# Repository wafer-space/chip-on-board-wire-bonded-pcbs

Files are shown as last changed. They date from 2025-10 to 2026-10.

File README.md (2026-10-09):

# Chip-on-Board Wire-Bonded PCBs

> **Status:** Work in Progress

This repository serves as the primary workspace and documentation hub for [**wafer.space**](https://wafer.space).

Our current padframe and wirebonding layouts follow the [**Tiny Tapeout**](https://tinytapeout.com/) convention of 74 pads.
All ground (GND) connections are tied together in the **Default Breakout COB package**.



---

## First Run

[**wafer.space**](https://wafer.space) completed its **successful first run**, delivering working chip-on-board (COB) packages to customers. The boards below are the actual COB parts that were wire-bonded and shipped as part of Run 1 — real silicon, packaged and ready to drop into a breakout motherboard.

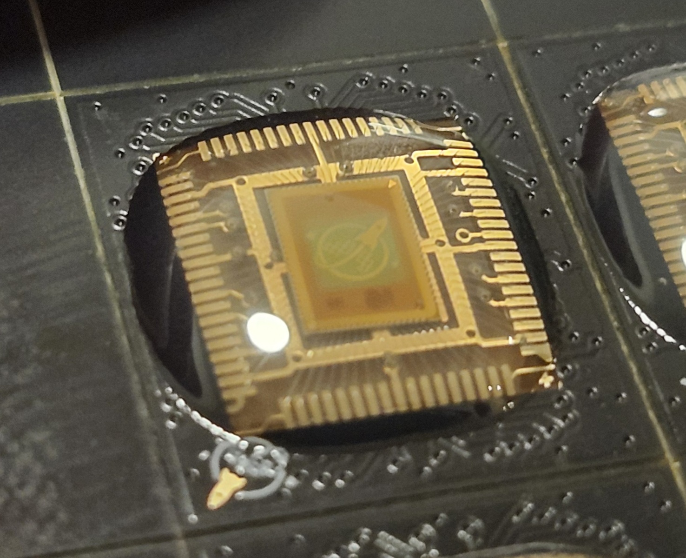
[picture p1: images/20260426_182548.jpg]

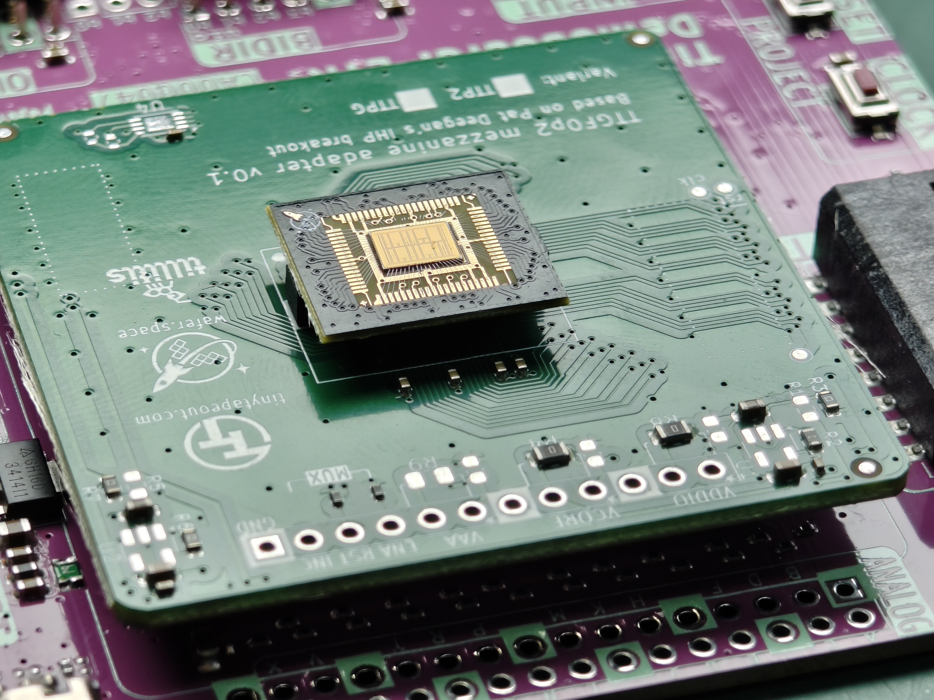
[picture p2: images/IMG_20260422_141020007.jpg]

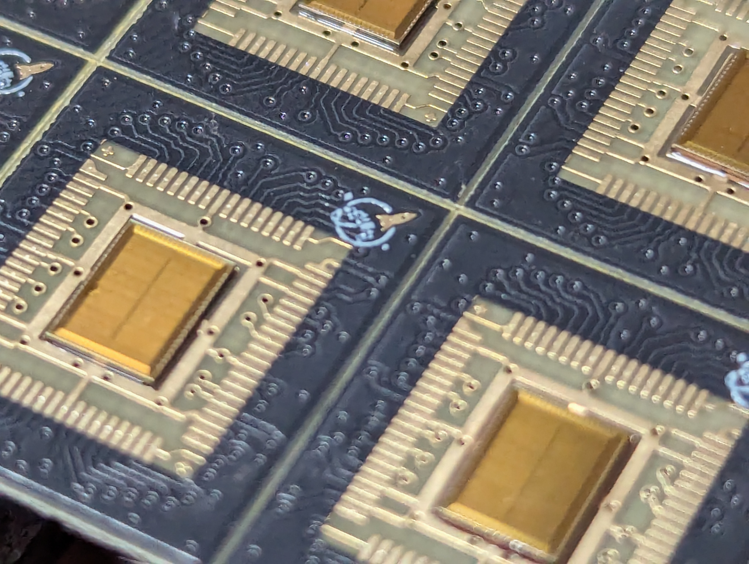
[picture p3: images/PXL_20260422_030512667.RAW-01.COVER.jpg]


See [**Run 1**](./run-1/README.md) for the full padframe reference, pinouts, and design requirements behind these parts.

---

## Run Documentation

Pinouts, connector choices, and footprint dimensions are **run-specific** and documented per run.

* [**Run 1**](./run-1/README.md) — padframe reference / pinouts, example COB layout, mezzanine connectors, and design requirements
  * [Wirebonding detail and design rules](./run-1/wirebonding/README.md)
  * [Example motherboards](./run-1/motherboards/README.md)

---

## Boards

<!-- AUTO-GEN:START -->
<!-- Generated by .github/scripts/gen_docs.py on release. Edits between the AUTO-GEN markers will be overwritten. -->

*Generated for release **unreleased** on 2026-10-09.*

| Run | Board | Preview |
| --- | --- | :---: |
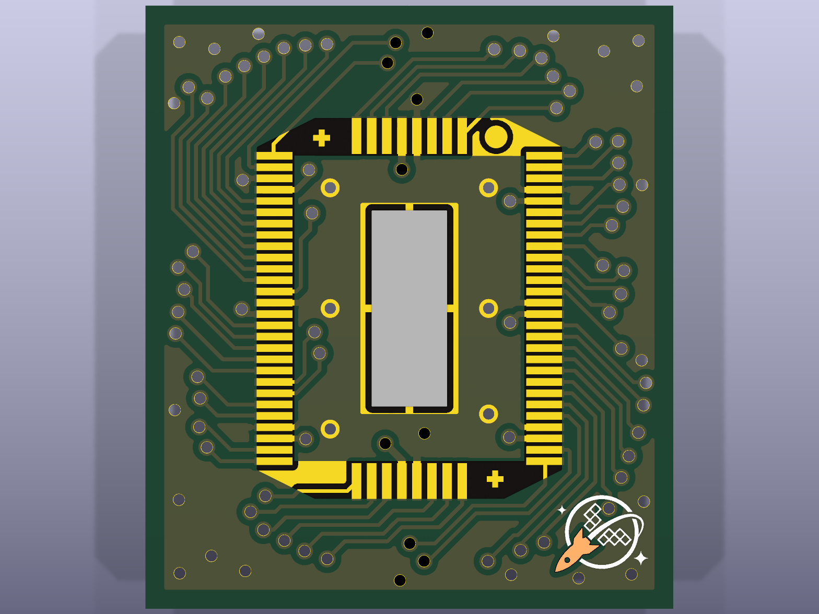
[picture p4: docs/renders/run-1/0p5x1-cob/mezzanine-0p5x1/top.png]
0p5x1-cob / mezzanine-0p5x1
| [Run 1](run-1/README.md) | [0p5x1-cob / mezzanine-0p5x1](run-1/README.md#0p5x1-cob--mezzanine-0p5x1) |  |
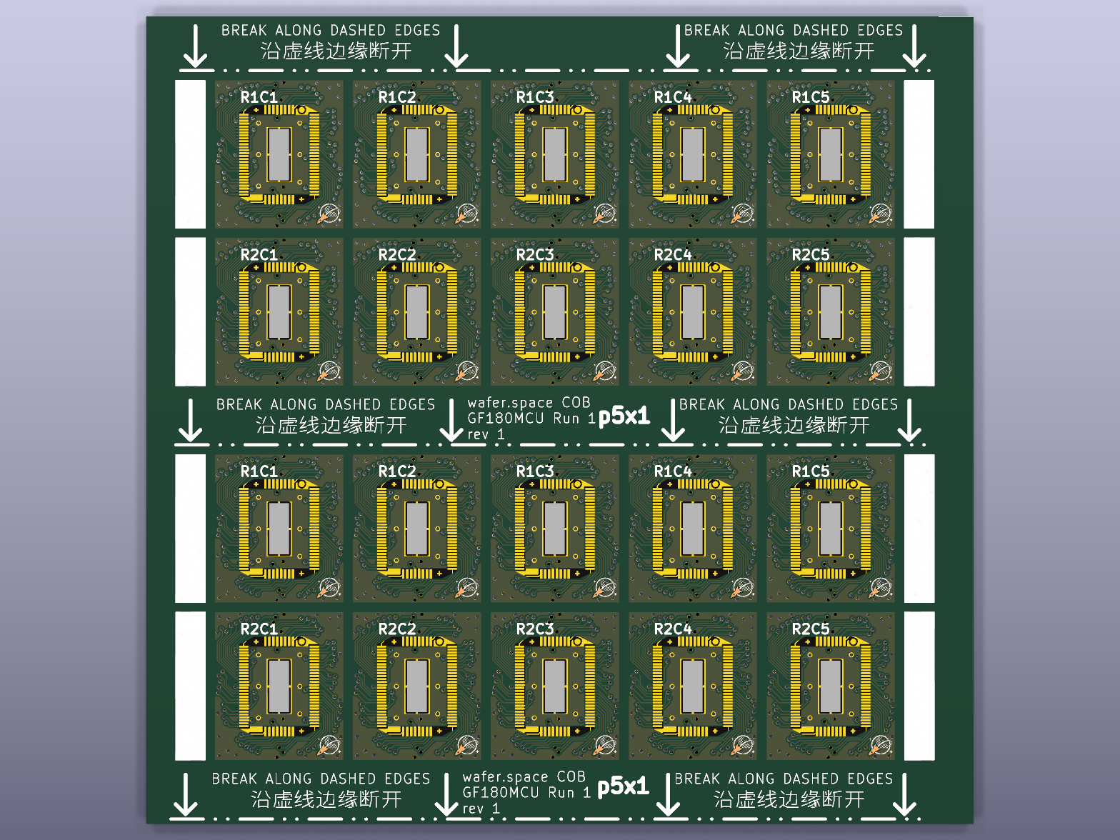
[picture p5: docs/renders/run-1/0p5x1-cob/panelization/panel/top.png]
0p5x1-cob / panelization / panel
| [Run 1](run-1/README.md) | [0p5x1-cob / panelization / panel](run-1/README.md#0p5x1-cob--panelization--panel) |  |
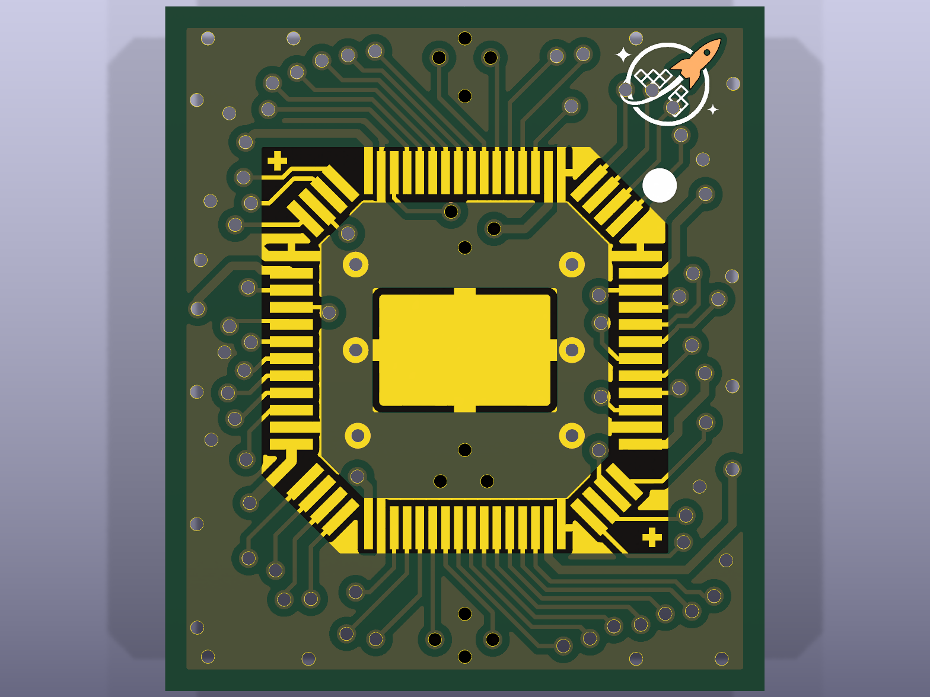
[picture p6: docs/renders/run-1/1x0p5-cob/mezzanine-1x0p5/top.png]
1x0p5-cob / mezzanine-1x0p5
| [Run 1](run-1/README.md) | [1x0p5-cob / mezzanine-1x0p5](run-1/README.md#1x0p5-cob--mezzanine-1x0p5) |  |
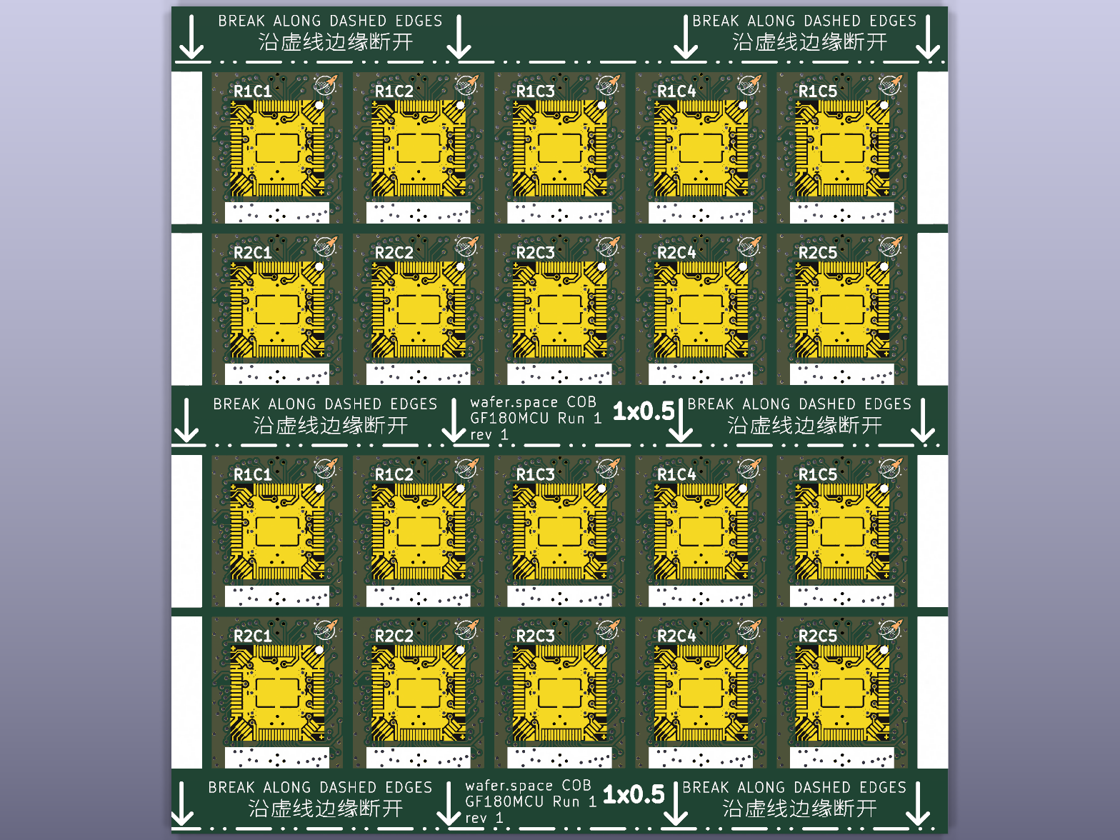
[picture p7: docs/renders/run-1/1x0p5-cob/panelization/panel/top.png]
1x0p5-cob / panelization / panel
| [Run 1](run-1/README.md) | [1x0p5-cob / panelization / panel](run-1/README.md#1x0p5-cob--panelization--panel) |  |
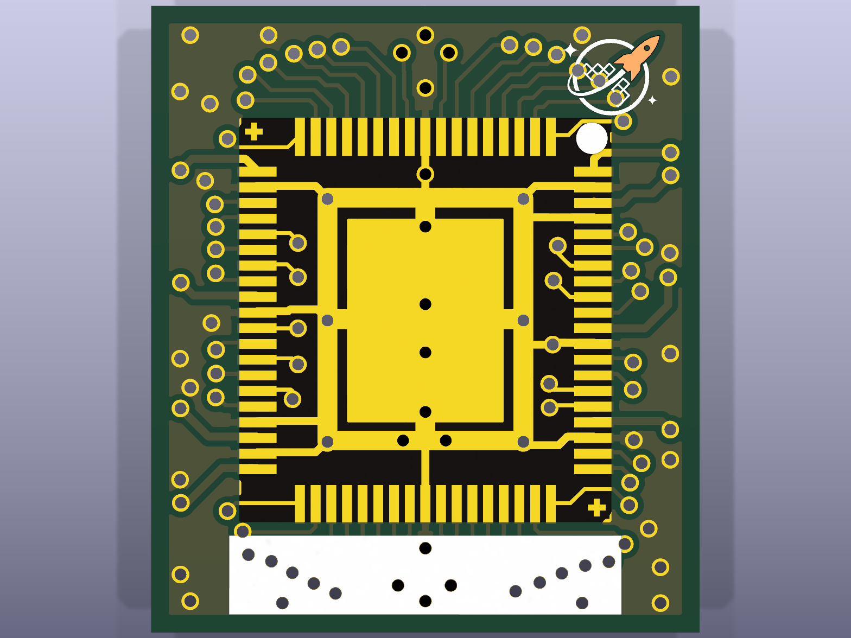
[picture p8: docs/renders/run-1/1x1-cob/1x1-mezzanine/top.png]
1x1-cob / 1x1-mezzanine
| [Run 1](run-1/README.md) | [1x1-cob / 1x1-mezzanine](run-1/README.md#1x1-cob--1x1-mezzanine) |  |
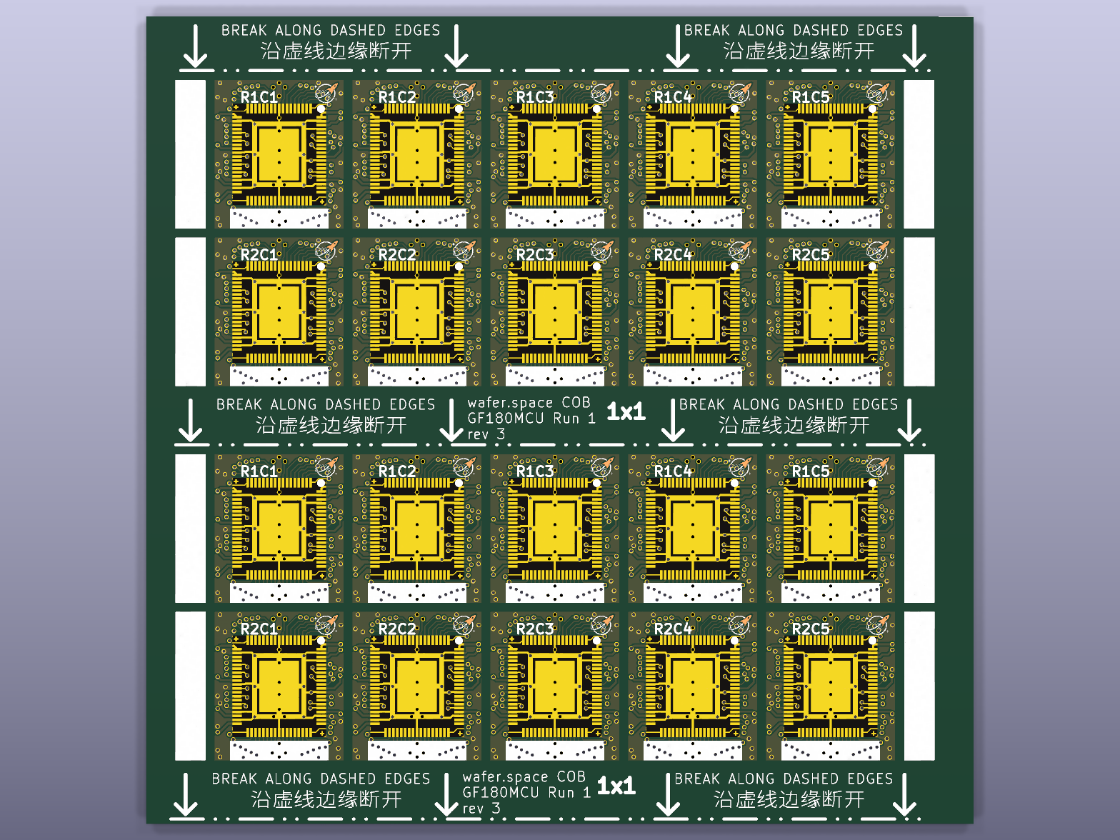
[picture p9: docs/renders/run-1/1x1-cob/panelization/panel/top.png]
1x1-cob / panelization / panel
| [Run 1](run-1/README.md) | [1x1-cob / panelization / panel](run-1/README.md#1x1-cob--panelization--panel) |  |
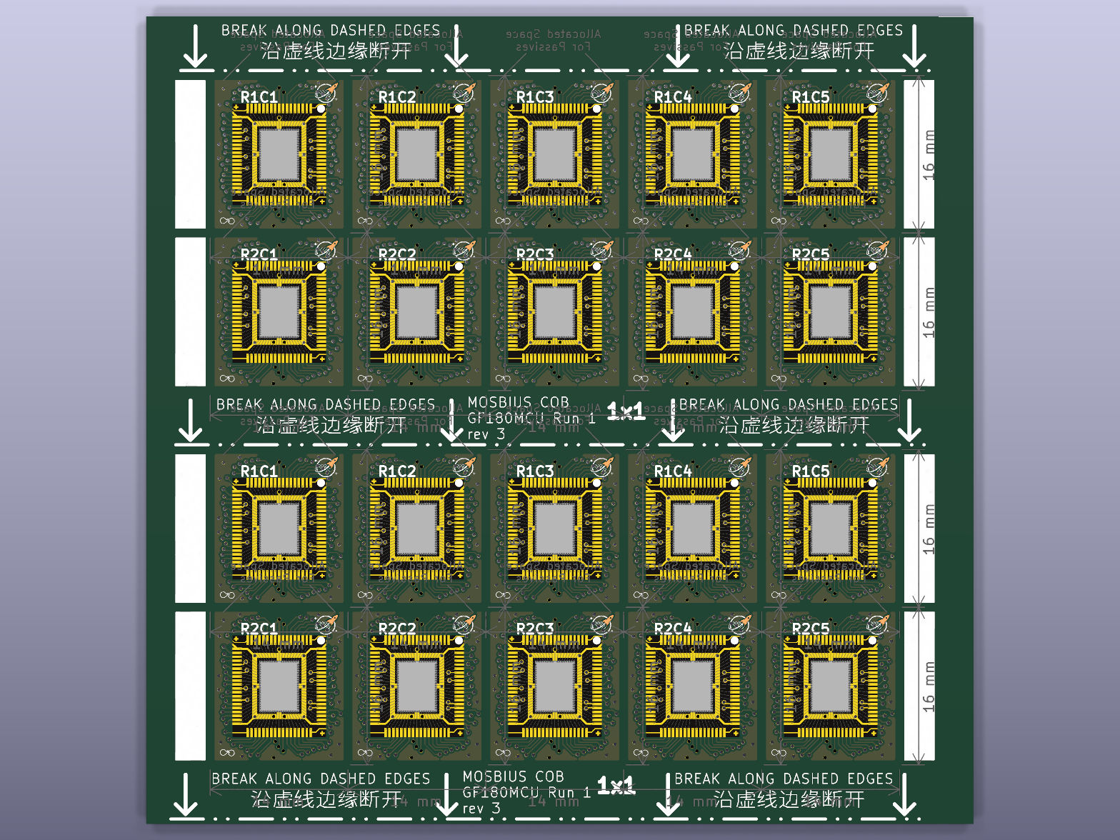
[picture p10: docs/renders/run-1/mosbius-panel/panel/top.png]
mosbius-panel / panel
| [Run 1](run-1/README.md) | [mosbius-panel / panel](run-1/README.md#mosbius-panel--panel) |  |
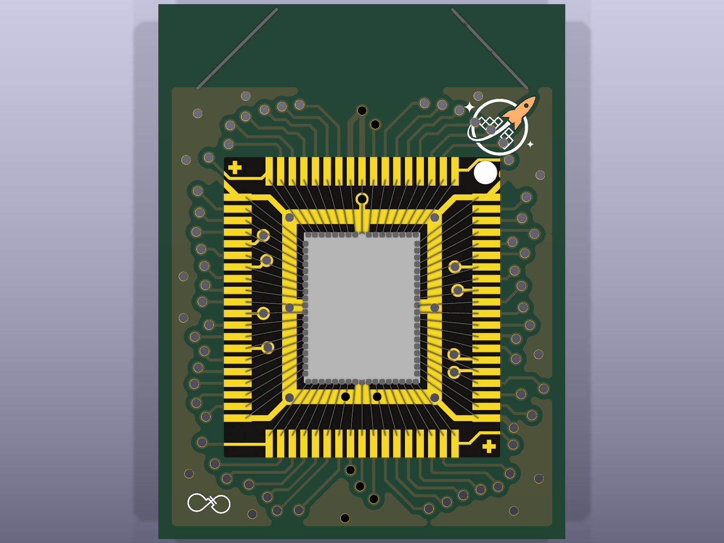
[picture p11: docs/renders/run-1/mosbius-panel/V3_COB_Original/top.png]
mosbius-panel / V3_COB_Original
| [Run 1](run-1/README.md) | [mosbius-panel / V3_COB_Original](run-1/README.md#mosbius-panel--v3_cob_original) |  |
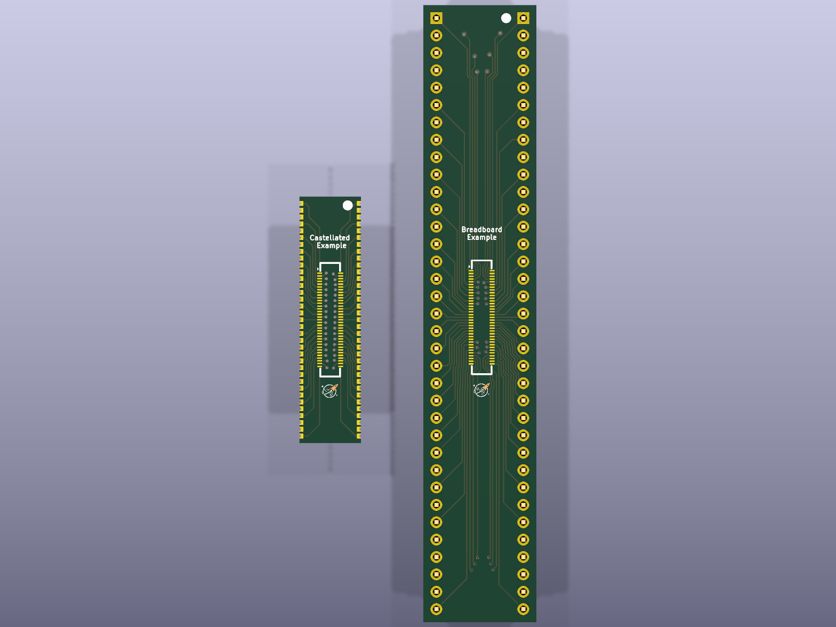
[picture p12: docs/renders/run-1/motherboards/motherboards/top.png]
motherboards / motherboards
| [Run 1](run-1/README.md) | [motherboards / motherboards](run-1/README.md#motherboards--motherboards) |  |
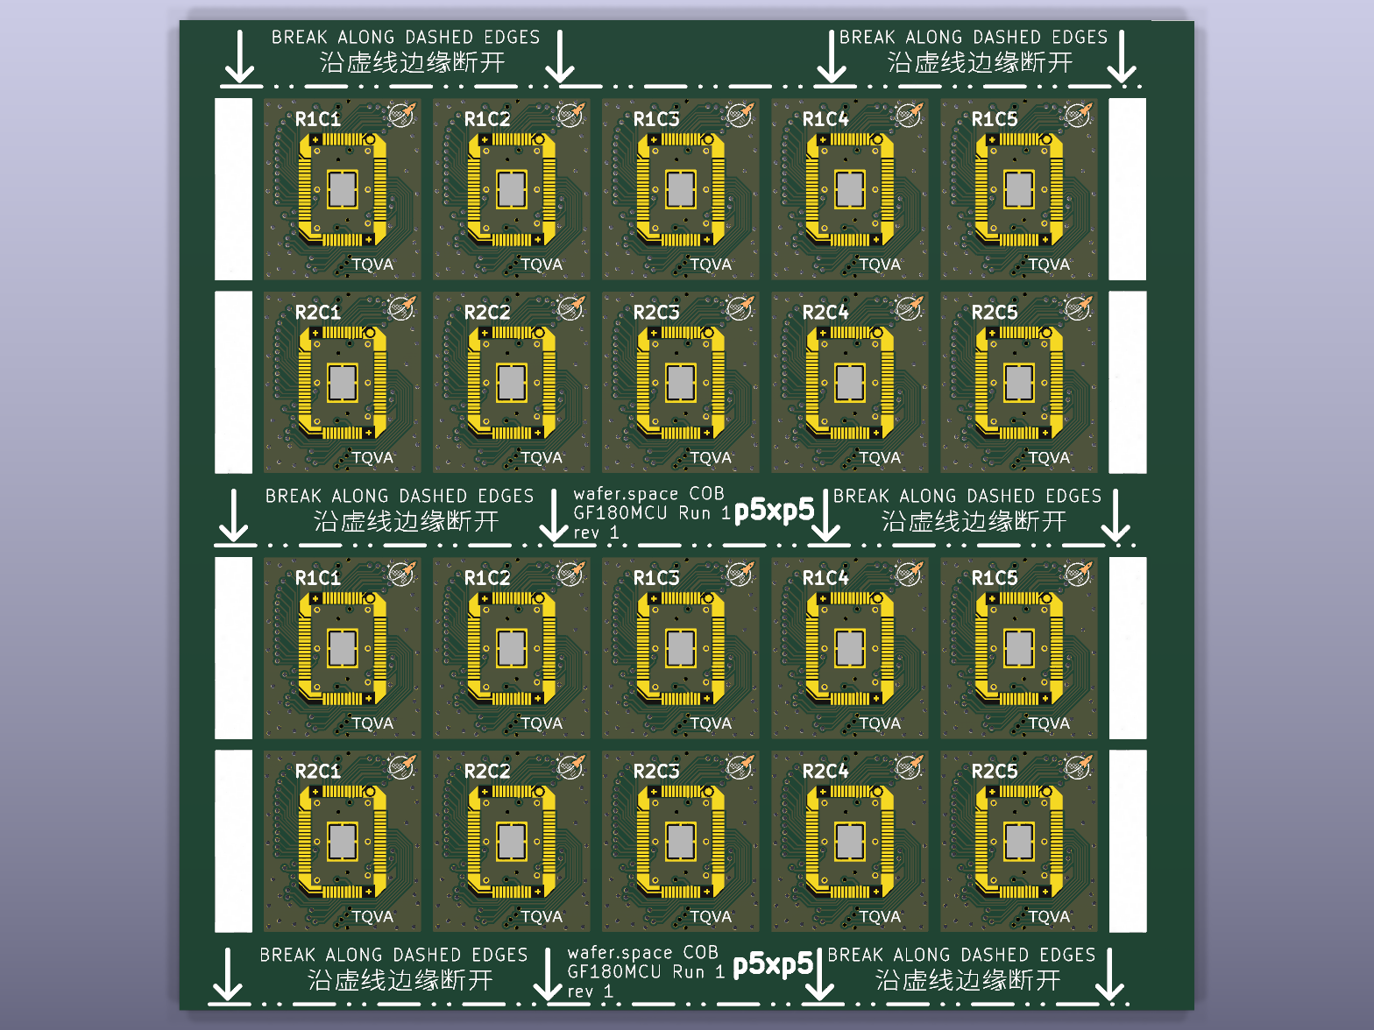
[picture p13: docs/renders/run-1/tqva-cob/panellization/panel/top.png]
tqva-cob / panellization / panel
| [Run 1](run-1/README.md) | [tqva-cob / panellization / panel](run-1/README.md#tqva-cob--panellization--panel) |  |
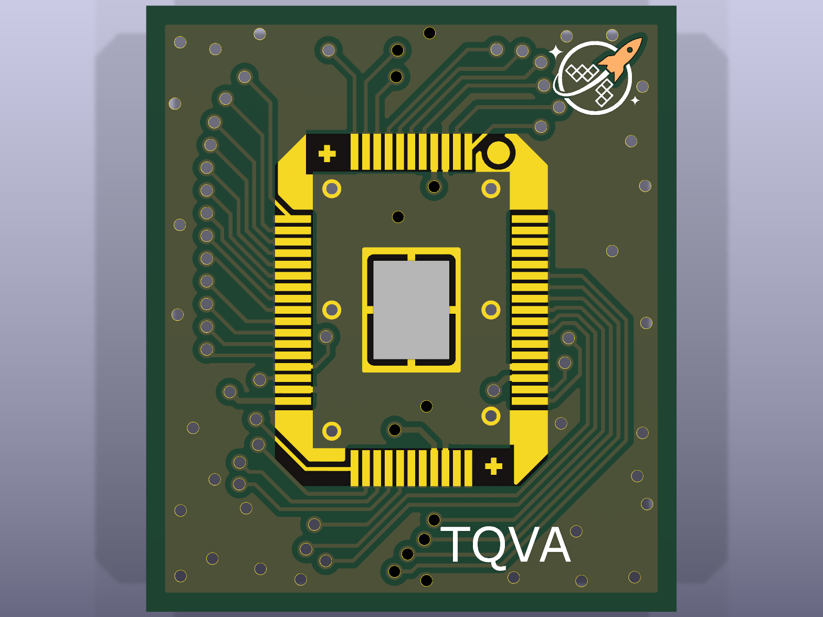
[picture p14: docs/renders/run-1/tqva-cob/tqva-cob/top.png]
tqva-cob / tqva-cob
| [Run 1](run-1/README.md) | [tqva-cob / tqva-cob](run-1/README.md#tqva-cob--tqva-cob) |  |
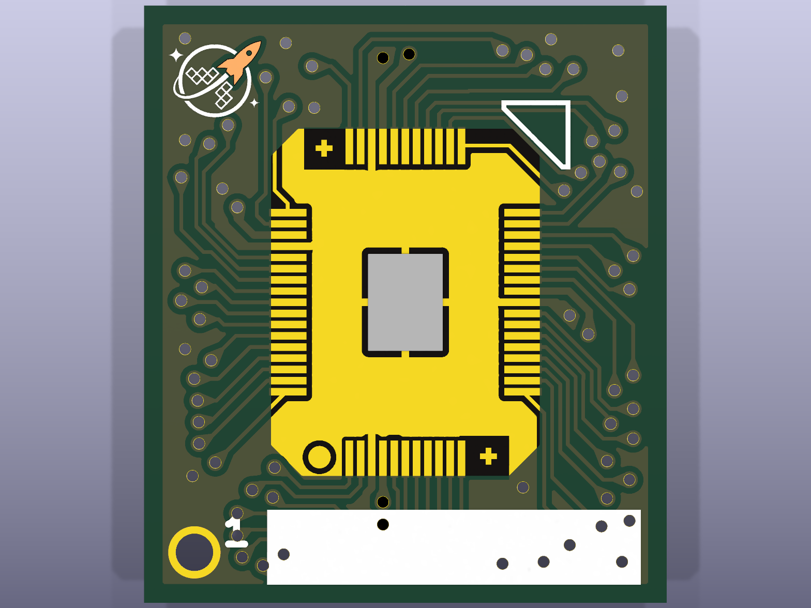
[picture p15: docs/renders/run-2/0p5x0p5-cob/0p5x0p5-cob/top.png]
0p5x0p5-cob / 0p5x0p5-cob
| [Run 2](run-2/README.md) | [0p5x0p5-cob / 0p5x0p5-cob](run-2/README.md#0p5x0p5-cob--0p5x0p5-cob) |  |
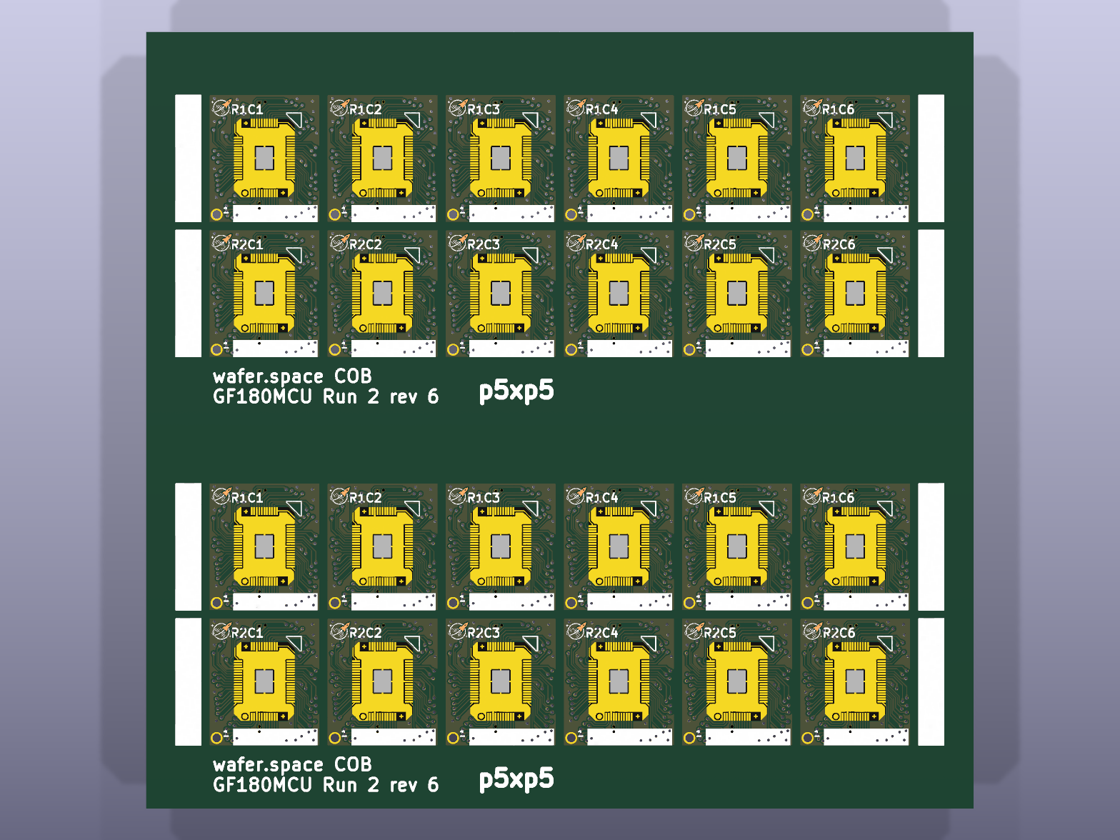
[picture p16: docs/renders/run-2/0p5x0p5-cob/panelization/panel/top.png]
0p5x0p5-cob / panelization / panel
| [Run 2](run-2/README.md) | [0p5x0p5-cob / panelization / panel](run-2/README.md#0p5x0p5-cob--panelization--panel) |  |
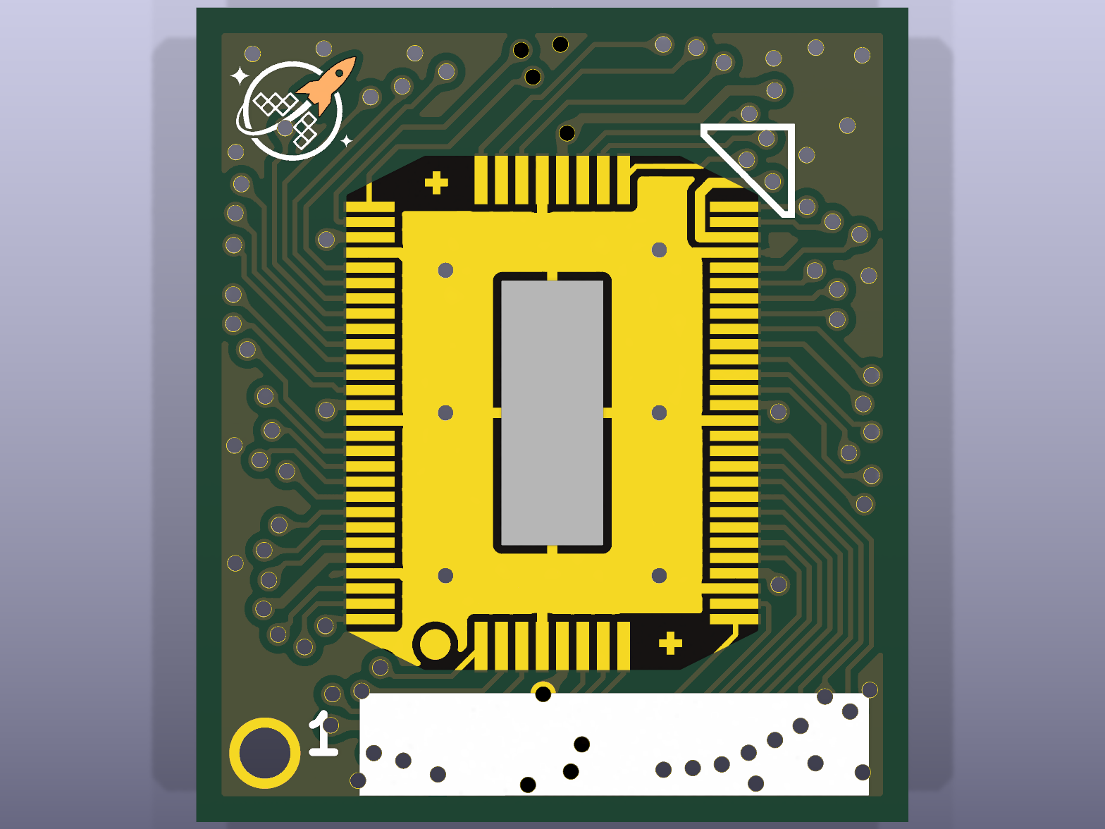
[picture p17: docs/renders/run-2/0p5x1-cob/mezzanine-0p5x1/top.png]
0p5x1-cob / mezzanine-0p5x1
| [Run 2](run-2/README.md) | [0p5x1-cob / mezzanine-0p5x1](run-2/README.md#0p5x1-cob--mezzanine-0p5x1) |  |
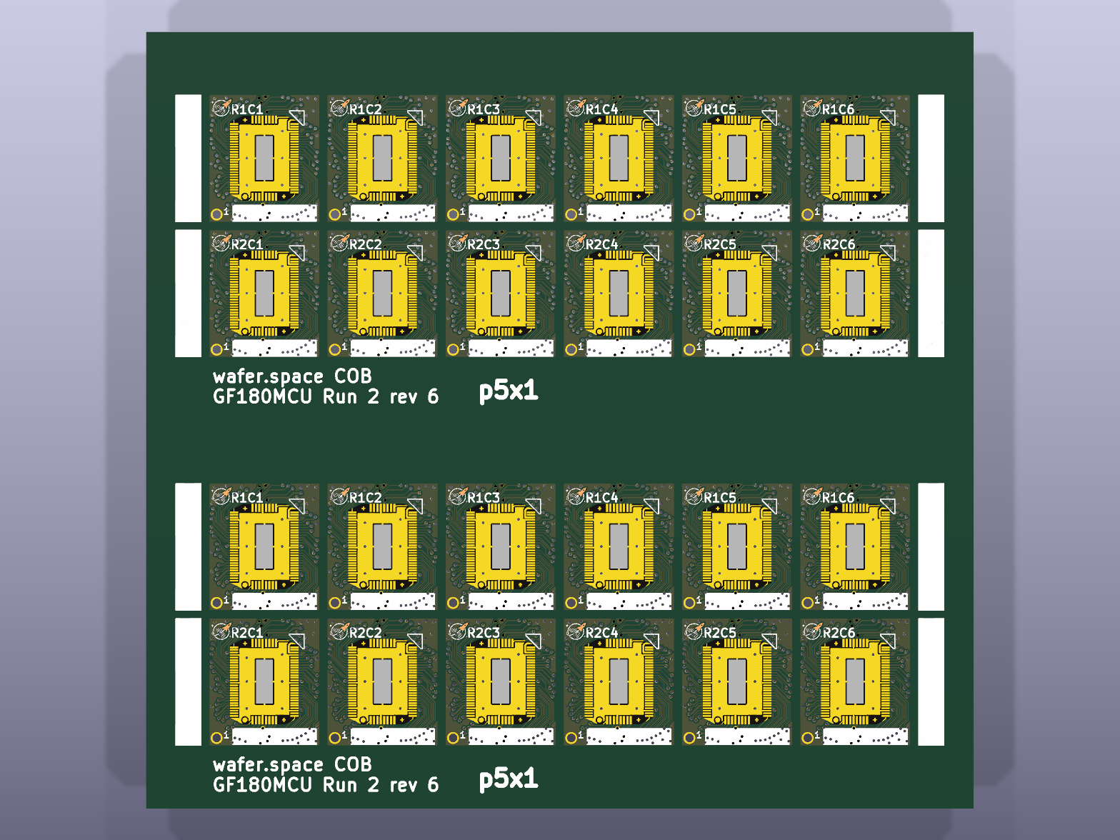
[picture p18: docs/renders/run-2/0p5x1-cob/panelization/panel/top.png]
0p5x1-cob / panelization / panel
| [Run 2](run-2/README.md) | [0p5x1-cob / panelization / panel](run-2/README.md#0p5x1-cob--panelization--panel) |  |
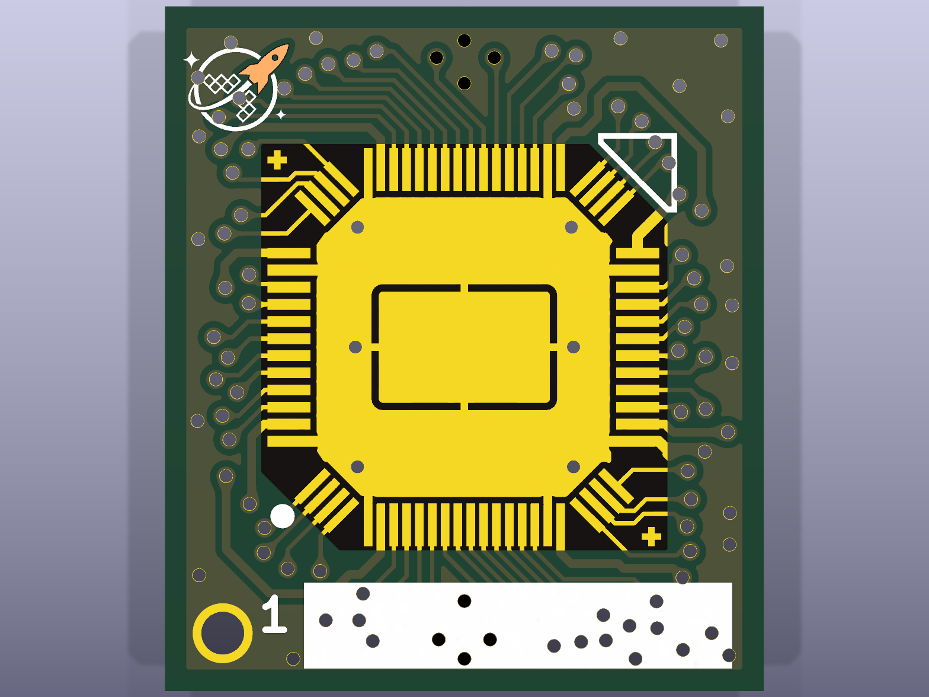
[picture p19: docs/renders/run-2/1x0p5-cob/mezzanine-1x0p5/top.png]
1x0p5-cob / mezzanine-1x0p5
| [Run 2](run-2/README.md) | [1x0p5-cob / mezzanine-1x0p5](run-2/README.md#1x0p5-cob--mezzanine-1x0p5) |  |
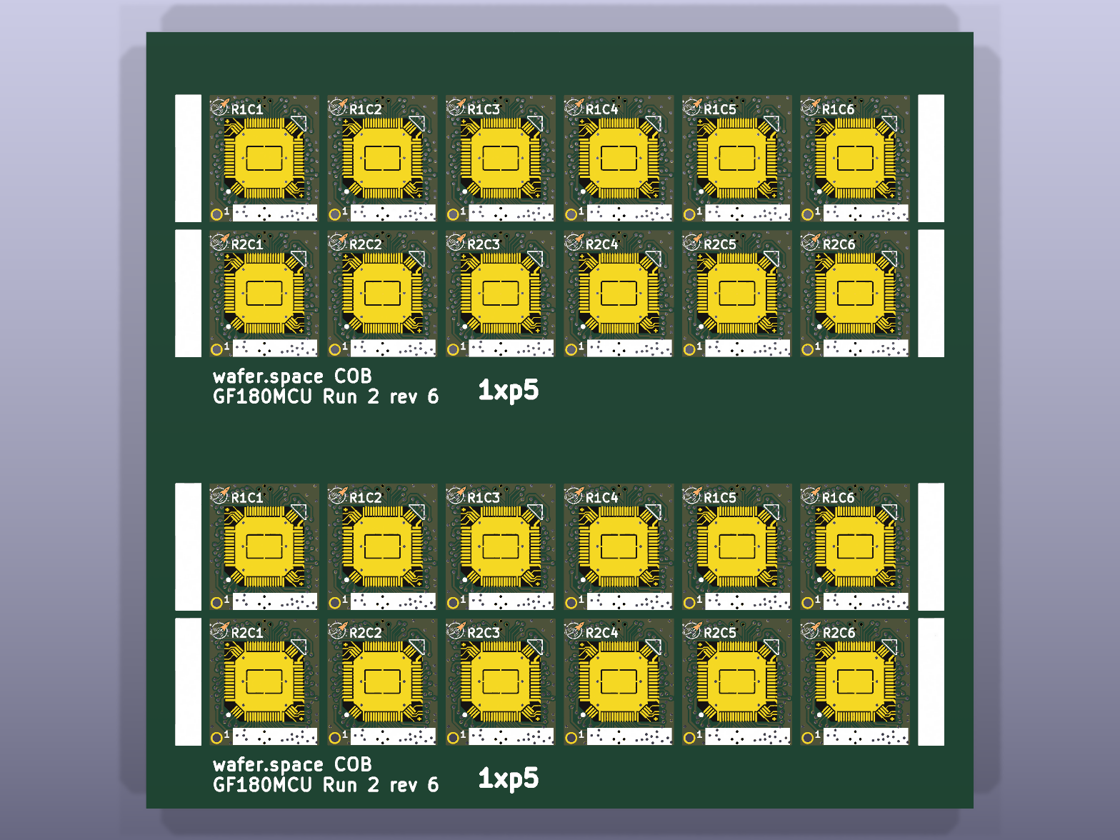
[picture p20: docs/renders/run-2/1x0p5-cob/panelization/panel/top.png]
1x0p5-cob / panelization / panel
| [Run 2](run-2/README.md) | [1x0p5-cob / panelization / panel](run-2/README.md#1x0p5-cob--panelization--panel) |  |
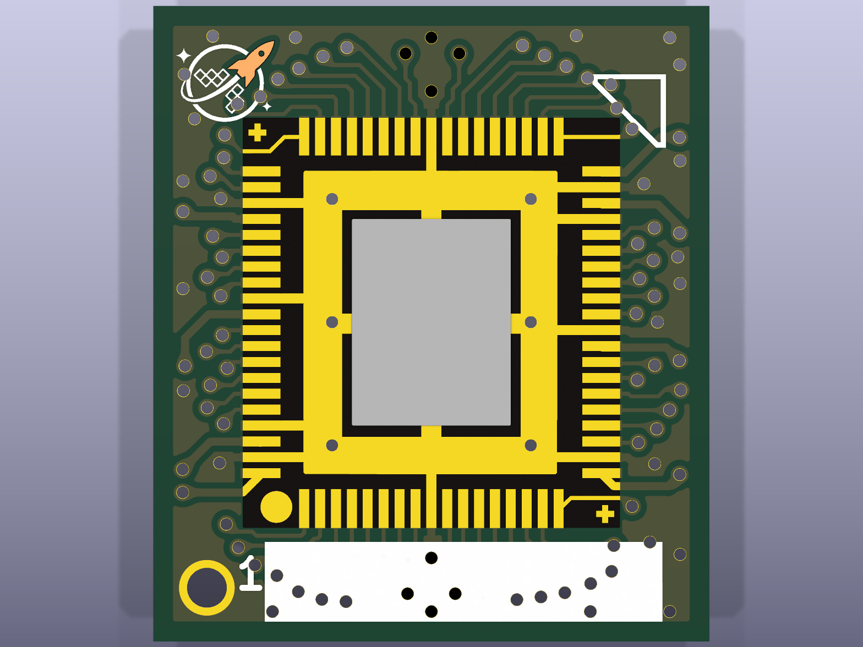
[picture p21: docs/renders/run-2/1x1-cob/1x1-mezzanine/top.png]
1x1-cob / 1x1-mezzanine
| [Run 2](run-2/README.md) | [1x1-cob / 1x1-mezzanine](run-2/README.md#1x1-cob--1x1-mezzanine) |  |
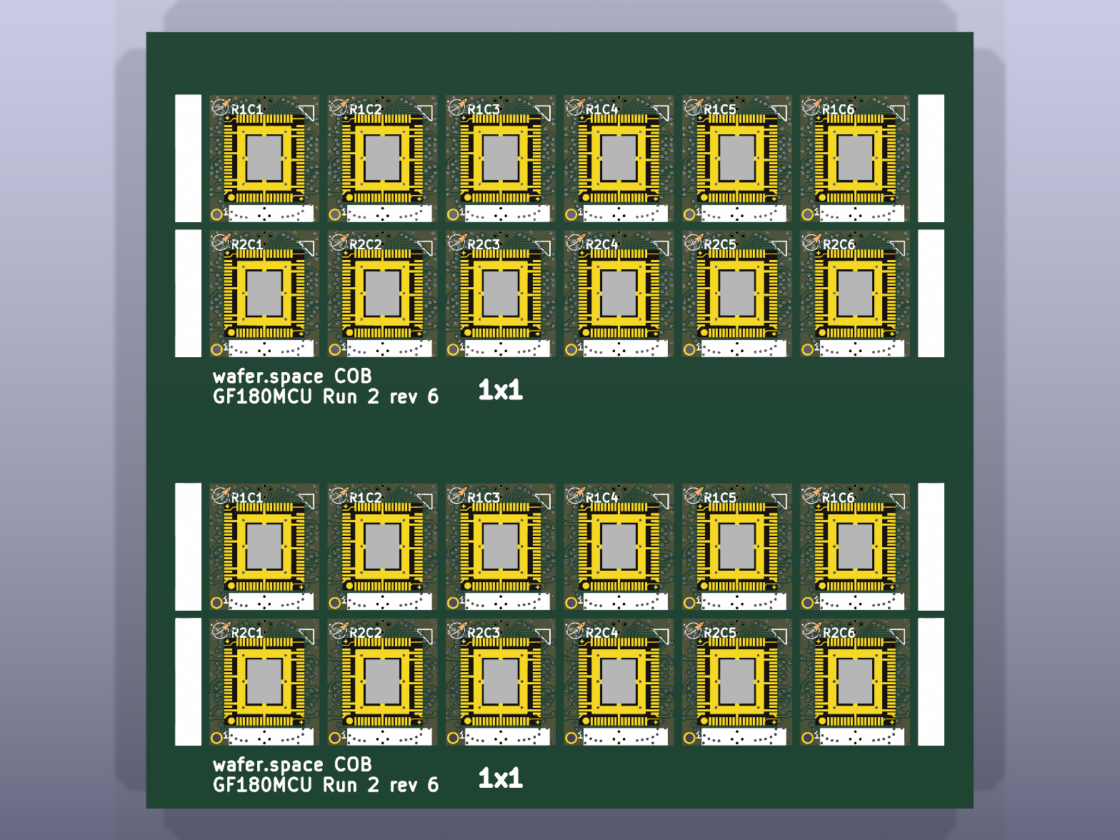
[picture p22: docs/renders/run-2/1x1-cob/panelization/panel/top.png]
1x1-cob / panelization / panel
| [Run 2](run-2/README.md) | [1x1-cob / panelization / panel](run-2/README.md#1x1-cob--panelization--panel) |  |
<!-- AUTO-GEN:END -->

---

## Example Motherboards

We provide example **breakout motherboard** designs that mate with the COB packages via the 70-pin mezzanine connector. See the [**Motherboards directory**](./run-1/motherboards/README.md) for KiCad schematics, layouts, and symbols.

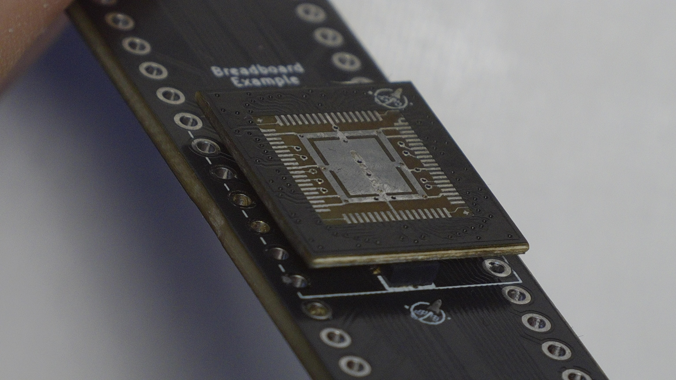
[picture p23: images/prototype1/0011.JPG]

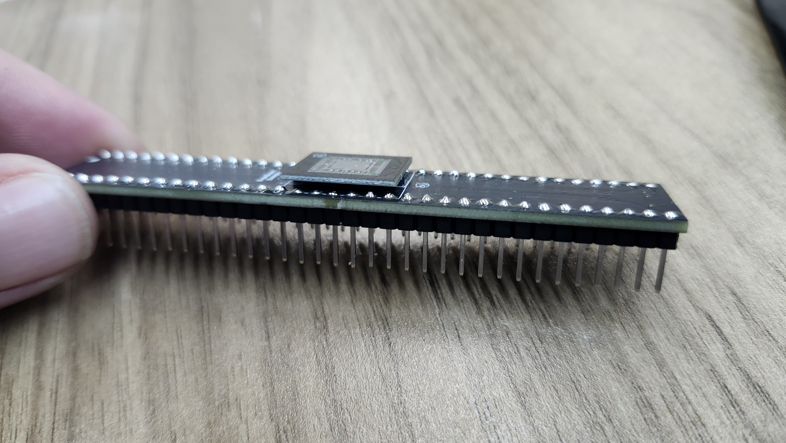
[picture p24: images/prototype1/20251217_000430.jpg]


---

### 70-Pin Mezzanine Connector Symbol

The **mezzanine connector symbol** provides a 1:1 pin mapping to the 70-pin default layout. You can find these symbols in the [Motherboards examples](./run-1/motherboards/README.md). 
All pins are aliased to match [Tiny Tapeout](https://tinytapeout.com/) naming conventions.

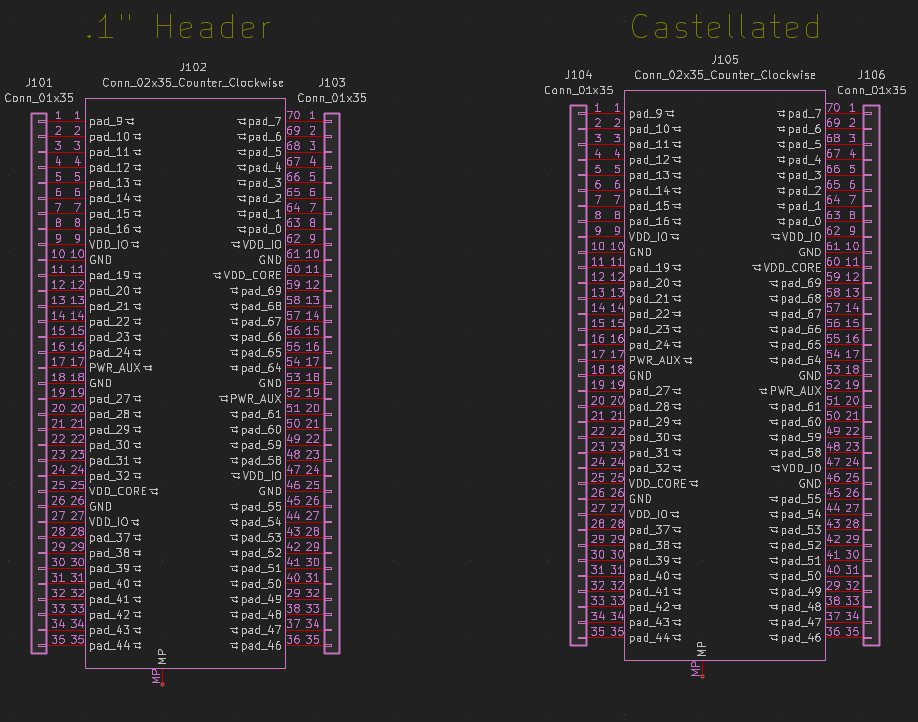
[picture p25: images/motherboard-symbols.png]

*Default 70-pin mezzanine COB breakout symbol*

We also provide an alternate version that organizes pins by signal type. Ideal for Tiny Tapeout breakout motherboard designs.

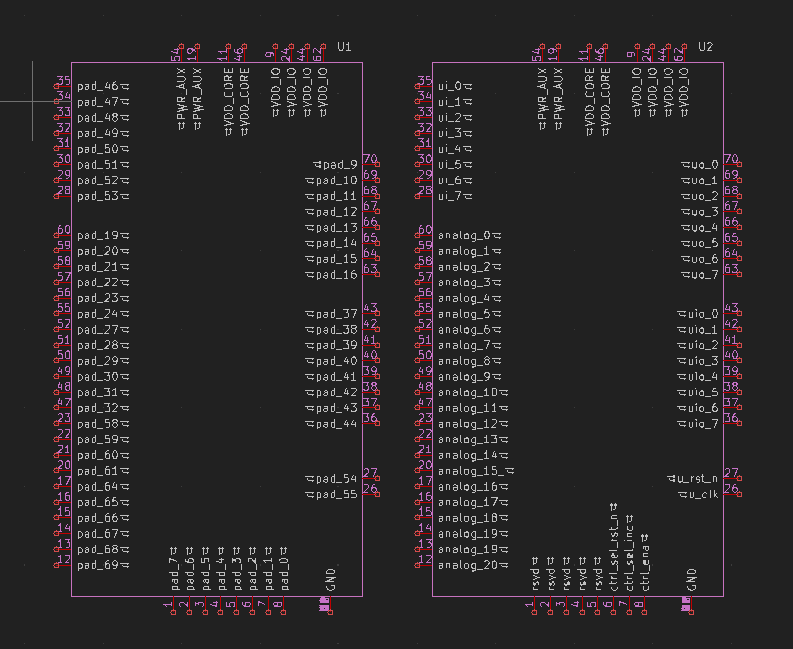
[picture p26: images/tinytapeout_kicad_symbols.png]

*Default 70-pin mezzanine COB breakout symbol TT version*

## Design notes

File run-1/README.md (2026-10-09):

# Run 1

This directory holds the design files for **Run 1** of the [wafer.space](https://wafer.space)
chip-on-board (COB) breakouts.

> **Note:** The pinouts, connector choices, and footprint dimensions documented here are
> **specific to this run** and are expected to change in future runs. Treat this page as the
> source of truth for Run 1 only.

## Contents

| Directory | Description |
| --- | --- |
| [`1x1-cob/`](1x1-cob/) | 14 mm × 16 mm 74-pad / 70-pin mezzanine COB breakout |
| [`1x0p5-cob/`](1x0p5-cob/) · [`0p5x1-cob/`](0p5x1-cob/) | Half-slot COB variants |
| [`wirebonding/`](wirebonding/README.md) | Wirebonding layout and design rules |
| [`motherboards/`](motherboards/README.md) | Example breakout motherboards |

---

## Padframe Reference

Our current padframe and wirebonding layouts follow the [**Tiny Tapeout**](https://tinytapeout.com/)
convention of 74 pads. All ground (GND) connections are tied together in the
**Default Breakout COB package**.

| Bond Pad | Breakout Pad | Default | TT Function |
| --- | --- | --- | --- |
| 0 | 1 | user_defined | ctrl_ena |
| 1 | 2 | user_defined | ctrl_sel_inc |
| 2 | 3 | user_defined | ctrl_sel_rst_n |
| 3–7 | 4–8 | user_defined | rsvd |
| 8 | 9 | <span style="color:gray; font-weight:bold;">GND IO</span>  | <span style="color:gray; font-weight:bold;">GND IO</span>  |
| 9–16 | 10–17 | user_defined | uo[0–7] |
| 17 | 18 | <span style="color:red; font-weight:bold;">VDD IO</span> | <span style="color:red; font-weight:bold;">VDD IO</span> |
| 18 | 19 | <span style="color:gray; font-weight:bold;">GND IO</span>  | <span style="color:gray; font-weight:bold;">GND IO</span>  |
| 19–24 | 20–25 | user_defined | analog[0–5] |
| 25 | 26 | <span style="color:blue; font-weight:bold;">PWR Aux</span> | <span style="color:blue; font-weight:bold;">PWR Aux</span> |
| 26–72 | 27–73 | *(see full table for details)* | — |
| 73 | 74 | <span style="color:red; font-weight:bold;">VDD IO</span> | <span style="color:red; font-weight:bold;">VDD IO</span> |

> For the complete mapping and color-coded reference, please refer to this [spreadsheet](https://docs.google.com/spreadsheets/d/1pI2BAEWEexXcXN3vah3SR85zPIV6eAXPGXc2bcvoSGU)

---

## Example COB Layout

> *Note: Pin numbering and naming conventions are still evolving.*




Space has been allocated for optional components such as decoupling capacitors and other passive elements.

**Proposed Mezzanine Connectors:**

* 70-pin, 0.4 mm pitch: [LCSC C19089236](https://www.lcsc.com/product-detail/C19089236.html)
* Mating connector: [LCSC C19089262](https://www.lcsc.com/product-detail/C19089262.html)

---

## Default KiCad Symbols

We have developed several **KiCad symbols** to support design and integration with our COB layouts.

The **pad mapping symbol** corresponds to the default 74-pad wirebonding padframe and [default configuration](https://github.com/wafer-space/gf180mcu-project-template/blob/main/librelane/config.yaml) from the [**GF180MCU Project Template**](https://github.com/wafer-space/gf180mcu-project-template).

> Some users have suggested reducing the number of ground and power pads. If there is sufficient demand, an alternate default configuration will be created.
> Join the discussion on our [**Discord server**](https://discord.gg/43y2t53jpE).

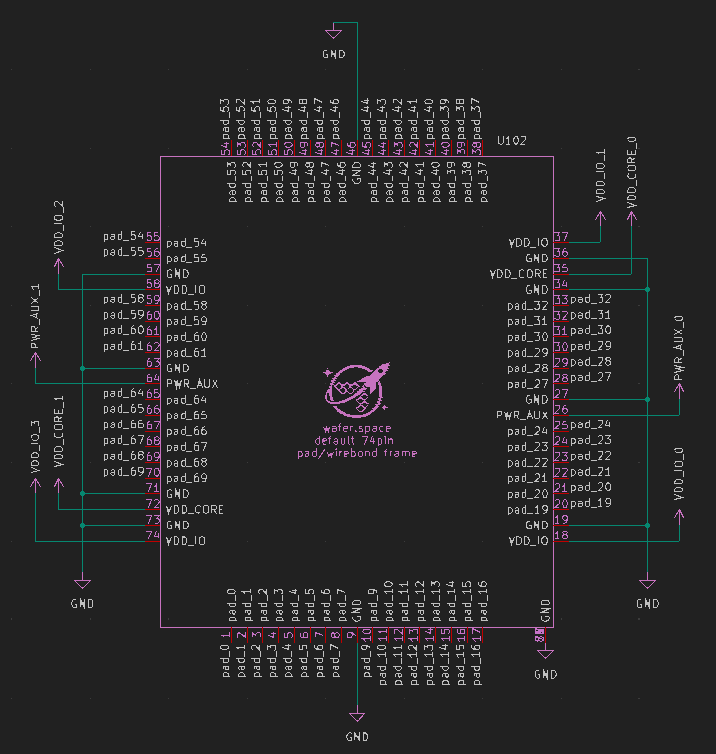
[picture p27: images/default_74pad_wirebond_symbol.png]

*Default 74-pad wirebonding padframe*
---

## Default Design Requirements

To maintain compatibility across projects, **default breakouts** must share:

* The same **wirebonding layout**
* The same **PCB footprint** (14 mm × 16 mm)
* The same **connector position** (if applicable)

Traces, signal types, and net assignments are **user-definable**.

---

<!-- AUTO-GEN:START -->
<!-- Generated by .github/scripts/gen_docs.py on release. Edits between the AUTO-GEN markers will be overwritten. -->

## Board Renders

*Generated for release **unreleased** on 2026-10-09.*

### 0p5x1-cob / mezzanine-0p5x1

| 3D top | 3D bottom |
| :---: | :---: |
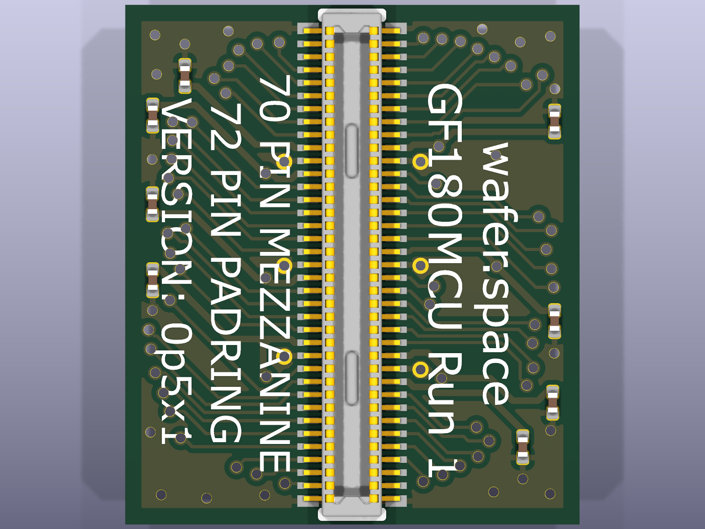
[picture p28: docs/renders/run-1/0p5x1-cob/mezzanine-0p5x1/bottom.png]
bottom render
| top render |  |

| Front layers | Back layers (mirrored) |
| :---: | :---: |
| front layers | back layers |

[PCB](0p5x1-cob/mezzanine-0p5x1.kicad_pcb) · [Schematic source](0p5x1-cob/mezzanine-0p5x1.kicad_sch) · [Schematic PDF](../docs/renders/run-1/0p5x1-cob/mezzanine-0p5x1/schematic.pdf)

### 0p5x1-cob / panelization / panel

| 3D top | 3D bottom |
| :---: | :---: |
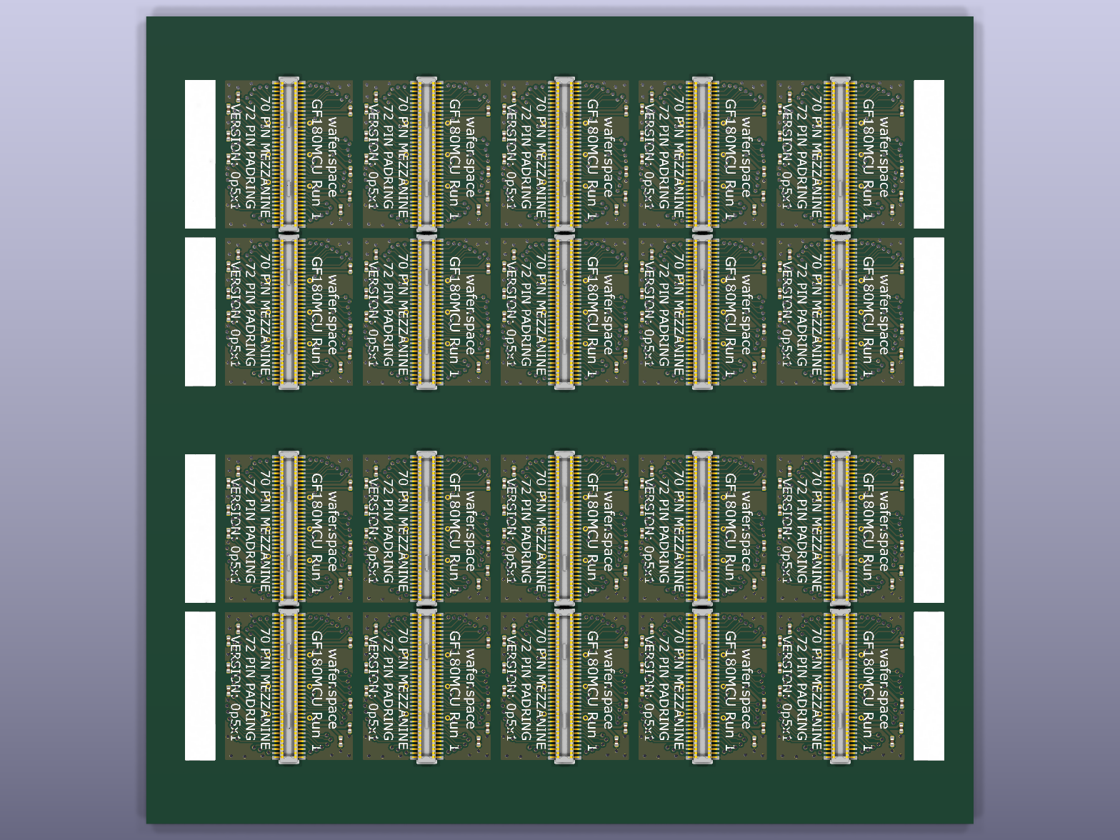
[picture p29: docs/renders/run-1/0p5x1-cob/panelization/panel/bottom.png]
bottom render
| top render |  |

| Front layers | Back layers (mirrored) |
| :---: | :---: |
| front layers | back layers |

[PCB](0p5x1-cob/panelization/panel.kicad_pcb)

### 1x0p5-cob / mezzanine-1x0p5

| 3D top | 3D bottom |
| :---: | :---: |
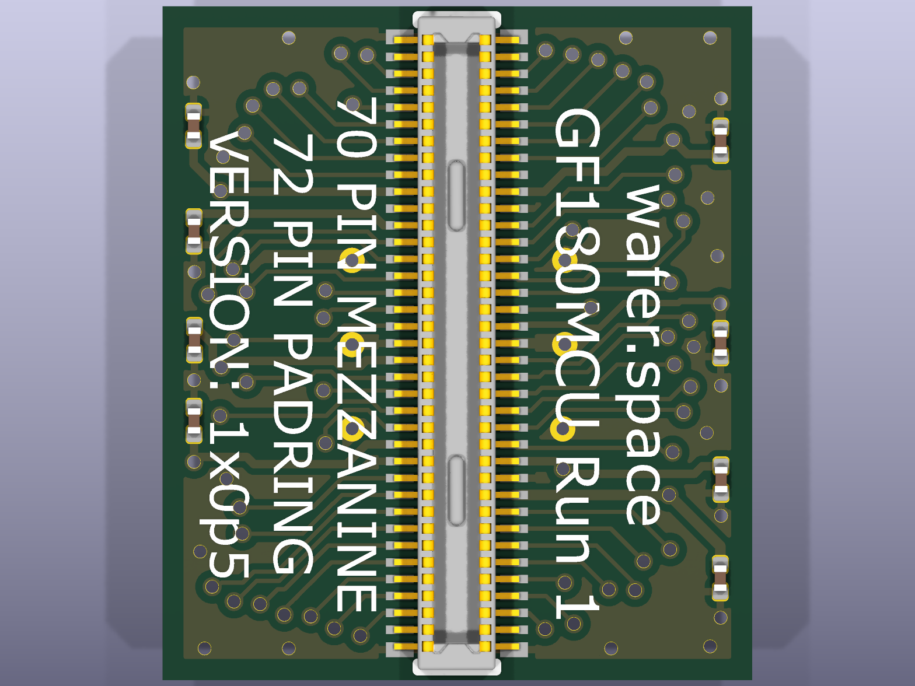
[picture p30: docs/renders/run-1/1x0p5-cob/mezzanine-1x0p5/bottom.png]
bottom render
| top render |  |

| Front layers | Back layers (mirrored) |
| :---: | :---: |
| front layers | back layers |

[PCB](1x0p5-cob/mezzanine-1x0p5.kicad_pcb) · [Schematic source](1x0p5-cob/mezzanine-1x0p5.kicad_sch) · [Schematic PDF](../docs/renders/run-1/1x0p5-cob/mezzanine-1x0p5/schematic.pdf)

### 1x0p5-cob / panelization / panel

| 3D top | 3D bottom |
| :---: | :---: |
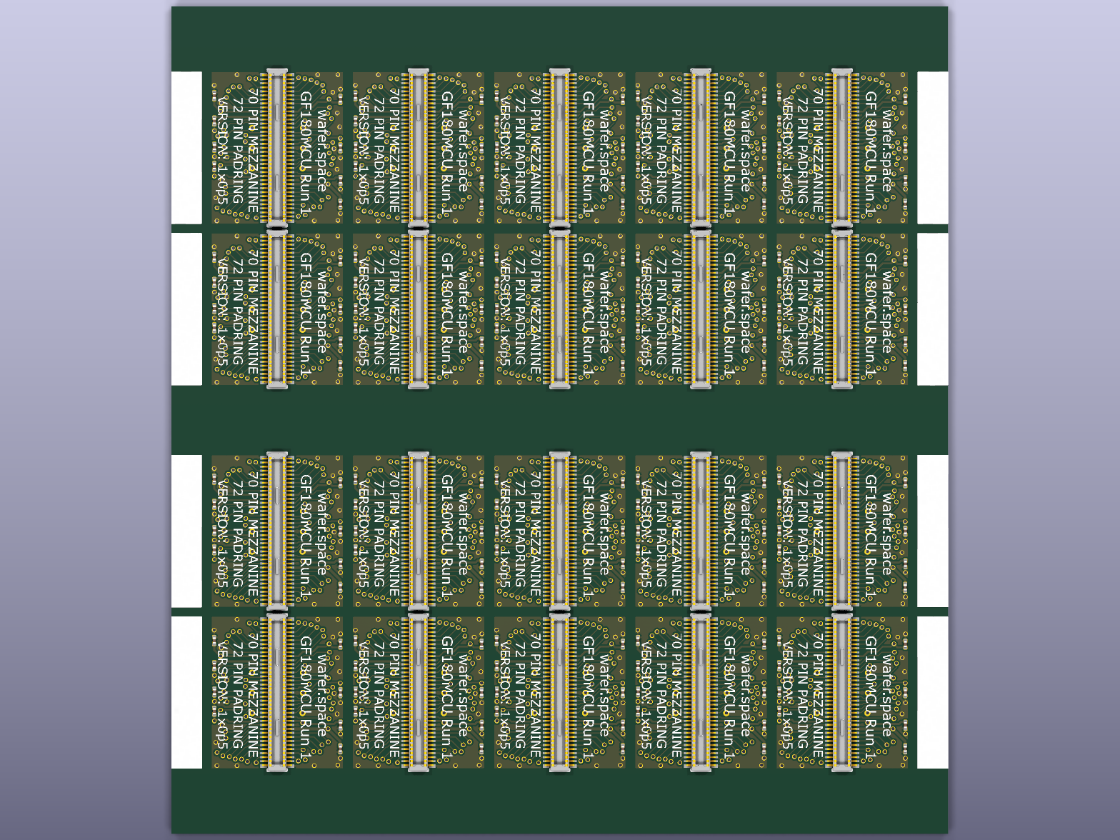
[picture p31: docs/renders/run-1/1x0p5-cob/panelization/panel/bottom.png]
bottom render
| top render |  |

| Front layers | Back layers (mirrored) |
| :---: | :---: |
| front layers | back layers |

[PCB](1x0p5-cob/panelization/panel.kicad_pcb)

### 1x1-cob / 1x1-mezzanine

| 3D top | 3D bottom |
| :---: | :---: |
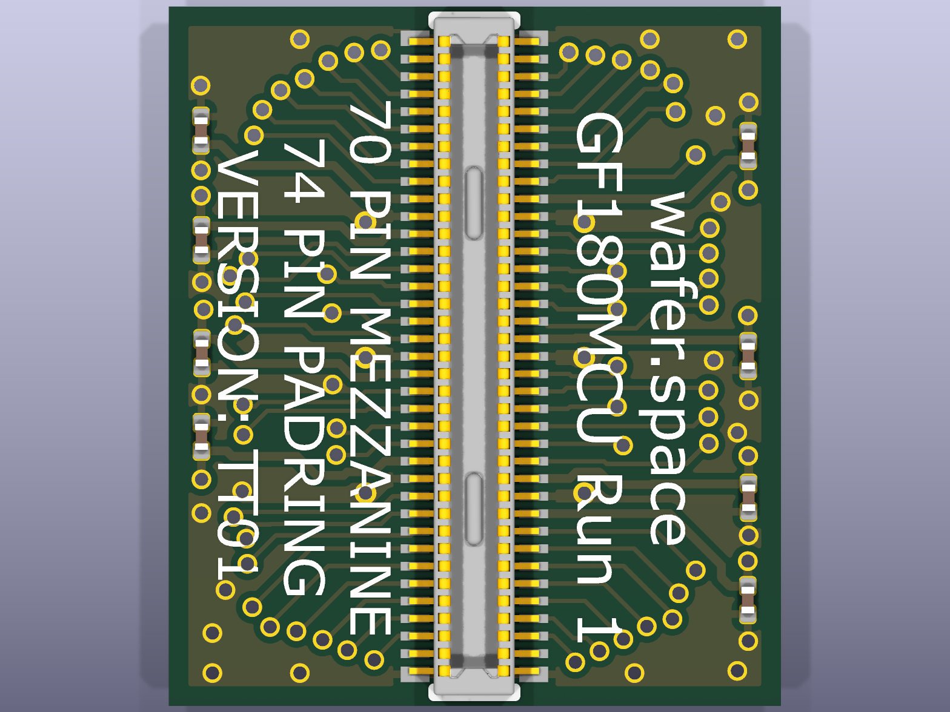
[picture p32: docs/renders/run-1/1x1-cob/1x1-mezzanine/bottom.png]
bottom render
| top render |  |

| Front layers | Back layers (mirrored) |
| :---: | :---: |
| front layers | back layers |

[PCB](1x1-cob/1x1-mezzanine.kicad_pcb) · [Schematic source](1x1-cob/1x1-mezzanine.kicad_sch) · [Schematic PDF](../docs/renders/run-1/1x1-cob/1x1-mezzanine/schematic.pdf)

### 1x1-cob / panelization / panel

| 3D top | 3D bottom |
| :---: | :---: |
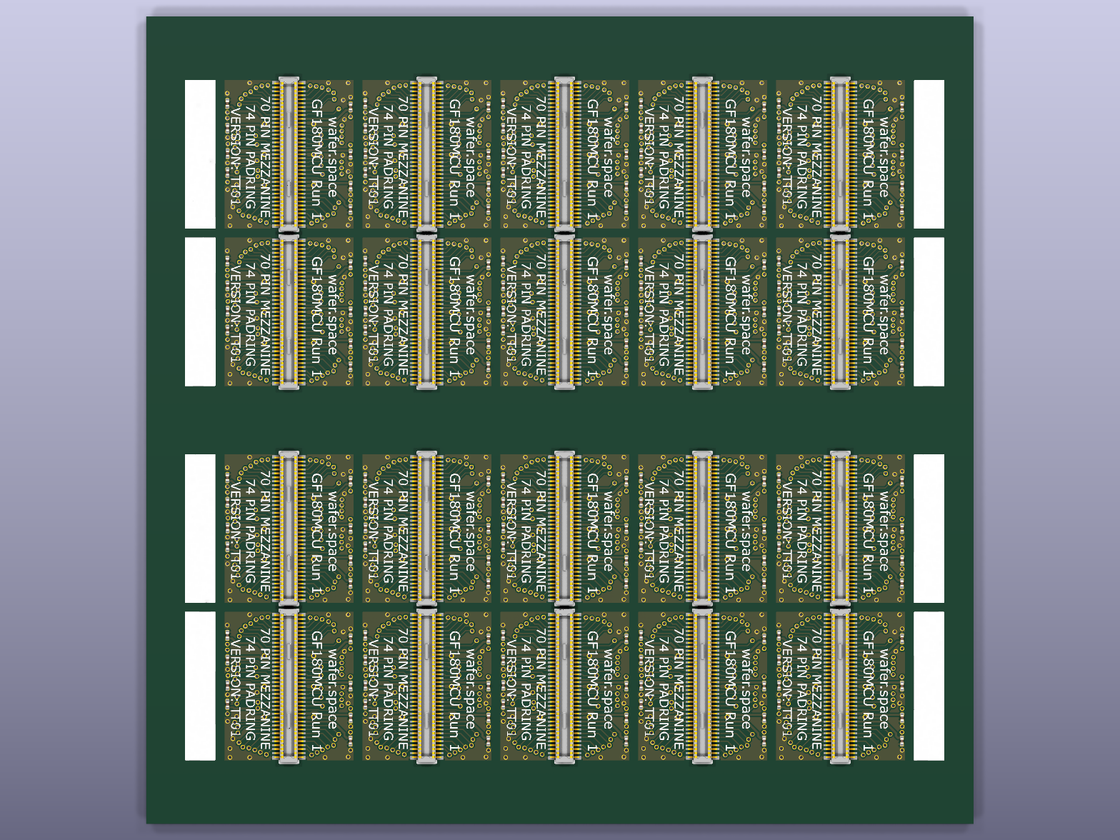
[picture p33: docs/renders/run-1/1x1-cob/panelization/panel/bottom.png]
bottom render
| top render |  |

| Front layers | Back layers (mirrored) |
| :---: | :---: |
| front layers | back layers |

[PCB](1x1-cob/panelization/panel.kicad_pcb)

### mosbius-panel / panel

| 3D top | 3D bottom |
| :---: | :---: |
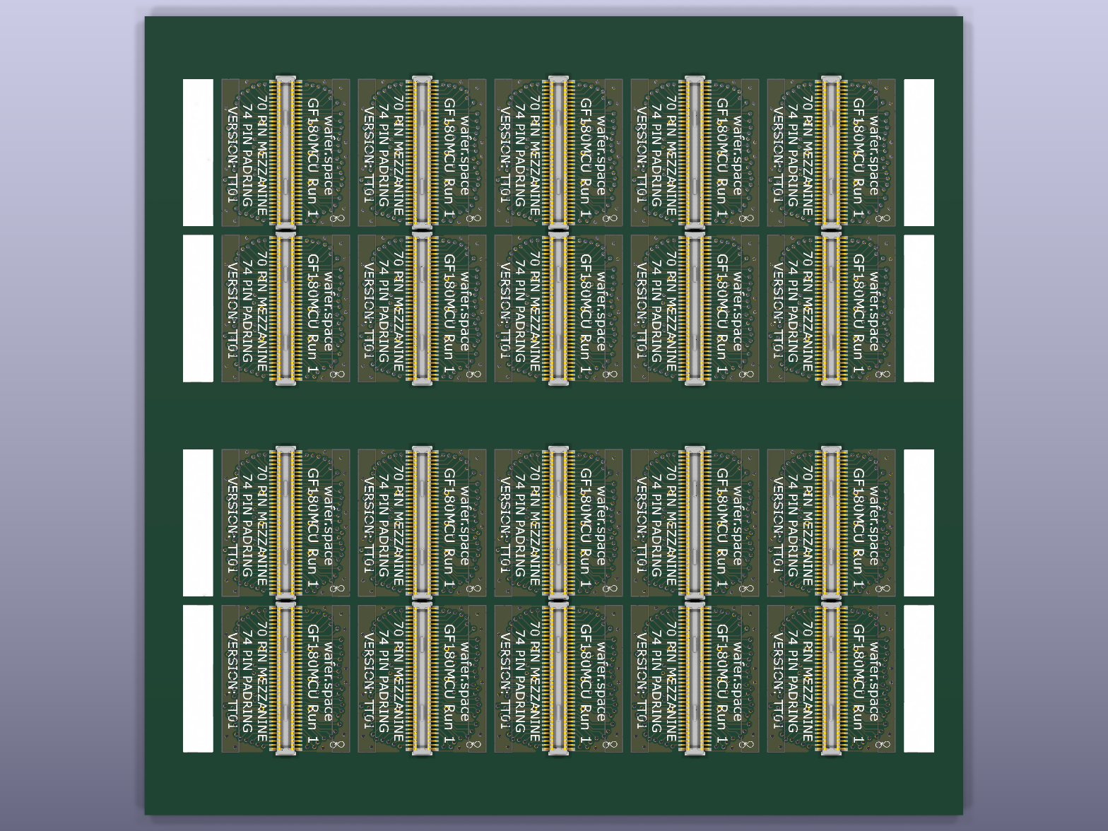
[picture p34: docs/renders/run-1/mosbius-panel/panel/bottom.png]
bottom render
| top render |  |

| Front layers | Back layers (mirrored) |
| :---: | :---: |
| front layers | back layers |

[PCB](mosbius-panel/panel.kicad_pcb)

### mosbius-panel / V3_COB_Original

| 3D top | 3D bottom |
| :---: | :---: |
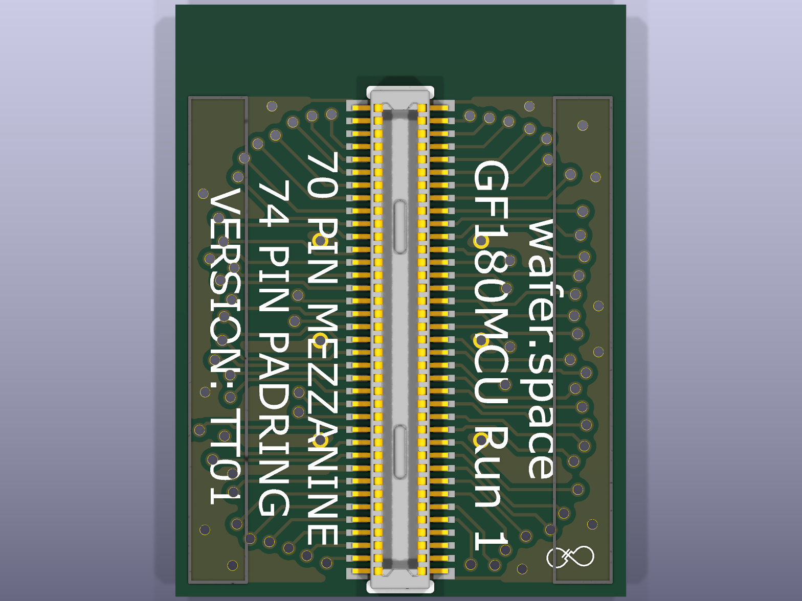
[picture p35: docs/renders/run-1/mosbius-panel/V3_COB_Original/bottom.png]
bottom render
| top render |  |

| Front layers | Back layers (mirrored) |
| :---: | :---: |
| front layers | back layers |

[PCB](mosbius-panel/V3_COB_Original.kicad_pcb)

### motherboards / motherboards

| 3D top | 3D bottom |
| :---: | :---: |
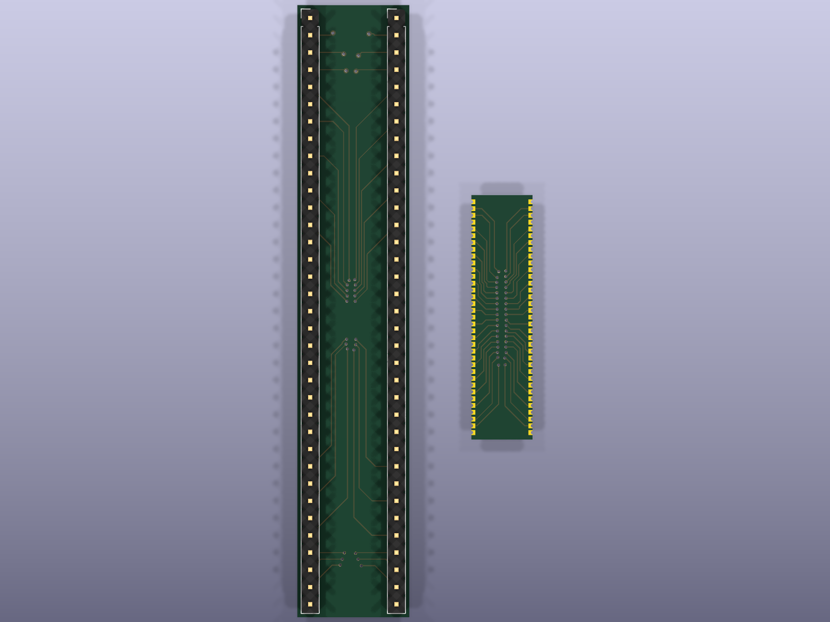
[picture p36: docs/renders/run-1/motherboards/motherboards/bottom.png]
bottom render
| top render |  |

| Front layers | Back layers (mirrored) |
| :---: | :---: |
| front layers | back layers |

[PCB](motherboards/motherboards.kicad_pcb) · [Schematic source](motherboards/motherboards.kicad_sch) · [Schematic PDF](../docs/renders/run-1/motherboards/motherboards/schematic.pdf)

### tqva-cob / panellization / panel

| 3D top | 3D bottom |
| :---: | :---: |
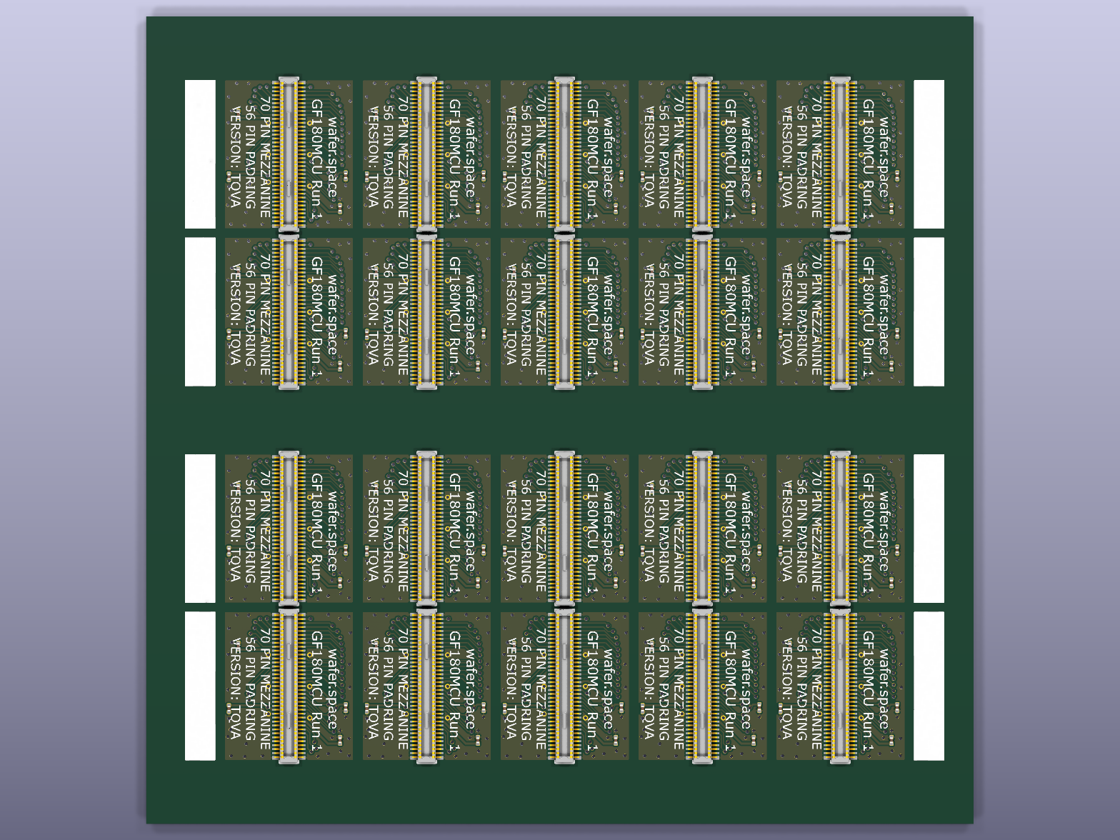
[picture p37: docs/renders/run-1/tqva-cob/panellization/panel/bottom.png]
bottom render
| top render |  |

| Front layers | Back layers (mirrored) |
| :---: | :---: |
| front layers | back layers |

[PCB](tqva-cob/panellization/panel.kicad_pcb)

### tqva-cob / tqva-cob

| 3D top | 3D bottom |
| :---: | :---: |
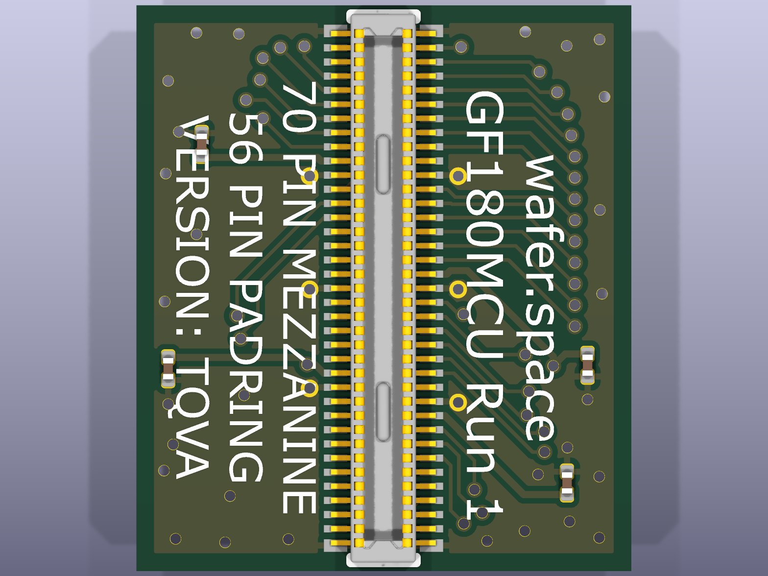
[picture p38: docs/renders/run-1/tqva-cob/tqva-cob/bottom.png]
bottom render
| top render |  |

| Front layers | Back layers (mirrored) |
| :---: | :---: |
| front layers | back layers |

[PCB](tqva-cob/tqva-cob.kicad_pcb) · [Schematic source](tqva-cob/tqva-cob.kicad_sch) · [Schematic PDF](../docs/renders/run-1/tqva-cob/tqva-cob/schematic.pdf)
<!-- AUTO-GEN:END -->

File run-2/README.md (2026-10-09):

# Run 2

This directory holds the design files for **Run 2** of the [wafer.space](https://wafer.space) chip-on-board (COB) breakouts.

---

<!-- AUTO-GEN:START -->
<!-- Generated by .github/scripts/gen_docs.py on release. Edits between the AUTO-GEN markers will be overwritten. -->

## Board Renders

*Generated for release **unreleased** on 2026-10-09.*

### 0p5x0p5-cob / 0p5x0p5-cob

| 3D top | 3D bottom |
| :---: | :---: |
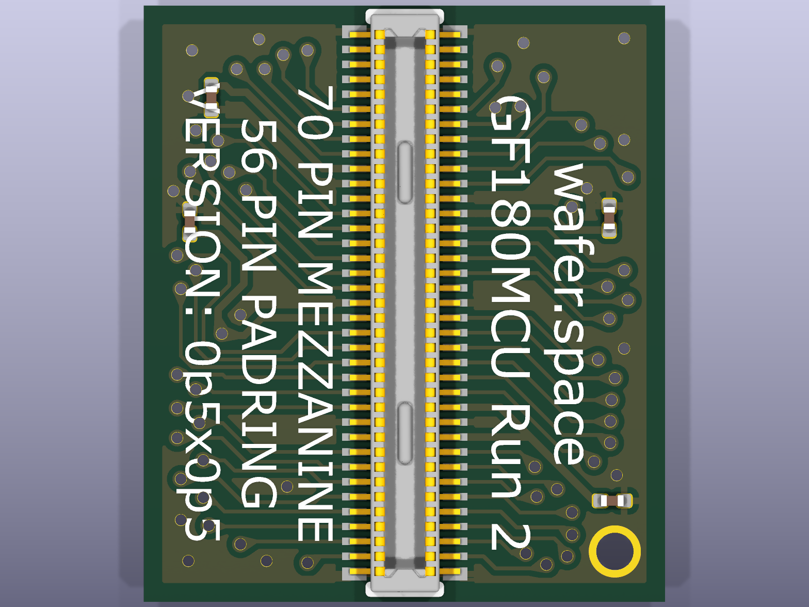
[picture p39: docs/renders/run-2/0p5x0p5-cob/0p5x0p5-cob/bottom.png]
bottom render
| top render |  |

| Front layers | Back layers (mirrored) |
| :---: | :---: |
| front layers | back layers |

[PCB](0p5x0p5-cob/0p5x0p5-cob.kicad_pcb) · [Schematic source](0p5x0p5-cob/0p5x0p5-cob.kicad_sch) · [Schematic PDF](../docs/renders/run-2/0p5x0p5-cob/0p5x0p5-cob/schematic.pdf)

### 0p5x0p5-cob / panelization / panel

| 3D top | 3D bottom |
| :---: | :---: |
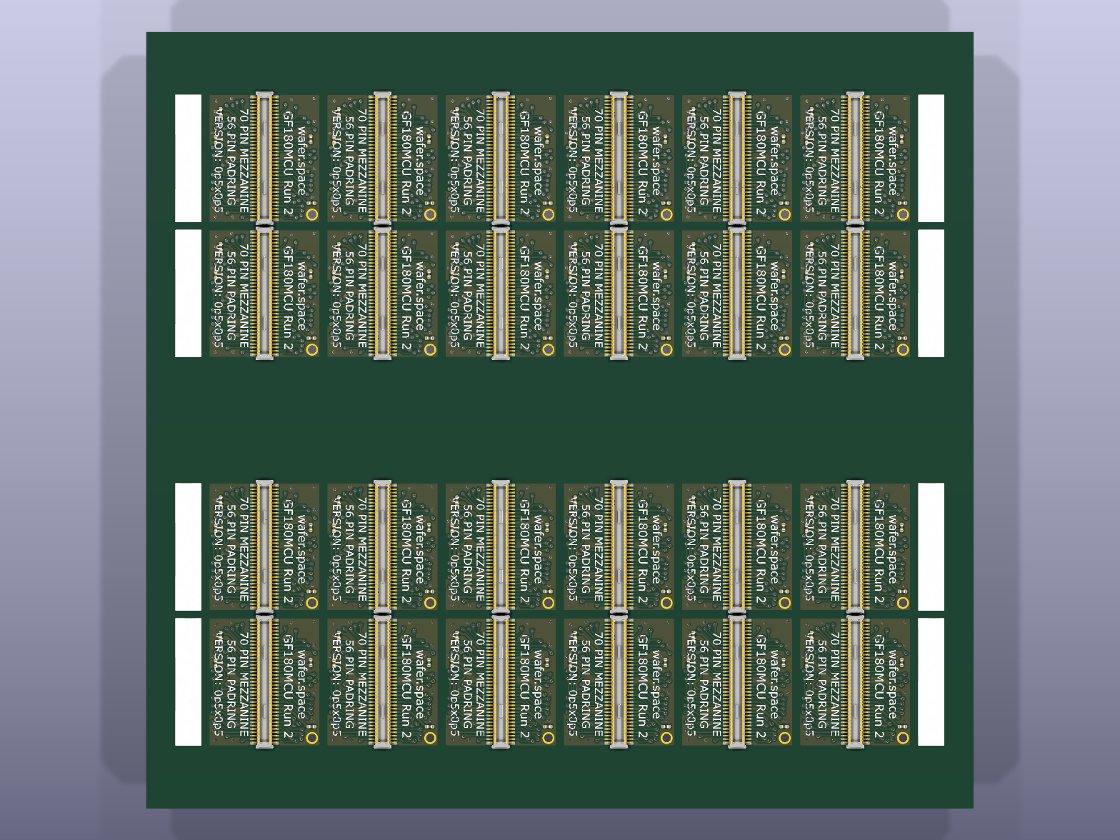
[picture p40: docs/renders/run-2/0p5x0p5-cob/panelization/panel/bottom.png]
bottom render
| top render |  |

| Front layers | Back layers (mirrored) |
| :---: | :---: |
| front layers | back layers |

[PCB](0p5x0p5-cob/panelization/panel.kicad_pcb)

### 0p5x1-cob / mezzanine-0p5x1

| 3D top | 3D bottom |
| :---: | :---: |
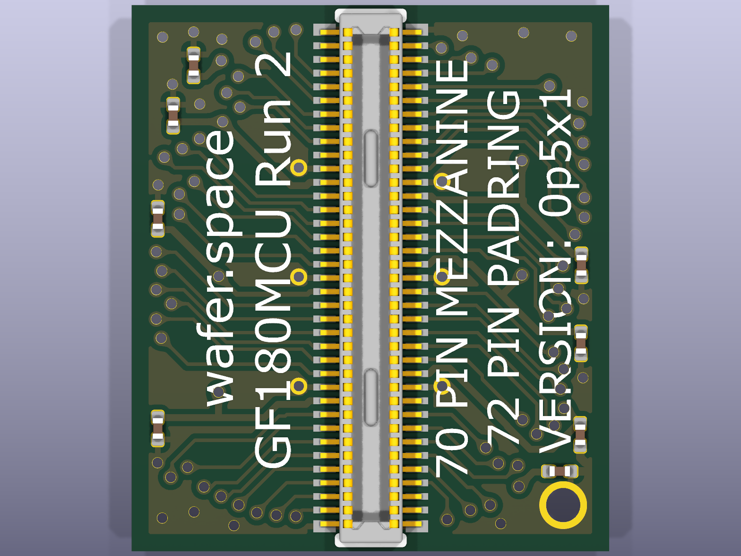
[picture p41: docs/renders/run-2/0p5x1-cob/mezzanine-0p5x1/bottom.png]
bottom render
| top render |  |

| Front layers | Back layers (mirrored) |
| :---: | :---: |
| front layers | back layers |

[PCB](0p5x1-cob/mezzanine-0p5x1.kicad_pcb) · [Schematic source](0p5x1-cob/mezzanine-0p5x1.kicad_sch) · [Schematic PDF](../docs/renders/run-2/0p5x1-cob/mezzanine-0p5x1/schematic.pdf)

### 0p5x1-cob / panelization / panel

| 3D top | 3D bottom |
| :---: | :---: |
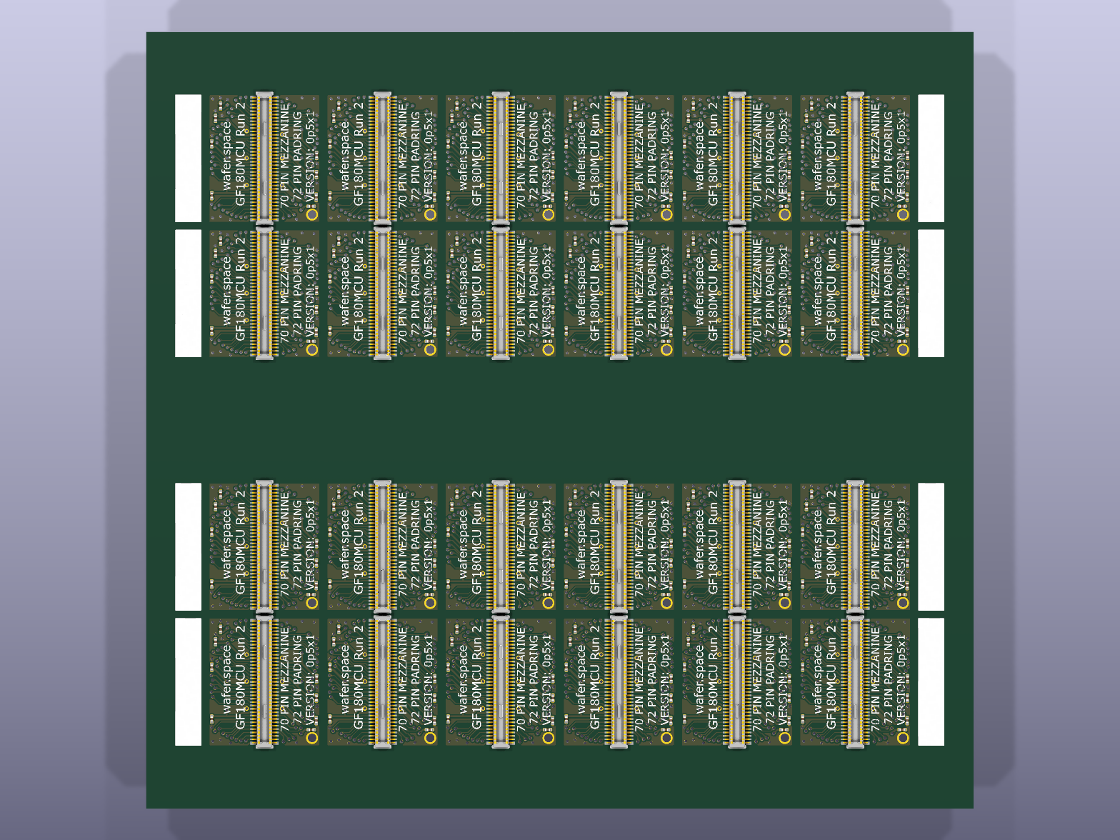
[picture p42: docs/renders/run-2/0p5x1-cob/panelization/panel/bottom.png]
bottom render
| top render |  |

| Front layers | Back layers (mirrored) |
| :---: | :---: |
| front layers | back layers |

[PCB](0p5x1-cob/panelization/panel.kicad_pcb)

### 1x0p5-cob / mezzanine-1x0p5

| 3D top | 3D bottom |
| :---: | :---: |
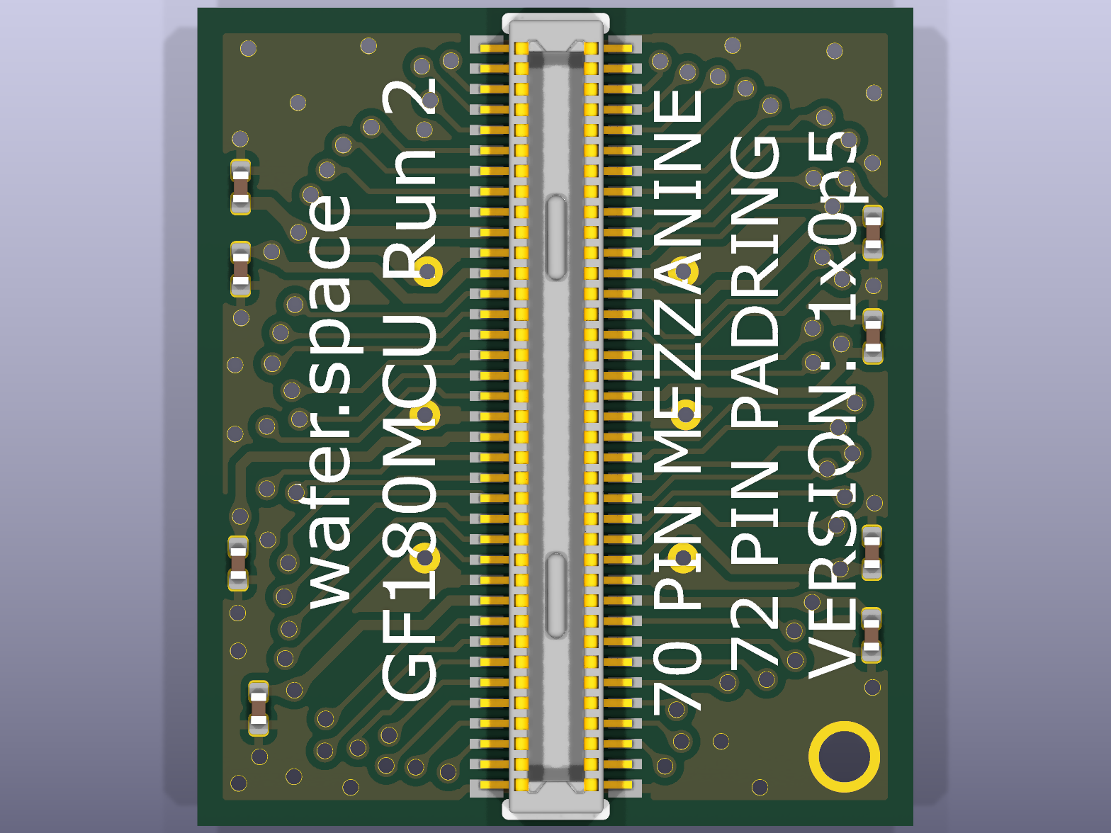
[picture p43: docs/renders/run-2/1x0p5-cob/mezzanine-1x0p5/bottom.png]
bottom render
| top render |  |

| Front layers | Back layers (mirrored) |
| :---: | :---: |
| front layers | back layers |

[PCB](1x0p5-cob/mezzanine-1x0p5.kicad_pcb) · [Schematic source](1x0p5-cob/mezzanine-1x0p5.kicad_sch) · [Schematic PDF](../docs/renders/run-2/1x0p5-cob/mezzanine-1x0p5/schematic.pdf)

### 1x0p5-cob / panelization / panel

| 3D top | 3D bottom |
| :---: | :---: |
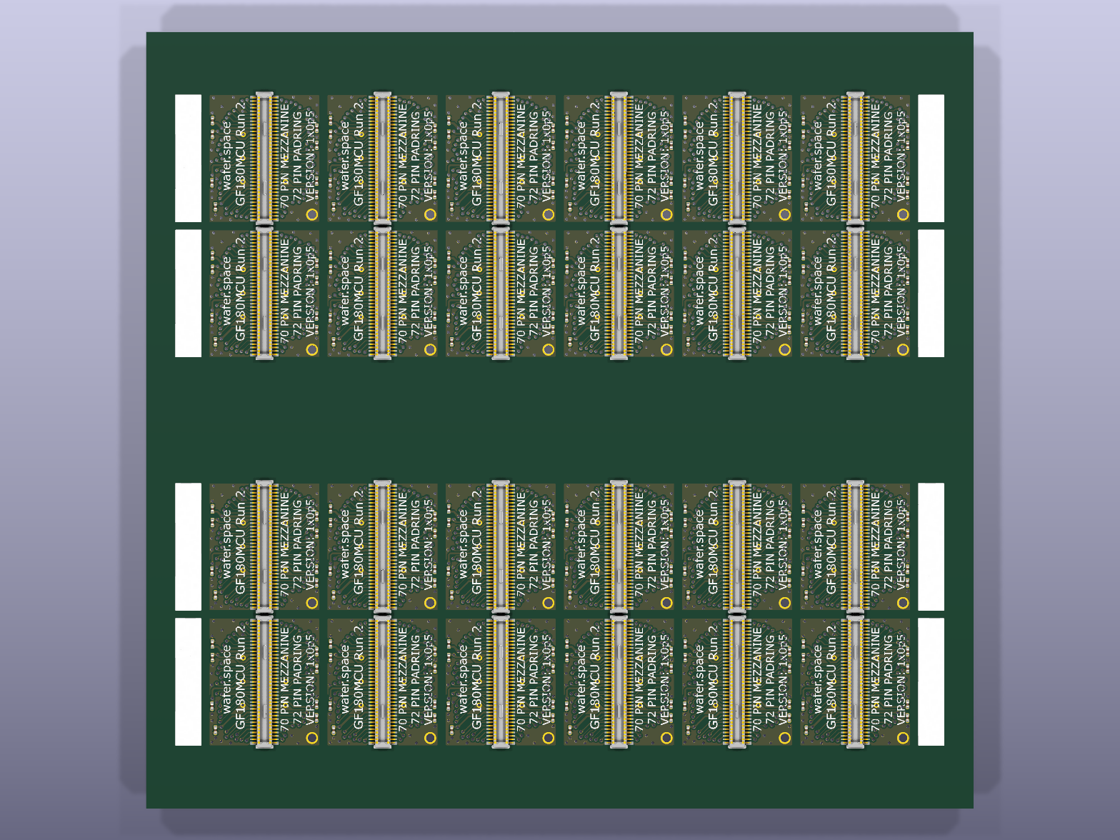
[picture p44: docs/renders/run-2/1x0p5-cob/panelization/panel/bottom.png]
bottom render
| top render |  |

| Front layers | Back layers (mirrored) |
| :---: | :---: |
| front layers | back layers |

[PCB](1x0p5-cob/panelization/panel.kicad_pcb)

### 1x1-cob / 1x1-mezzanine

| 3D top | 3D bottom |
| :---: | :---: |
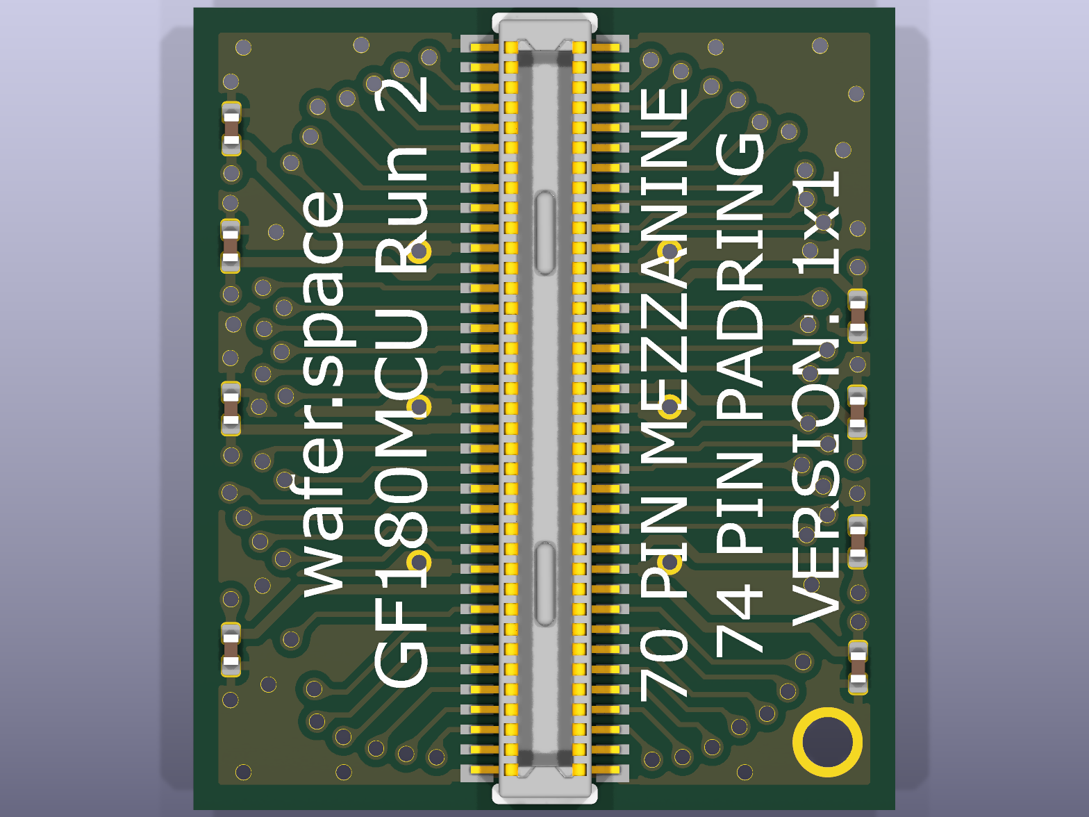
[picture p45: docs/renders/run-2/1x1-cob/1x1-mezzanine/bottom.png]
bottom render
| top render |  |

| Front layers | Back layers (mirrored) |
| :---: | :---: |
| front layers | back layers |

[PCB](1x1-cob/1x1-mezzanine.kicad_pcb) · [Schematic source](1x1-cob/1x1-mezzanine.kicad_sch) · [Schematic PDF](../docs/renders/run-2/1x1-cob/1x1-mezzanine/schematic.pdf)

### 1x1-cob / panelization / panel

| 3D top | 3D bottom |
| :---: | :---: |
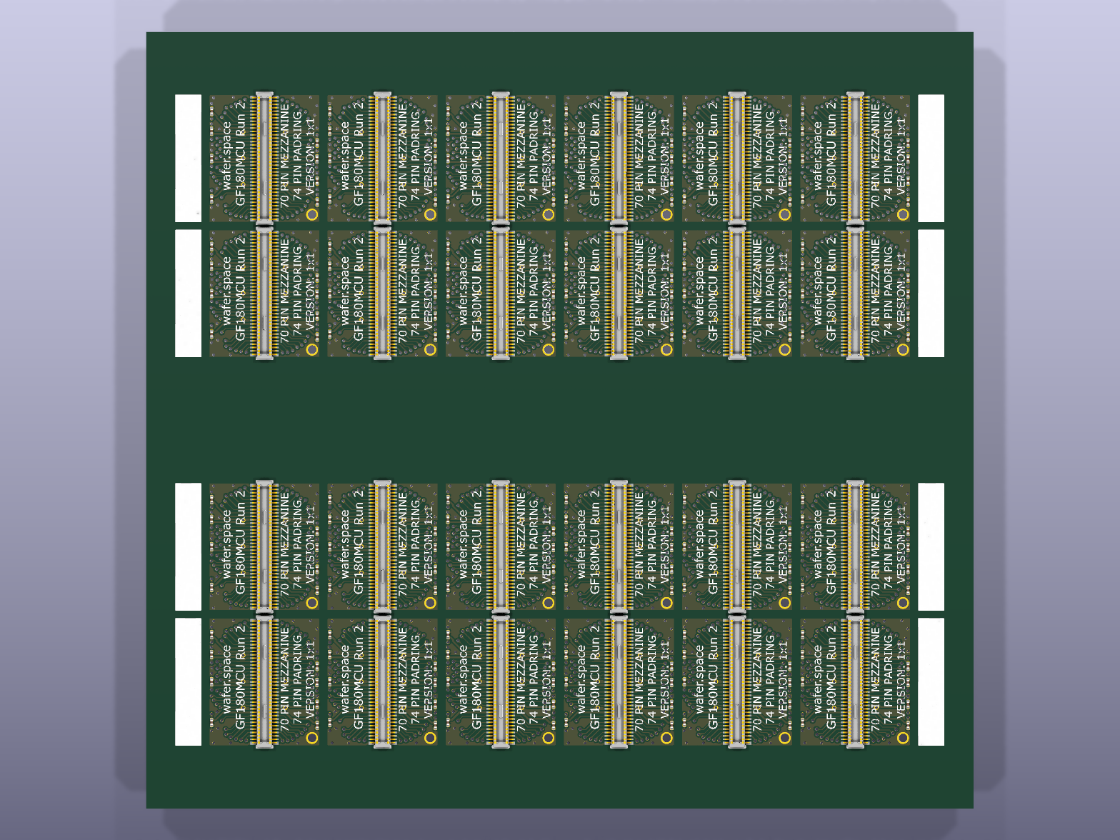
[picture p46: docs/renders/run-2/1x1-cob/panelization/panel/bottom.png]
bottom render
| top render |  |

| Front layers | Back layers (mirrored) |
| :---: | :---: |
| front layers | back layers |

[PCB](1x1-cob/panelization/panel.kicad_pcb)
<!-- AUTO-GEN:END -->

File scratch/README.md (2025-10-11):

## !!Warning: Still WIP!!

## History

Over the past few weeks we have been considering a number of different designs. 

There are some projects that require a high pin count. In an effort to keep prices down and use components that are widely available the 
current highest choice option seems to be an LGA (Land Grid Array). The current version has 100 user pins--even though the default pad frame will contain only 73 wire bonds
this will enable extra ground and power pads for analog and other signals that benefit from close proximity. 

### LGA

Current Favorite

-----

### 1.27mm headers


Was considered a pain and discarded

-----

### Castellated pins


Shares many of the drawbacks of LGA with less pins

-----

### Mezzanine Connector

Only connectors up to 50p had high availability. Some projects demand more. 

-----

### 2x Mezzanine


Worries over positional tolerances with multiple connectors

-----

### DIP



Some projects want this, but has low pin count. Some hybrid castellated versions have also been considered.

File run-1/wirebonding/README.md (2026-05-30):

# Wirebonding Detail



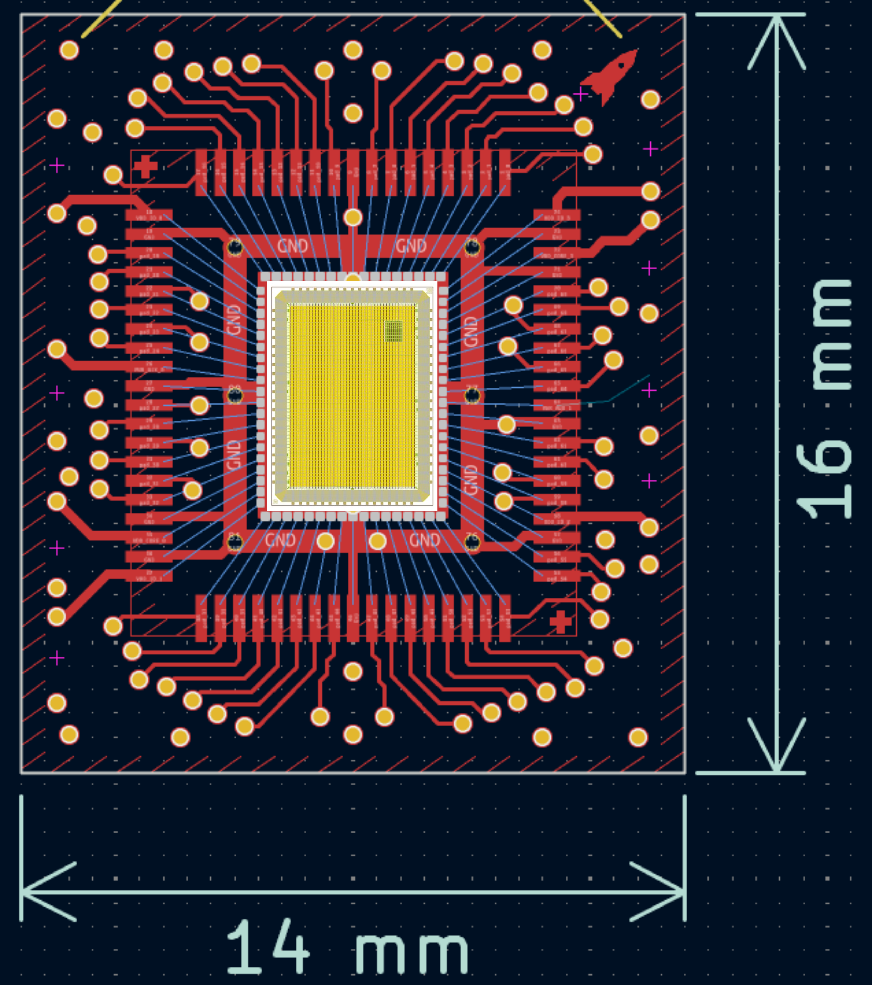
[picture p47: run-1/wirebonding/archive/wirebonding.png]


## Workflow

Wirebonding is still a very **manual process** — there are no real exchange formats yet that
tie the die layout to the breakout PCB. To bridge that gap, we have written a script that ties
together the **GDS file** (die) and the **KiCad file** (breakout) and walks pin-for-pin around
the padframe, matching each die pad to its corresponding bond pad on the PCB.

## Design Rules

The following constraints apply when laying out bond wires:

* **No wires may cross.**
* **Wire angle must be not greater than 45°.**
* **Maximum wire length must be less than 3 mm** — though a wire that long would already add a
  significant amount of inductance, so keep them as short as practical.
* **Minimum wire length is 1 mm from the die, or 2× the die thickness** (whichever is greater).
* **No solder mask** is allowed in the area to be bonded.

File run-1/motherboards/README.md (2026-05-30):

# Example Motherboards

We've designed several example breakout and motherboard PCBs to simplify development and
integration with your custom chips.



We have also developed a set of **KiCad symbols** to support design and integration with our COB layouts. These symbols are included in the [Motherboards examples](./README.md) and can be used as a reference for your own designs.


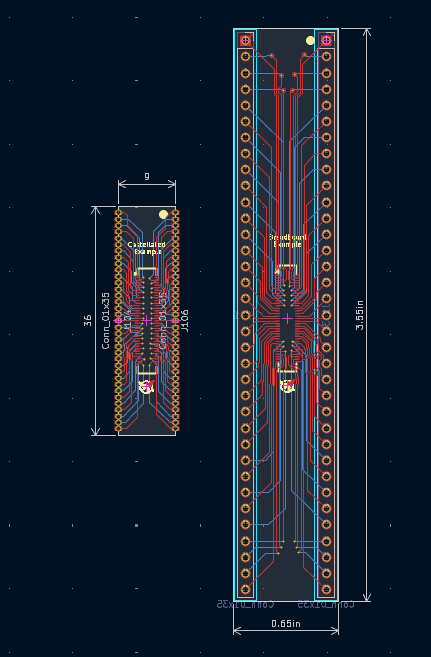
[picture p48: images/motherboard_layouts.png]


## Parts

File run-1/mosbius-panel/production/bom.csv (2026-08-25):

Designator | Footprint | Quantity | Value | LCSC Part #
J101_2, J101, J102_2, J102, J103_2, J103, J104_2, J104, J105_2, J105, J106_2, J106, J107_2, J107, J108_2, J108, J109_2, J109, J110_2, J110 | CONN-SMD_70P-P0.40_HCTL_HC-PBB40C-70DP-0.4V-02 | 20 | Conn_02x35_Counter_Clockwise_MountingPin
U102_2, U102, U103_2, U103, U104_2, U104, U105_2, U105, U106_2, U106, U107_2, U107, U108_2, U108, U109_2, U109, U110_2, U110, U111_2, U111 | waferspace_default_padring_v0.2 | 20 | ~

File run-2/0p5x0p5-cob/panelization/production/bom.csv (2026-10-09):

Designator | Footprint | Quantity | Value | LCSC Part #
C101_2, C101, C102_2, C102, C103_2, C103, C104_2, C104, C105_2, C105, C106_2, C106, C107_2, C107, C108_2, C108, C109_2, C109, C110_2, C110, C111_2, C111, C112_2, C112, C113_2, C113, C114_2, C114, C115_2, C115, C116_2, C116, C117_2, C117, C118_2, C118, C119_2, C119, C120_2, C120, C121_2, C121, C122_2, C122, C123_2, C123, C124_2, C124, C125_2, C125, C126_2, C126, C127_2, C127, C128_2, C128, C129_2, C129, C130_2, C130, C131_2, C131, C132_2, C132, C133_2, C133, C134_2, C134, C135_2, C135, C136_2, C136, C137_2, C137, C138_2, C138, C139_2, C139, C140_2, C140, C141_2, C141, C142_2, C142, C143_2, C143, C144_2, C144, C145_2, C145, C146_2, C146, C147_2, C147, C148_2, C148 | 0201 | 96 | C_Small
J1_2, J1, J10_2, J10, J11_2, J11, J12_2, J12, J2_2, J2, J3_2, J3, J4_2, J4, J5_2, J5, J6_2, J6, J7_2, J7, J8_2, J8, J9_2, J9 | pin1_fiducial | 24 | Conn_01x01
U101_2, U101, U103_2, U103, U105_2, U105, U107_2, U107, U109_2, U109, U111_2, U111, U113_2, U113, U115_2, U115, U117_2, U117, U119_2, U119, U121_2, U121, U123_2, U123 | CONN-SMD_70P-P0.40_HCTL_HC-PBB40C-70DP-0.4V-02 | 24 | ~
U102_2, U102, U104_2, U104, U106_2, U106, U108_2, U108, U110_2, U110, U112_2, U112, U114_2, U114, U116_2, U116, U118_2, U118, U120_2, U120, U122_2, U122, U124_2, U124 | waferspace_p5xp5_padring | 24 | ~

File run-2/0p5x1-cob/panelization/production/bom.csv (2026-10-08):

Designator | Footprint | Quantity | Value | LCSC Part #
C101_2, C101, C102_2, C102, C103_2, C103, C104_2, C104, C105_2, C105, C106_2, C106, C107_2, C107, C108_2, C108, C109_2, C109, C110_2, C110, C111_2, C111, C112_2, C112, C113_2, C113, C114_2, C114, C115_2, C115, C116_2, C116, C117_2, C117, C118_2, C118, C119_2, C119, C120_2, C120, C121_2, C121, C122_2, C122, C123_2, C123, C124_2, C124, C125_2, C125, C126_2, C126, C127_2, C127, C128_2, C128, C129_2, C129, C130_2, C130, C131_2, C131, C132_2, C132, C133_2, C133, C134_2, C134, C135_2, C135, C136_2, C136, C137_2, C137, C138_2, C138, C139_2, C139, C140_2, C140, C141_2, C141, C142_2, C142, C143_2, C143, C144_2, C144, C145_2, C145, C146_2, C146, C147_2, C147, C148_2, C148, C149_2, C149, C150_2, C150, C151_2, C151, C152_2, C152, C153_2, C153, C154_2, C154, C155_2, C155, C156_2, C156, C157_2, C157, C158_2, C158, C159_2, C159, C160_2, C160, C161_2, C161, C162_2, C162, C163_2, C163, C164_2, C164, C165_2, C165, C166_2, C166, C167_2, C167, C168_2, C168, C169_2, C169, C170_2, C170, C171_2, C171, C172_2, C172, C173_2, C173, C174_2, C174, C175_2, C175, C176_2, C176, C177_2, C177, C178_2, C178, C179_2, C179, C180_2, C180, C181_2, C181, C182_2, C182, C183_2, C183, C184_2, C184, C185_2, C185, C186_2, C186, C187_2, C187, C188_2, C188, C189_2, C189, C190_2, C190, C191_2, C191, C192_2, C192, C193_2, C193, C194_2, C194, C195_2, C195, C196_2, C196 | 0201 | 192 | C_Small
J1_2, J1, J10_2, J10, J11_2, J11, J12_2, J12, J2_2, J2, J3_2, J3, J4_2, J4, J5_2, J5, J6_2, J6, J7_2, J7, J8_2, J8, J9_2, J9 | pin1_fiducial | 24 | Conn_01x01
U101_2, U101, U103_2, U103, U105_2, U105, U107_2, U107, U109_2, U109, U111_2, U111, U113_2, U113, U115_2, U115, U117_2, U117, U119_2, U119, U121_2, U121, U123_2, U123 | CONN-SMD_70P-P0.40_HCTL_HC-PBB40C-70DP-0.4V-02 | 24 | ~
U102_2, U102, U104_2, U104, U106_2, U106, U108_2, U108, U110_2, U110, U112_2, U112, U114_2, U114, U116_2, U116, U118_2, U118, U120_2, U120, U122_2, U122, U124_2, U124 | waferspace_p5x1_padring_v0.2 | 24 | ~

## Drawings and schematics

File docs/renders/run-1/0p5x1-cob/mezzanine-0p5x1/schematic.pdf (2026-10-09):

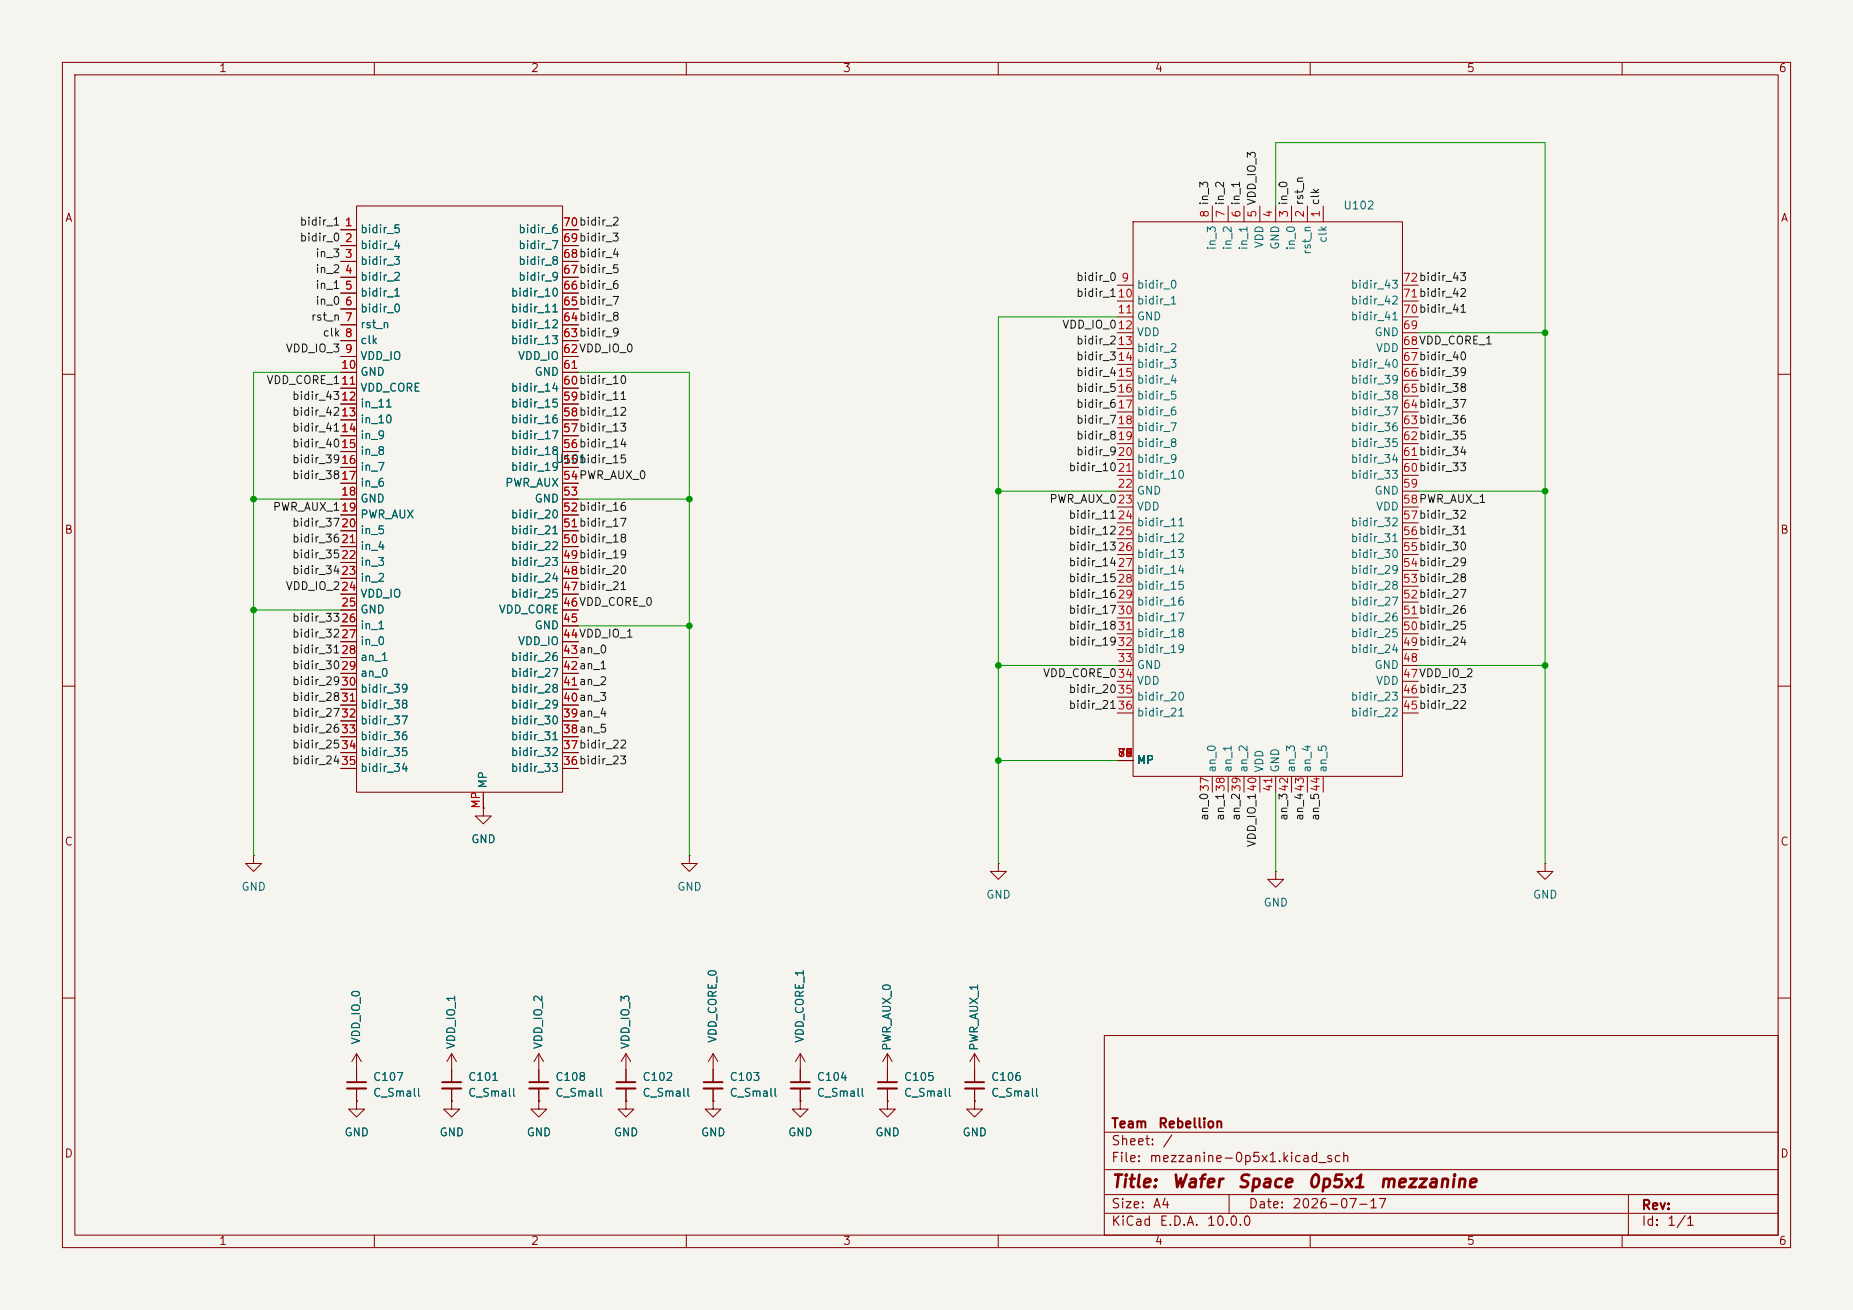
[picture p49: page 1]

Sheet: /
File: mezzanine-0p5x1.kicad_sch
Title: Wafer Space 0p5x1 mezzanine

Size: A4 | Rev:

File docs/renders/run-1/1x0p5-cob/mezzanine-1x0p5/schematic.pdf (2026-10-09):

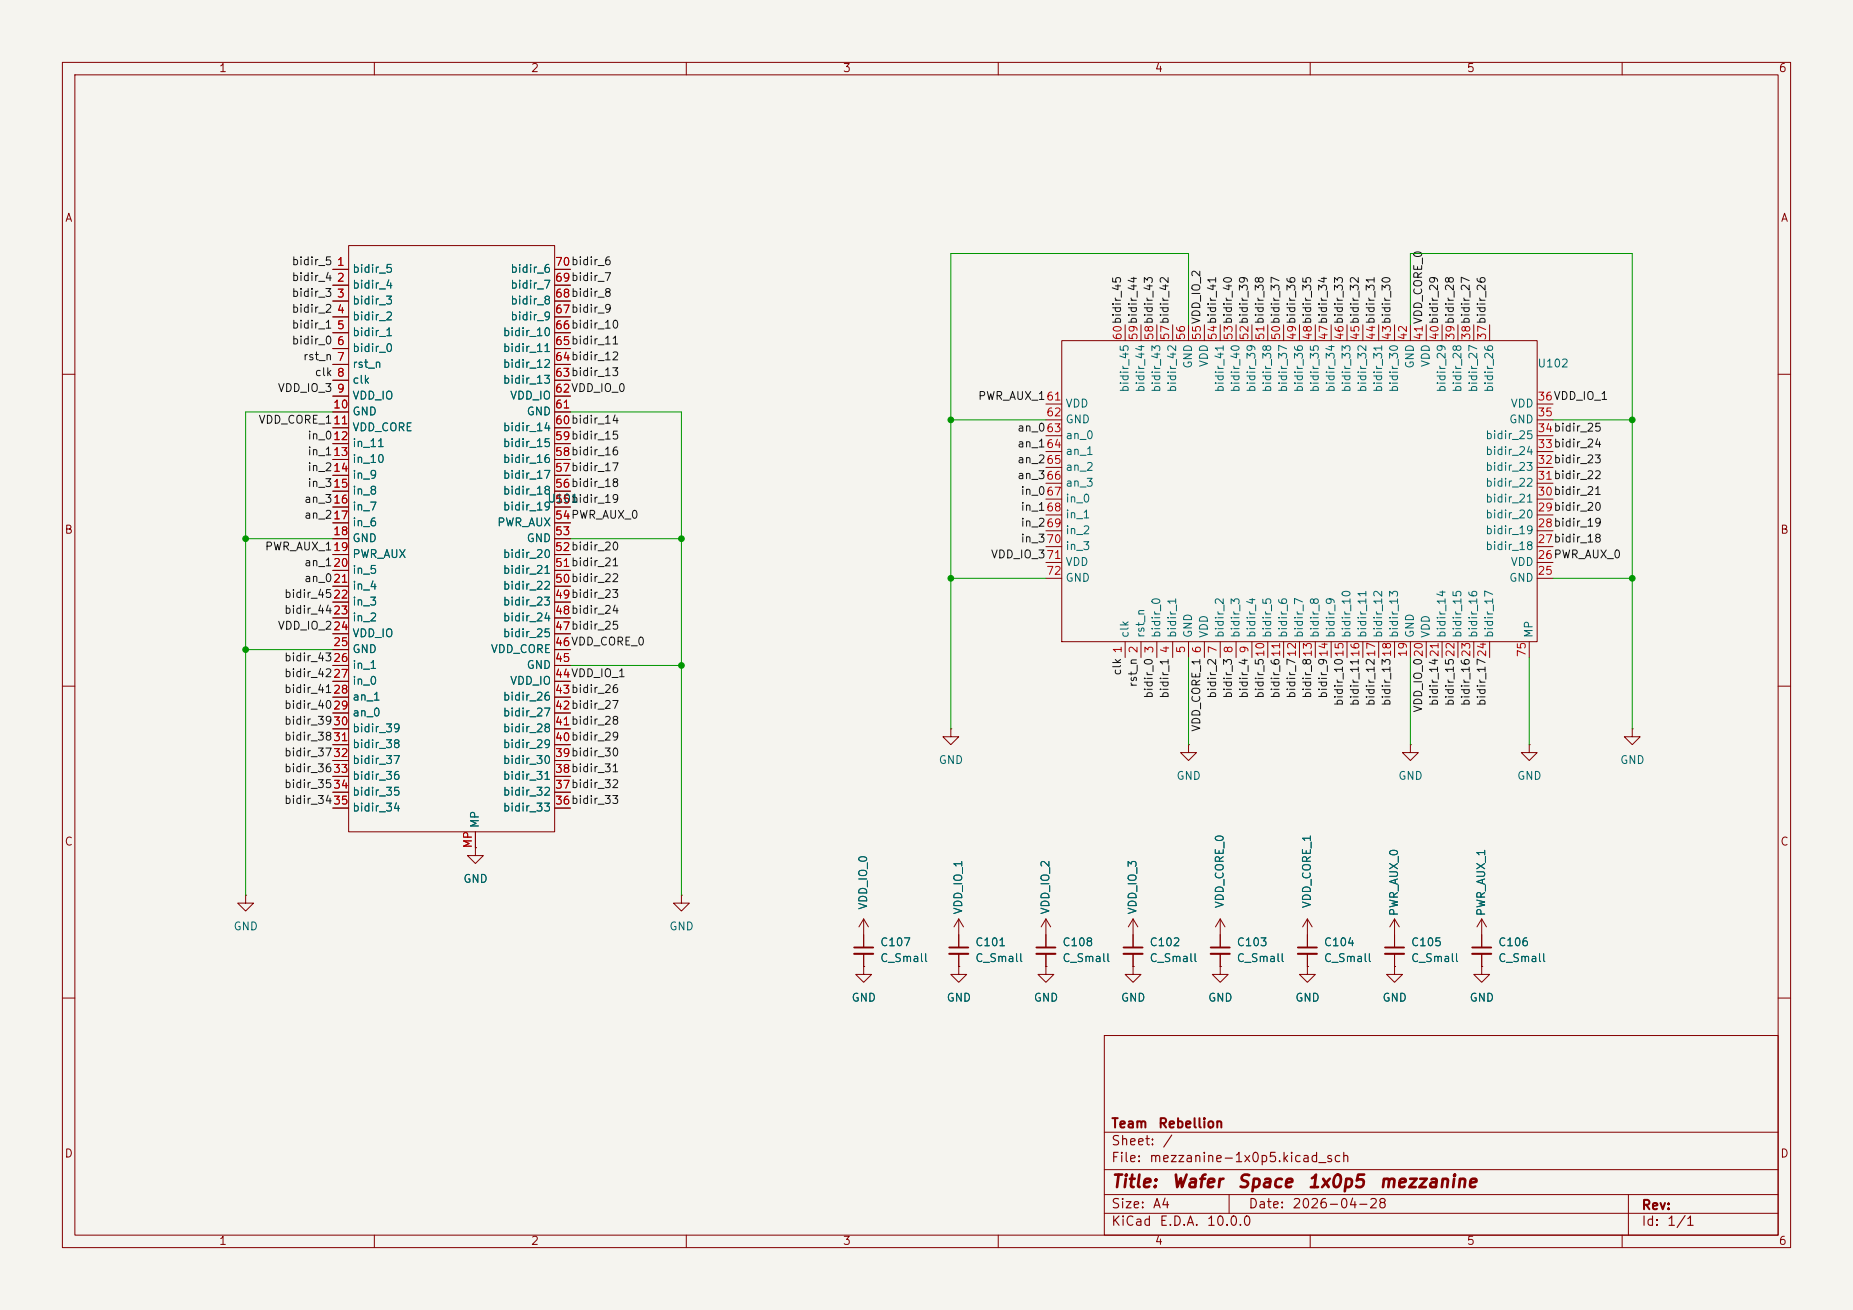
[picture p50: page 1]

9 bidir_5 10 bidir_6 11 bidir_7 12 bidir_8 13 bidir_9 14 bidir_10 15 bidir_11 16 bidir_12 17 bidir_13 18 GND 19 VDD 20 bidir_14 21 bidir_15 22 bidir_16 23 bidir_17 24 GND 25 VDD 26 bidir_18 27 bidir_19 28 bidir_20 29 bidir_21 30 bidir_22 31 bidir_23 32 bidir_24 33 bidir_25 34 GND 35 VDD 36 bidir_26 37 bidir_27 38 bidir_28 39 bidir_29 40 VDD 41 GND 42 bidir_30 43 bidir_31 44 bidir_32 45 bidir_33 46 bidir_34 47 bidir_35 48 bidir_36 49 bidir_37 50 bidir_38 51 bidir_39 52 bidir_40 53 bidir_41 54 VDD 55 GND 56 bidir_42 57 bidir_43 58 bidir_44 59 bidir_45 60

Team Rebellion
Sheet: /
D Date: 2026-04-28 KiCad E.D.A. 10.0.0
File: mezzanine-1x0p5.kicad_sch
Title: Wafer Space 1x0p5 mezzanine

Size: A4 | Rev:

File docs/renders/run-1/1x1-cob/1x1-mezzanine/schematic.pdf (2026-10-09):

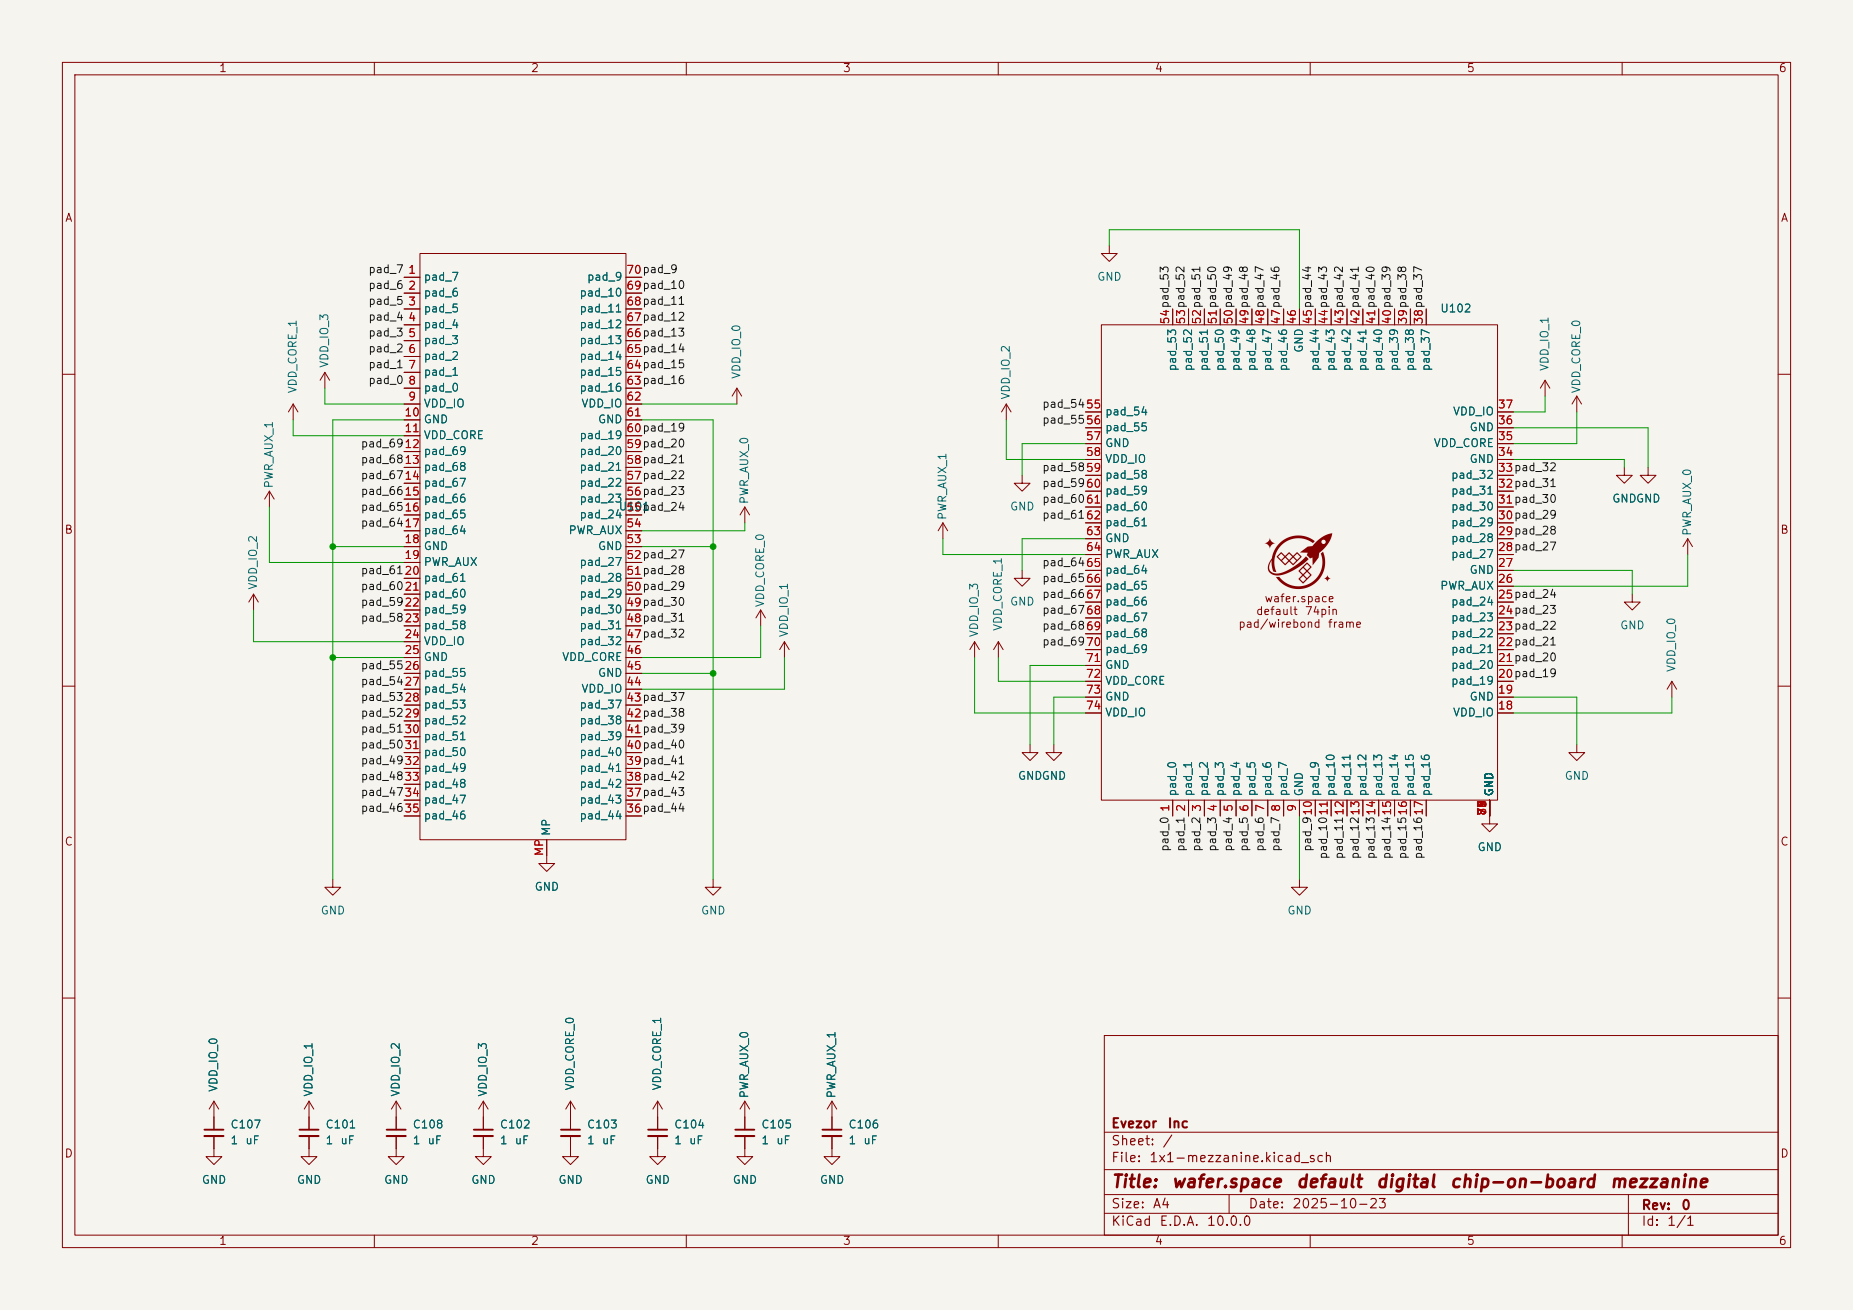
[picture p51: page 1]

Sheet: /
D Date: 2025-10-23 KiCad E.D.A. 10.0.0
File: 1x1-mezzanine.kicad_sch
Title: wafer.space default digital chip-on-board mezzanine

Size: A4 | Rev: 0

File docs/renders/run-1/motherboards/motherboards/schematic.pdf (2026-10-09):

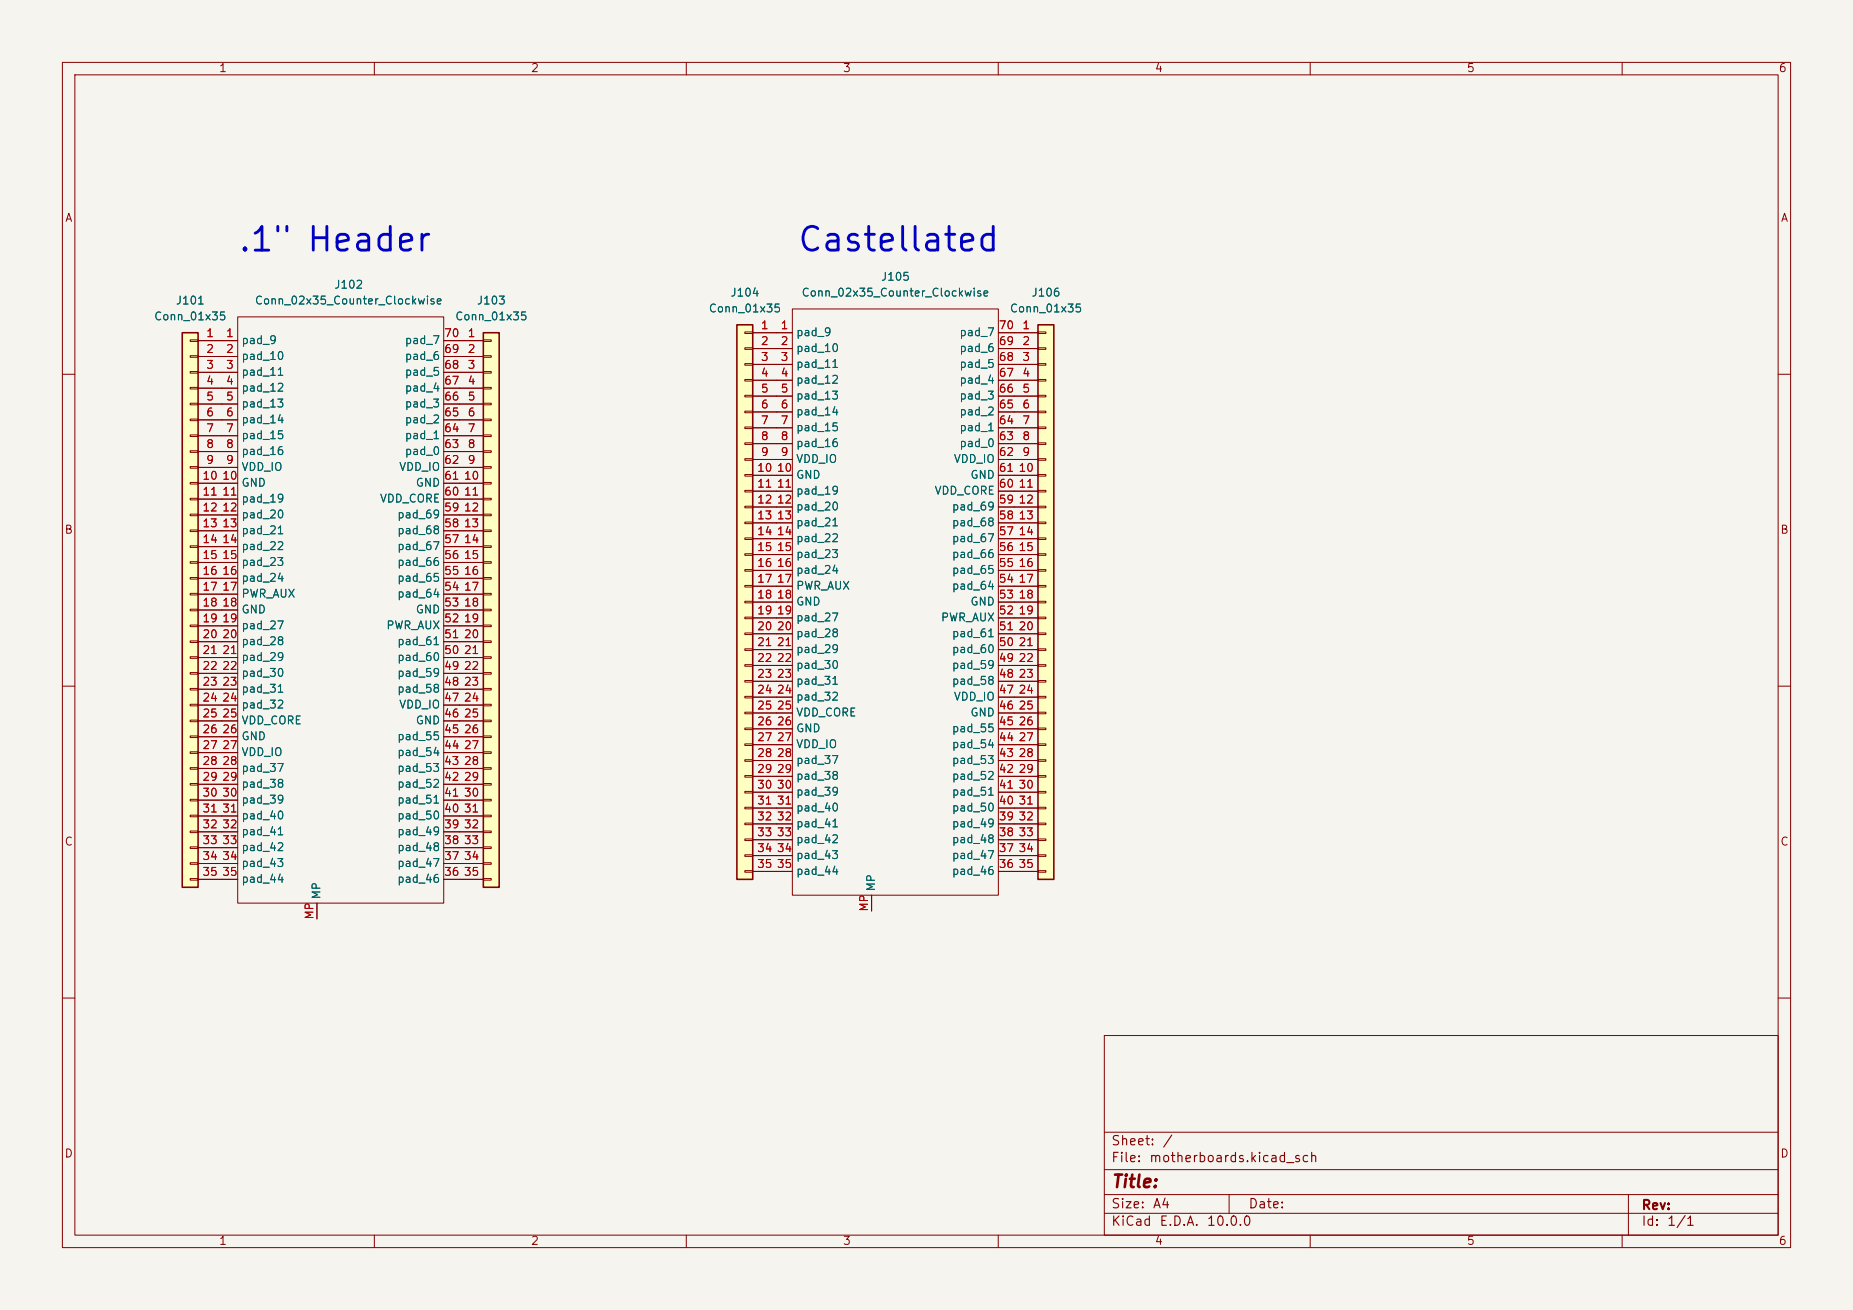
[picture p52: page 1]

10 10 | | 10 10
11 11 | pad_19 11 | 11 11
12 12 | pad_20 12 | 12 12
13 13 | pad_21 13 | 13 13
14 14 | pad_22 14 | 14 14
15 15 | pad_23 15 | 15 15
16 16 | | 16 16

17 17 | pad_24 16 PWR_AUX 17 GND 18 | 17 17

18 18 | | 18 18
19 19 | pad_27 19 | 19 19
20 20 | pad_28 20 | 20 20
21 21 | pad_29 21 | 21 21
22 22 | pad_30 22 | 22 22
23 23 | pad_31 23 | 23 23
24 24 | pad_32 24 | 24 24
25 25 | VDD_CORE 25 GND 26 | 25 25
26 26 | | 26 26
27 27 | VDD_IO 27 | 27 27
28 28 | pad_37 28 | 28 28
29 29 | pad_38 29 | 29 29
30 30 | pad_39 30 | 30 30
31 31 | pad_40 31 | 31 31
32 32 | pad_41 32 | 32 32
33 33 | pad_42 33 | 33 33
34 34 | pad_43 34 | 34 34
35 35 | | 35 35

Size: A4 | Rev:
KiCad E.D.A. 10.0.0 | Id: 1/1

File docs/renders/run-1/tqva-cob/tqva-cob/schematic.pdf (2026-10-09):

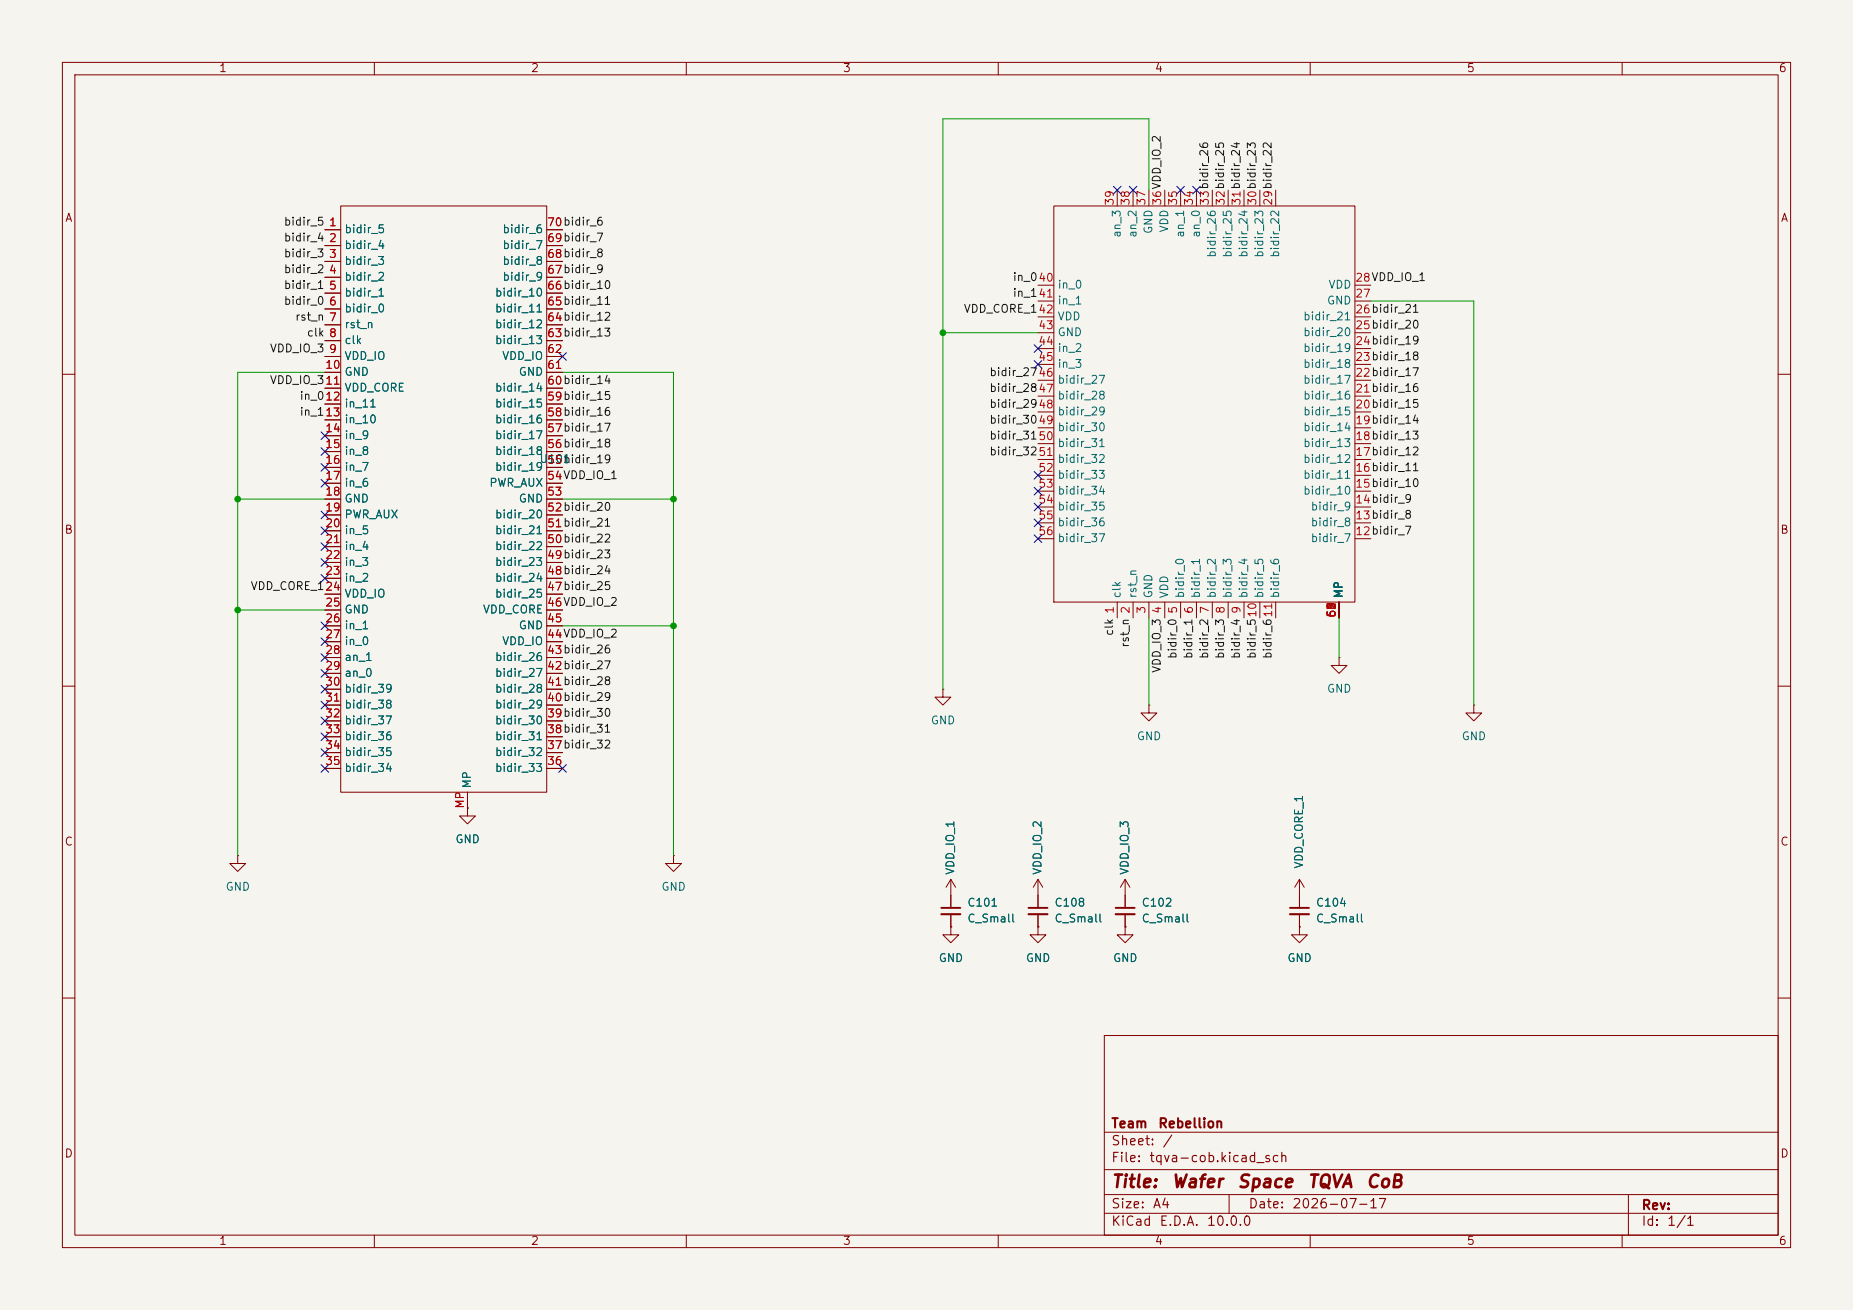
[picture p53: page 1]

in_0 in_1 | VDD_CORE 11 VDD_CORE 11 in_11 12 in_11 12 in_10 13 in_10 13 in_9 14 in_9 14 in_8 15 in_8 15 in_7 16 in_7 16 U101 in_6 17 GND 18 PWR_AUX 19 in_6 17 GND 18 PWR_AUX 19 | bidir_14 bidir_15 bidir_16 bidir_18 bidir_19 VDD_IO_1

VDD_CORE_1 | in_5 20 in_5 20 in_4 21 in_4 21 in_3 22 in_3 22 in_2 23 in_2 23 VDD_IO 24 GND 25 VDD_IO 24 GND 25 | bidir_20 bidir_21 bidir_22 bidir_23 bidir_24 bidir_25 VDD_IO_2

Team Rebellion
Sheet: /
File: tqva-cob.kicad_sch
Title: Wafer Space TQVA CoB

Size: A4 | Rev:

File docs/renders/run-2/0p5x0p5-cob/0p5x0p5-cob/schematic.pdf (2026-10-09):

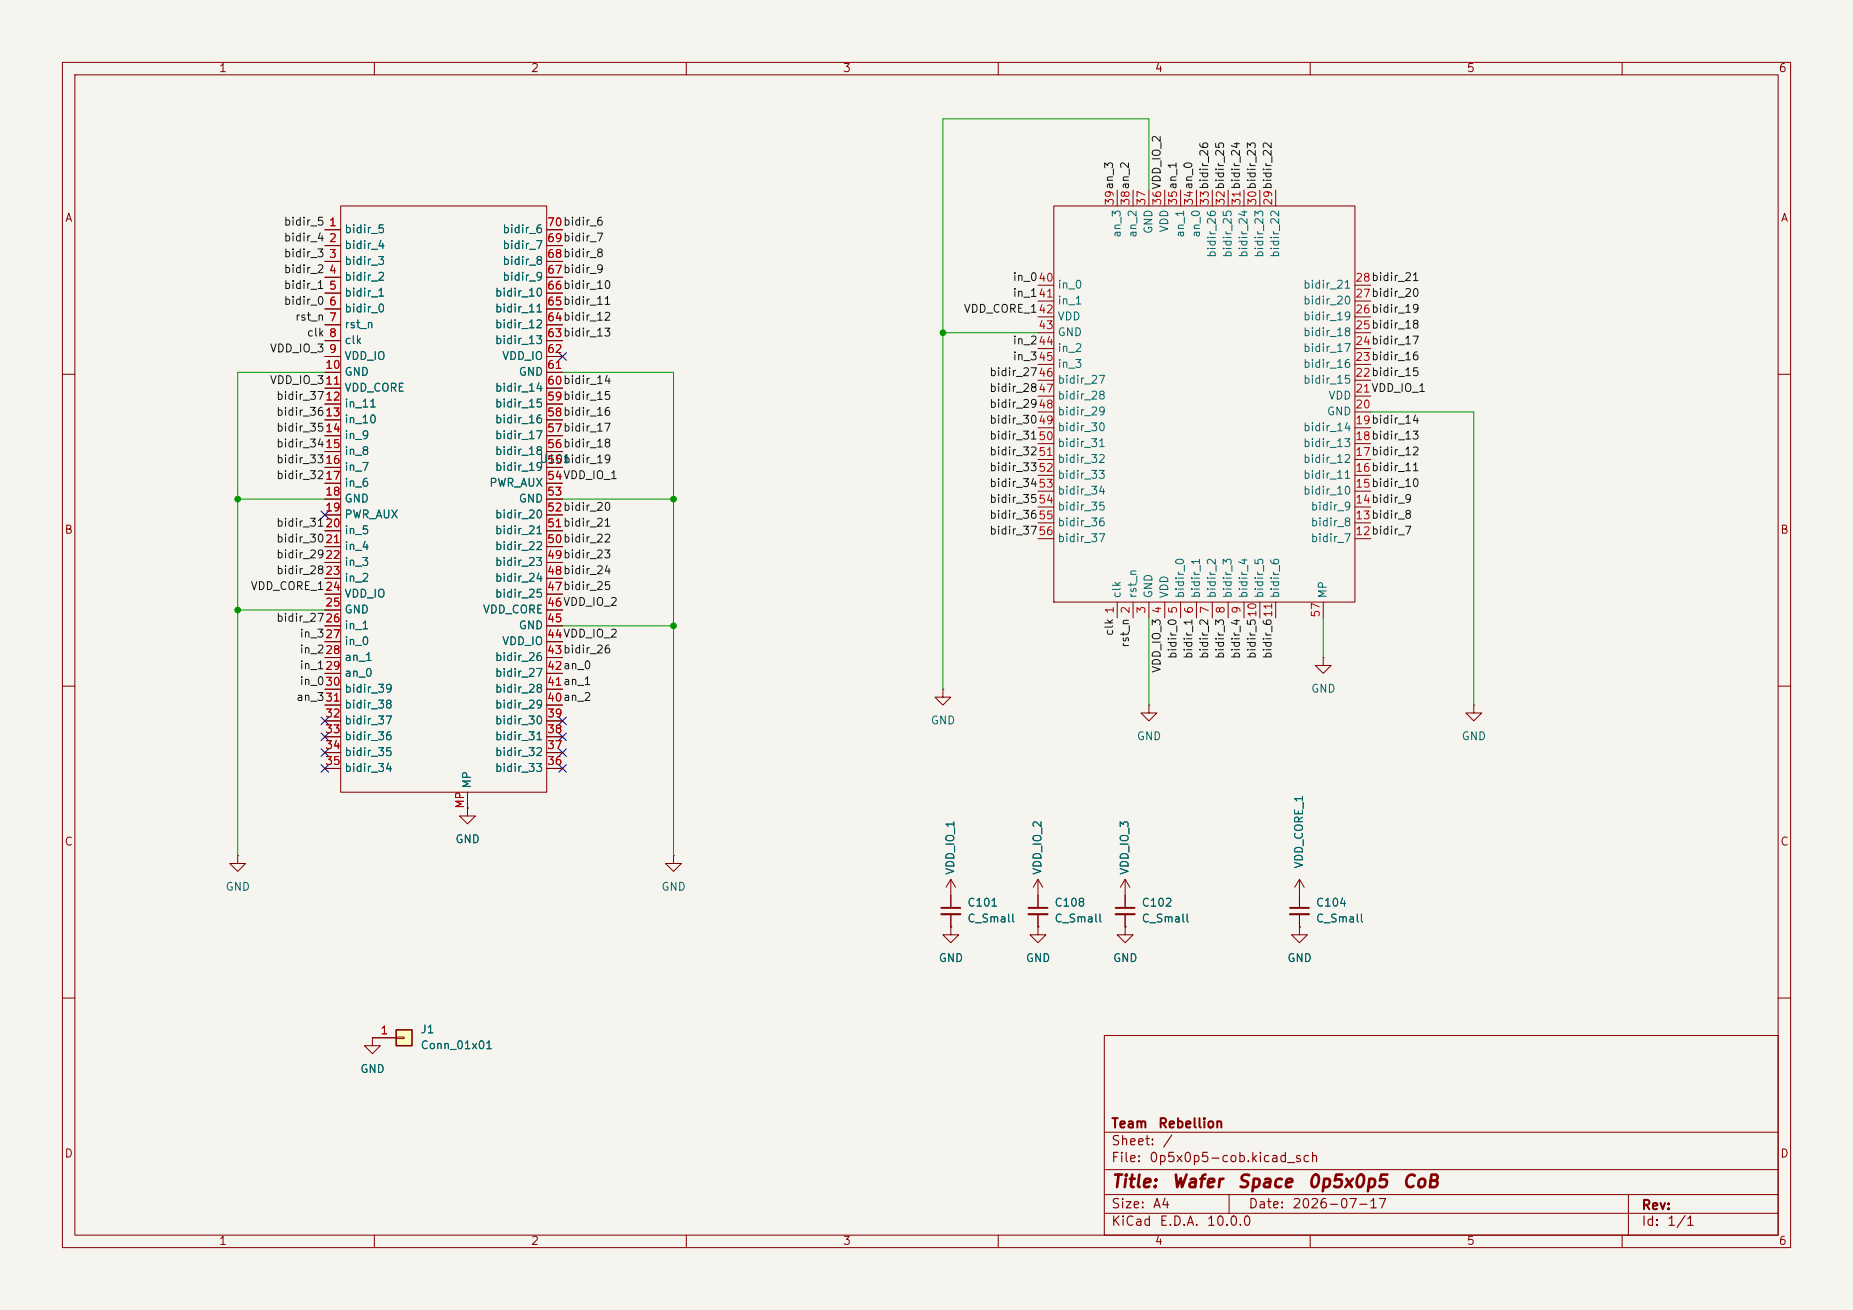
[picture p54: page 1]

VDD_IO_3 bidir_37 bidir_36 bidir_35 bidir_34 bidir_33 bidir_32 | VDD_CORE 11 VDD_CORE 11 in_11 12 in_11 12 in_10 13 in_10 13 in_9 14 in_9 14 U101 in_8 15 in_8 15 in_7 16 in_7 16 in_6 17 GND 18 PWR_AUX 19 in_6 17 GND 18 PWR_AUX 19 | bidir_14 bidir_15 bidir_16 bidir_17 bidir_18 bidir_19 VDD_IO_1

bidir_31 bidir_30 bidir_29 bidir_28 VDD_CORE_1 | in_5 20 in_5 20 in_4 21 in_4 21 in_3 22 in_3 22 in_2 23 in_2 23 VDD_IO 24 GND 25 VDD_IO 24 GND 25 | bidir_20 bidir_22 bidir_23 bidir_24 bidir_25 VDD_IO_2

Team Rebellion
Sheet: /
File: 0p5x0p5-cob.kicad_sch
Title: Wafer Space 0p5x0p5 CoB

Size: A4 | Rev:

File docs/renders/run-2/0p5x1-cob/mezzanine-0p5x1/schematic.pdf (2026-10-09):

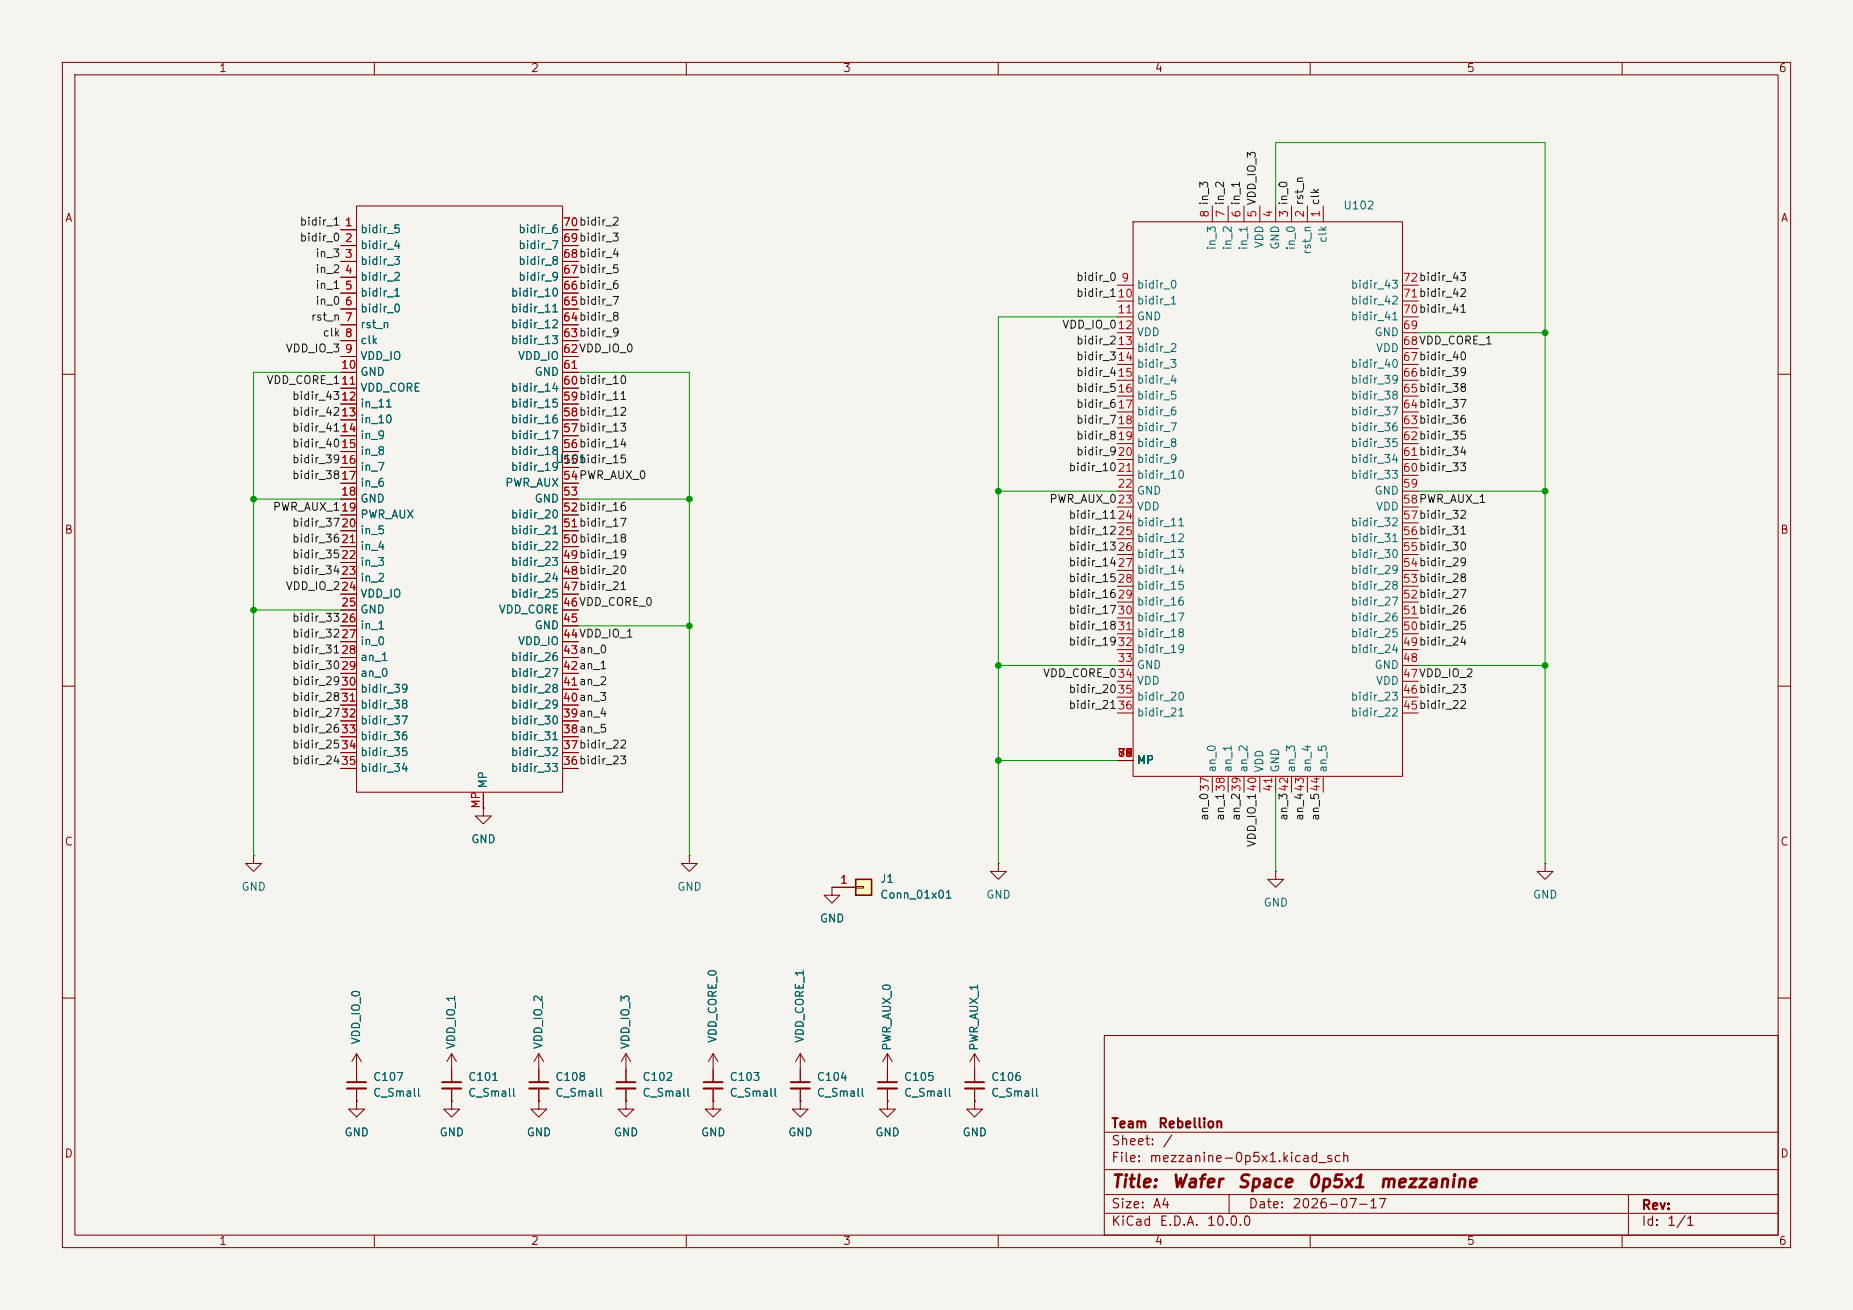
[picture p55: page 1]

VDD_CORE_1 bidir_43 bidir_42 bidir_41 bidir_40 bidir_39 bidir_38 | VDD_CORE 11 VDD_CORE 11 in_11 12 in_11 12 in_10 13 in_10 13 in_9 14 in_9 14 in_8 15 in_8 15 in_7 16 in_7 16 in_6 17 GND 18 PWR_AUX 19 in_6 17 GND 18 PWR_AUX 19 | bidir_10 bidir_11 bidir_12 bidir_13 bidir_14 bidir_15 PWR_AUX_0

bidir_35 PWR_AUX_1 bidir_37 bidir_36 bidir_34 VDD_IO_2 | in_5 20 in_5 20 in_4 21 in_4 21 in_3 22 in_3 22 in_2 23 in_2 23 VDD_IO 24 GND 25 VDD_IO 24 GND 25 | bidir_16 bidir_17 bidir_18 bidir_20 bidir_21 VDD_CORE_0

Sheet: /
File: mezzanine-0p5x1.kicad_sch
Title: Wafer Space 0p5x1 mezzanine

Size: A4 | Rev:

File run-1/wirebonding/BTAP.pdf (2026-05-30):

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

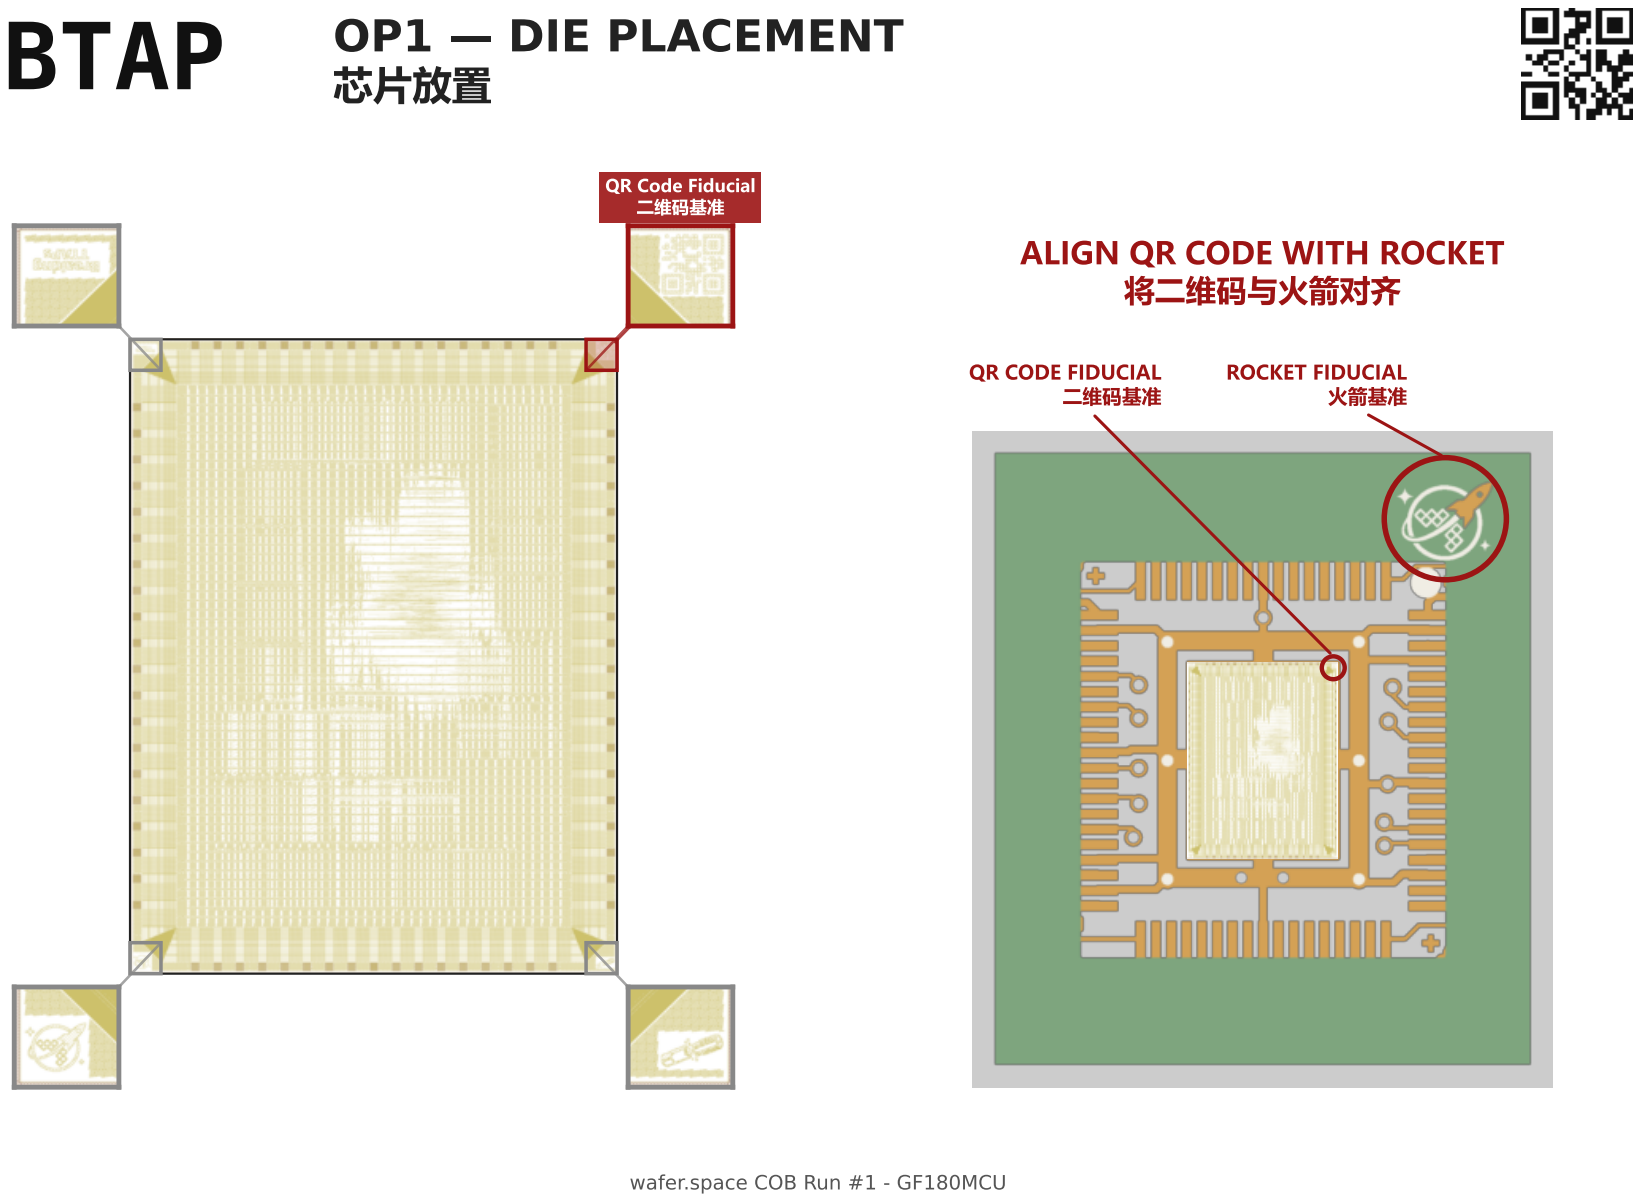
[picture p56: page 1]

# BTAP OP2 WIREBONDING

N

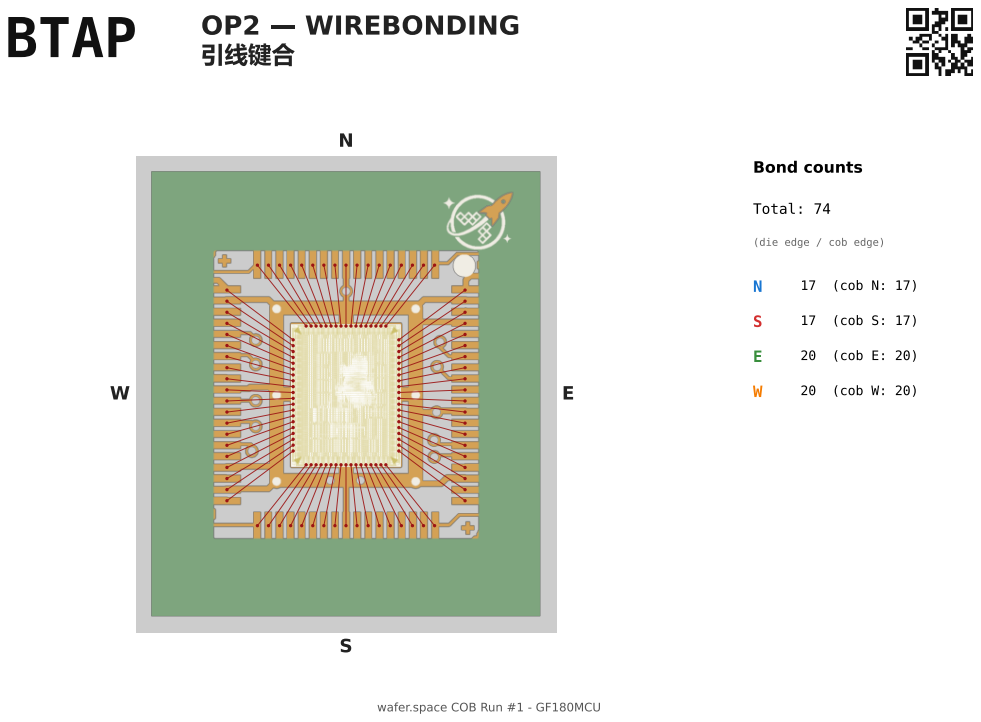
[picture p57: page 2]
Bond counts; Total: 74; N 17 (cob N: 17); S 17 (cob S: 17); E 20 (cob E: 20); W 20 (cob W: 20)

(die edge / cob edge)

wafer.space COB Run #1 - GF180MCU
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

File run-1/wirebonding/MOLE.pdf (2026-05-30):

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

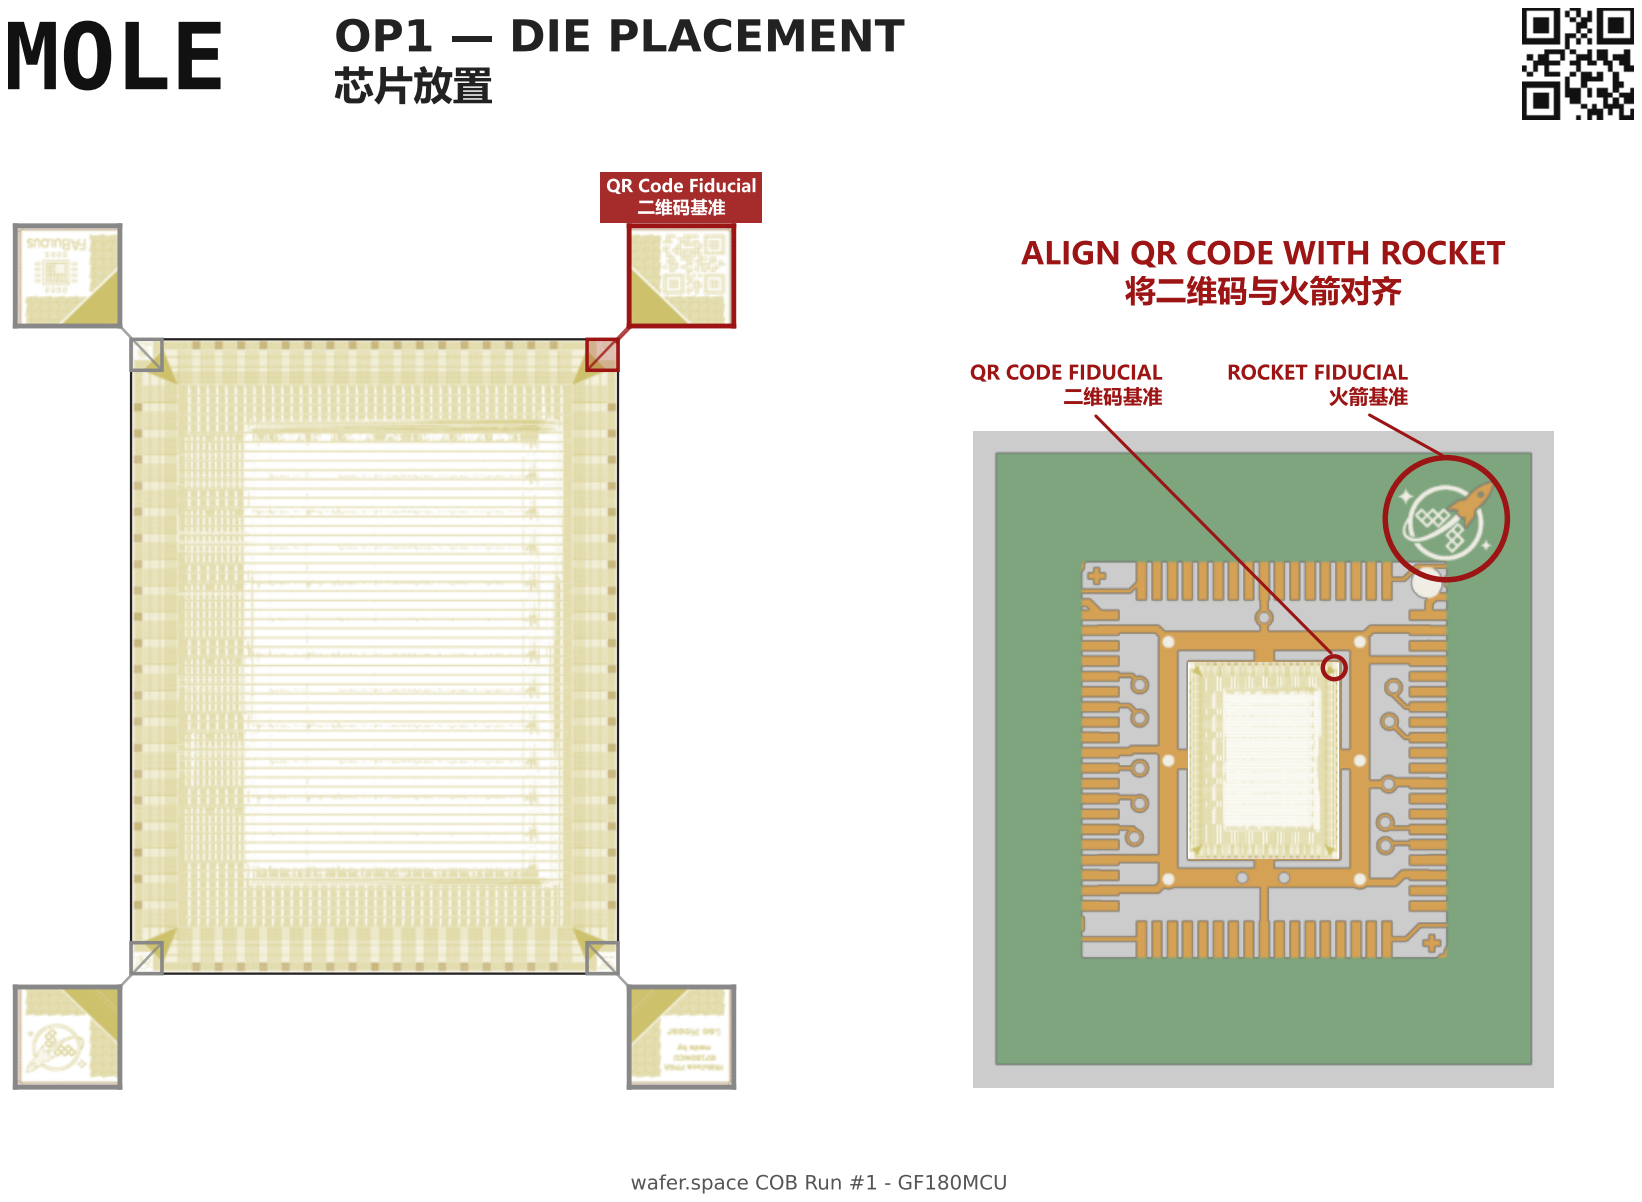
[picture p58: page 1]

# MOLE OP2 WIREBONDING

N

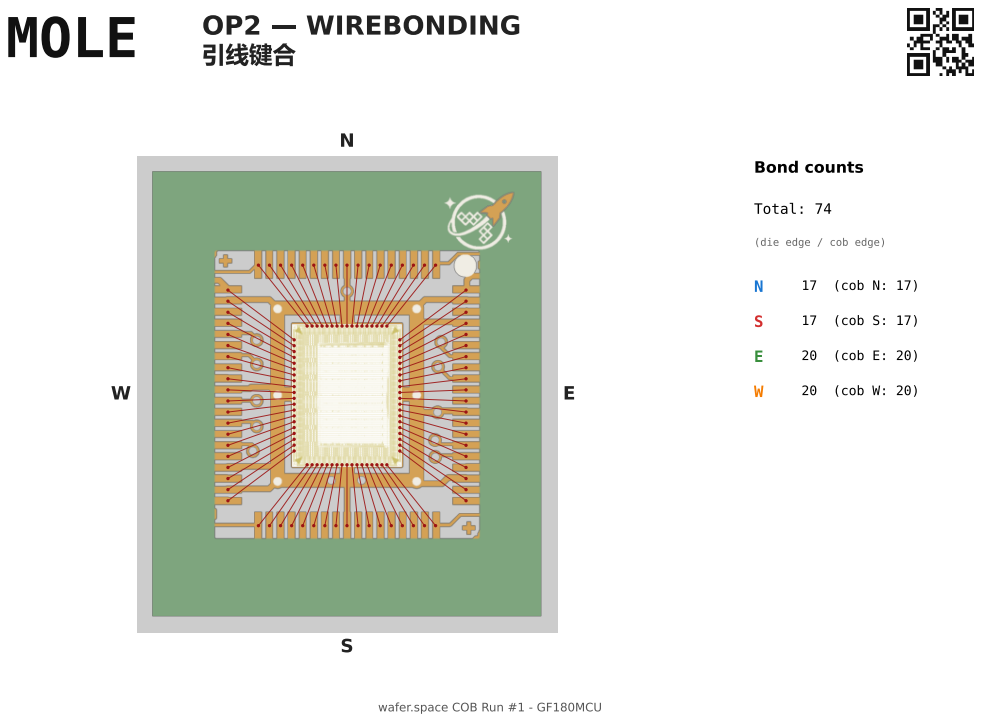
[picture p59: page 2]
Bond counts; Total: 74; N 17 (cob N: 17); S 17 (cob S: 17); E 20 (cob E: 20); W 20 (cob W: 20)

(die edge / cob edge)

wafer.space COB Run #1 - GF180MCU
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

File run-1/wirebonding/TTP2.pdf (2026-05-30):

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

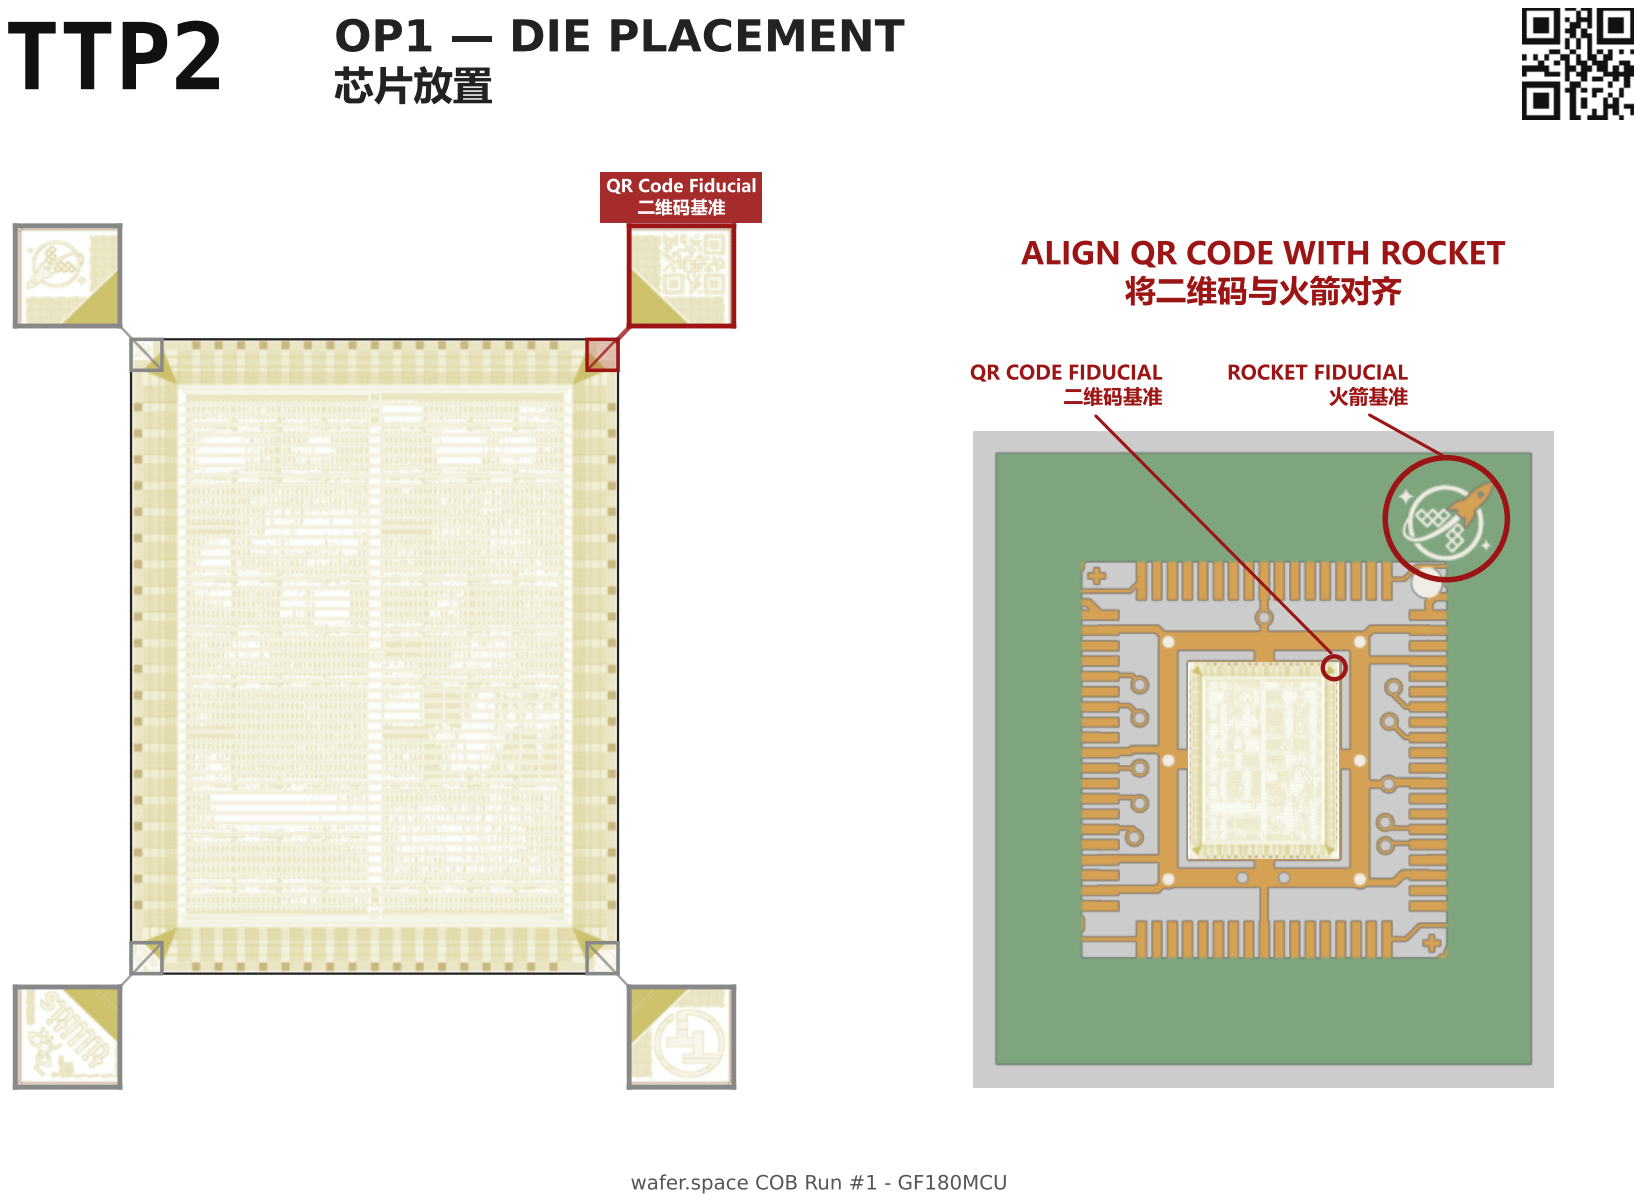
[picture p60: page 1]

# TTP2 OP2 WIREBONDING

N

Bond counts; Total: 74; N 17 (cob N: 17); S 17 (cob S: 17); E 20 (cob E: 20); W 20 (cob W: 20)

(die edge / cob edge)

wafer.space COB Run #1 - GF180MCU
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

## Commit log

2025-10-16 padring v0.1
    [mezzanine.kicad_pcb, mezzanine.kicad_sch, waferspace_cob.kicad_pcb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]
2025-10-19 70pin mezzanine added
    [mezzanine.kicad_pcb, mezzanine.kicad_sch]
2025-10-20 add motherboards
    [motherboards.kicad_pcb, motherboards.kicad_sch]
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2025-10-24 create more pretty symbols for mezzanine and padring
    [mezzanine.kicad_pcb, mezzanine.kicad_sch, motherboards.kicad_pcb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]
2025-10-24 broken wires
    [mezzanine.kicad_sch]
2025-11-02 add real 47pad cob version
    [74pad-70pin-mezzanine.kicad_pcb, 74pad-70pin-mezzanine.kicad_sch]
2025-11-07 update with kicad symbols
    [mezzanine.kicad_sch]
2025-11-23 pcb order sent with this
    [motherboards.kicad_pcb]
2026-03-12 new panel
    [74pad-70pin-mezzanine.kicad_pcb]
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2026-03-13 add bom and pos
    [panel-74pad-70pin-mezzanine-BOM.csv]
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2026-03-25 add pos
    [panel-74pad-70pin-mezzanine-bottom-pos.csv, panel-74pad-70pin-mezzanine-top-pos.csv]
2026-03-25 add more production
    [bom.csv, designators.csv, positions.csv]
2026-04-14 fix and add project code areas to panel
    [74pad-70pin-mezzanine.kicad_pcb, 74pad-70pin-mezzanine.kicad_sch, bom.csv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]
2026-04-18 1uF fix
    [bom.csv]
2026-04-19 fix edgecuts on panel
    [74pad-70pin-mezzanine.kicad_pcb]
2026-04-20 make v-cut lines bigger
    [panel-74pad-70pin-mezzanine-B_Cu.gbl, panel-74pad-70pin-mezzanine-B_Mask.gbs, panel-74pad-70pin-mezzanine-B_Paste.gbp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]
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2026-04-30 More 1x0p5 WIP
    [mezzanine-1x0p5.kicad_pcb, mezzanine-1x0p5.kicad_sch]
2026-04-30 Add 0p5x1
    [mezzanine-0p5x1.kicad_pcb, mezzanine-0p5x1.kicad_sch]
2026-04-30 create p5x1 padring
    [mezzanine-0p5x1.kicad_sch]
2026-04-30 1x0p5 routed
    [mezzanine-1x0p5.kicad_pcb, mezzanine-1x0p5.kicad_sch]
2026-04-30 Hide U102
    [mezzanine-1x0p5.kicad_pcb]
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2026-05-20 WIP 0p5x1 - probably need to try again
    [mezzanine-0p5x1.kicad_pcb, mezzanine-0p5x1.kicad_sch]
2026-05-20 Diagonal die
    [mezzanine-0p5x1.kicad_pcb, mezzanine-0p5x1.kicad_sch]
2026-05-29 main refactor
    [74pad-70pin-mezzanine.kicad_pcb, 74pad-70pin-mezzanine.kicad_sch, bom.csv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]
2026-05-29 update motherboards with new symbols
    [motherboards.kicad_pcb, motherboards.kicad_sch]
2026-05-29 rename 1x1 files
    [1x1-mezzanine.kicad_pcb, 1x1-mezzanine.kicad_sch]
2026-05-29 update readmes
    [motherboards.kicad_sch]
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2026-06-05 harmonize maotherboard pin naming
    [motherboards.kicad_pcb, motherboards.kicad_sch]
2026-06-16 fix pin numbering on motherboards
    [motherboards.kicad_pcb, motherboards.kicad_sch]
2026-07-11 create serial number space and repanelize with new panel shape
    [1x1-mezzanine.kicad_pcb, 1x1-mezzanine.kicad_sch, bom.csv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]
2026-07-15 Move 1x0p5 panelization to correct place
    [bom.csv, designators.csv, mezzanine-1x0p5.kicad_pcb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]
2026-07-15 First draft of 0p5x1 CoB
    [mezzanine-0p5x1.kicad_pcb, mezzanine-0p5x1.kicad_sch]
2026-07-16 Initial 0p5x0p5
    [0p5x0p5-cob.kicad_pcb, 0p5x0p5-cob.kicad_sch]
2026-07-17 TQVA CoB, tweaks
    [0p5x0p5-cob.kicad_pcb, 0p5x0p5-cob.kicad_sch, tqva-cob.kicad_pcb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]
2026-07-17 Update mask
    [mezzanine-1x0p5.kicad_pcb]
2026-07-17 Check symbols against template pad frame
    [0p5x0p5-cob.kicad_pcb, 0p5x0p5-cob.kicad_sch, mezzanine-0p5x1.kicad_pcb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]
2026-08-08 remove all opening bellow encapsulation region
    [0p5x0p5-cob.kicad_pcb, 0p5x0p5-cob.kicad_sch]
2026-08-09 make mazannine footprint pads longer to help solder
    [0p5x0p5-cob.kicad_pcb]
2026-08-09 update routing
    [0p5x0p5-cob.kicad_pcb]
2026-08-10 re-add gnd plane
    [0p5x0p5-cob.kicad_pcb]
2026-08-10 adding keep-out zone on F.Mask and F.SilkScreen on cob footprint
    [0p5x0p5-cob.kicad_pcb]
2026-08-10 undo mezannine pin resize back to 0.66mm
    [0p5x0p5-cob.kicad_pcb]
2026-08-10 remove no fill zones
    [0p5x0p5-cob.kicad_pcb]
2026-08-10 less wimpy gnd
    [0p5x0p5-cob.kicad_pcb]
2026-08-10 fix drc + fill zones + gnd vias added back
    [0p5x0p5-cob.kicad_pcb]
2026-08-11 widen rails on 1x1 panel
    [positions.csv]
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2026-08-25 fix silkscreen for name
    [panel.kicad_pcb, positions.csv]
2026-09-25 Run 2 half and full sized CoBs WIP
    Logos to match the position on the die
    Rotate 180 so die and CoB pin 1 position match
    Add label silkscreen to match 1x1
    1x0p5 wire bonds all <= 45 degrees
    1x0p5 pad order changed to be consistent between die and connector
    Remove soldermask between die and pads
    [1x1-mezzanine.kicad_pcb, 1x1-mezzanine.kicad_sch, mezzanine-0p5x1.kicad_pcb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]
2026-09-25 Remove vias from centre of 1x0p5
    Switch to 4 layers for 1x0p5
    [mezzanine-1x0p5.kicad_pcb]
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2026-10-04 update quarter slot pcb
    [0p5x0p5-cob.kicad_pcb]
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2026-10-04 refill zones, cleanup nets
    [0p5x0p5-cob.kicad_pcb]
2026-10-05 Remove vias from centre of 0p5x1 and 1x1
    [1x1-mezzanine.kicad_pcb, mezzanine-0p5x1.kicad_pcb, mezzanine-1x0p5.kicad_pcb]
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2026-10-05 Arrow marking, tweak ground flood on 1x1
    [1x1-mezzanine.kicad_pcb, mezzanine-0p5x1.kicad_pcb, mezzanine-1x0p5.kicad_pcb]
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2026-10-07 add pin1 fiducial to 1x1 and panelize
    [1x1-mezzanine.kicad_pcb, 1x1-mezzanine.kicad_sch, bom.csv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]
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2026-10-07 Matching pin 1 through hole on 1x1, 1x0p5, 0p5x1
    Remove unneded via annualar rings from 1x0p5 and 0p5x1
    [1x1-mezzanine.kicad_pcb, mezzanine-0p5x1.kicad_pcb, mezzanine-0p5x1.kicad_sch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]
2026-10-07 Widen some power/ground connections, add label to silkscreen
    [0p5x0p5-cob.kicad_pcb]
2026-10-07 edit vias to have annular rings on start/end layers only
    [0p5x0p5-cob.kicad_pcb]
2026-10-07 Add pin 1 fiducial to 0p5x0p5
    [0p5x0p5-cob.kicad_pcb, 0p5x0p5-cob.kicad_sch]
2026-10-08 add pin1 fiducial to 1x1
    [1x1-mezzanine.kicad_pcb]
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2026-10-08 fix 1x1 panel
    [panel.kicad_pcb, positions.csv]
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2026-10-09 reexport panels and fix f.mask on p5xp5
    [0p5x0p5-cob.kicad_pcb, panel.kicad_pcb, positions.csv]
2026-10-10 fix clearance violation
    [1x1-mezzanine.kicad_pcb, panel.kicad_pcb, positions.csv]
